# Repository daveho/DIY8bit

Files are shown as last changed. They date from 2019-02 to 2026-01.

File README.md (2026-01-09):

# DIY 8-bit computer video series

This repository has files and resources for the DIY 8-bit computer video series I am working on.

My youtube channel: <https://www.youtube.com/@davehohacks>

DIY 8-bit computer playlist: <https://www.youtube.com/playlist?list=PL9zJKV-F2eMyKY6qdesRQP_mAhBCMSw2T>

Some episodes have a specific subdirectory, e.g., `Episode02` for episode 2.

Feedback is welcome: <mailto:david.hovemeyer@gmail.com>.

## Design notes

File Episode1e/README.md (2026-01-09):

# Episode 1E

In this episode, I implement my
[FPGA VGA text display](https://github.com/daveho/FPGA_VGA)
design as a module for the 6809 system.

Link to video: <https://youtu.be/70fhRooNkK8>

The module (implemented using point to point wiring on
a protoboard):

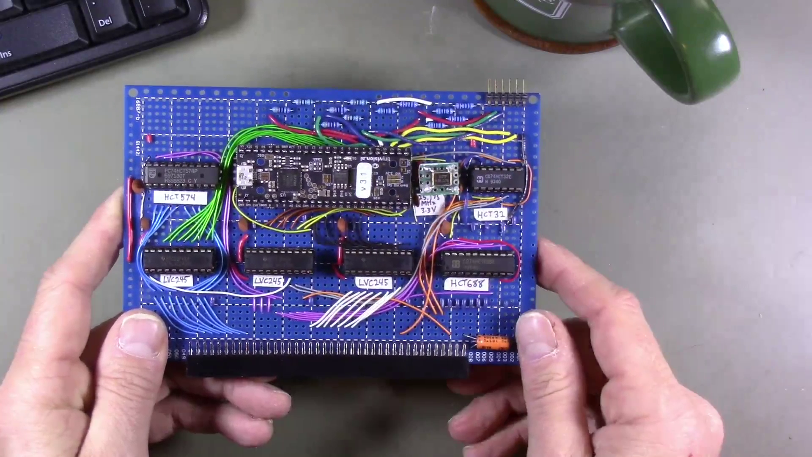
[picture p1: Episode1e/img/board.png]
picture of the VGA text display module


Picture of it working:

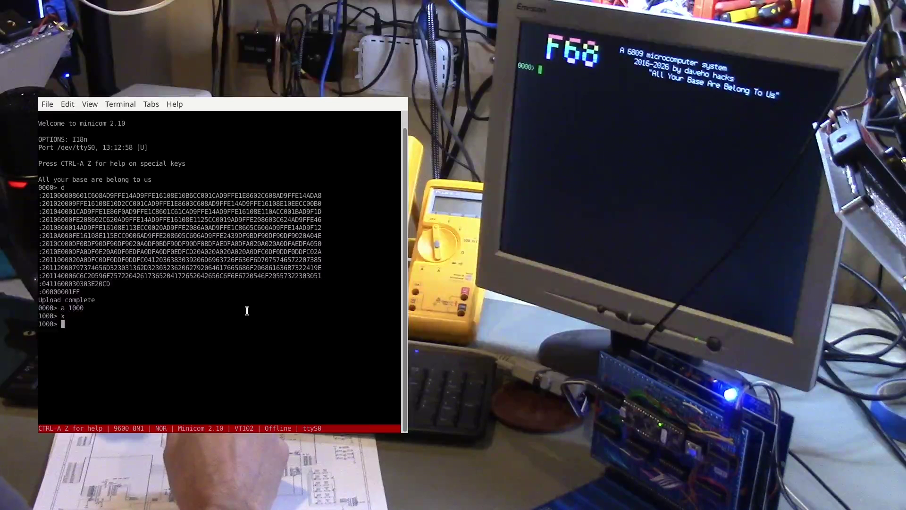
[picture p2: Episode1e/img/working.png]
picture of the text display working


The schematic is the "FPGADisplayController" sheet of
[the main schematic](../HardwareDesign).

The Verilog files are in the [FPGADisplayController](../FPGADisplayController)
directory.

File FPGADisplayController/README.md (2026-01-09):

# FPGA Display Controller

This directory contains the Verilog code for the 80x30 VGA
text display. (The schematic for the module is in the main
schematic, as the "FPGADisplayController" sheet.) It uses the
[Upduino 3](https://tinyvision.ai/products/fpga-development-board-upduino-v3-1)
development board.

To build and upload the design, run the commands

```text
apio verify
apio build
apio upload
```

I wrote a blog post about working with the Upduino 3 on Linux:

<https://daveho.github.io/2021/02/07/upduino3-getting-started-on-linux.html>

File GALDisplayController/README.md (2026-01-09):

# GAL-based VGA text display

This directory has a GAL-based VGA text display controller,
including a schematic and PCB. Although the design worked
as a hand-wired prototype consisting of six boards on a
backplane, I wasn't able to get the PCB version (which uses
mostly surface mount components) working.

The good news is that an FPGA-based version of the display
fully works. The schematic is in the "FPGADisplayController"
sheet of the main schematic in the [HardwareDesign](../HardwareDesign)
directory, and the Verilog code is in the
[FPGADisplayController](../FPGADisplayController) directory.

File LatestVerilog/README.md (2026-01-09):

# DIY 8-bit Computer, Episode 1D

**Update**: A working FPGA text display is now in the main
schematic as the "FPGADisplayController" sheet, and the
Verilog code is in the [FPGADisplayController](../FPGADisplayController)
directory. You can ignore everything in this directory.

The goal of this episode is to fully implement the display controller.
Desired features:

* 100 column by 37 row text mode
* 8x16 font (specifically, the [DOS ISO8 font](https://int10h.org/oldschool-pc-fonts/fontlist/font?ibm_dos_iso8))
* independent foreground and background colors for each displayed character,
  with a 256 color palette chosen from 4096 possible colors (RGB 444 truecolor)

## Status

In the [previous](../Episode1c) I was able to get character rendering to
work. However, it didn't support a full framebuffer, and there was
no support for character foreground and background colors, nor was there
a full framebuffer.

I'm just getting started on implementing the desired features
listed above.

## Experiments

* [Experiment 1](Experiment01): put the font data in SPRAM so that
  more block RAM is available for the framebuffer

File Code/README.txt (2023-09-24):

This directory has all of the code (firmware and programs)
for the F68 microcomputer.

The specific subdirectories are:

Include: assembly code used by both the ROM monitor and
programs is in this directory

Monitor: the ROM monitor, which is programmed to a 28C256
EEPROM and is what boots the microcomputer.

Keyboard: the firmware for the keyboard controller, which is
programmed to an 87C51 or 89C51 microcontroller.

Programs: various 6809 programs that can be assembled into
.hex files and loaded into RAM by the ROM monitor.

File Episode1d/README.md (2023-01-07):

# Episode 1D

Link to video: <https://youtu.be/MCGEp9laRh4>

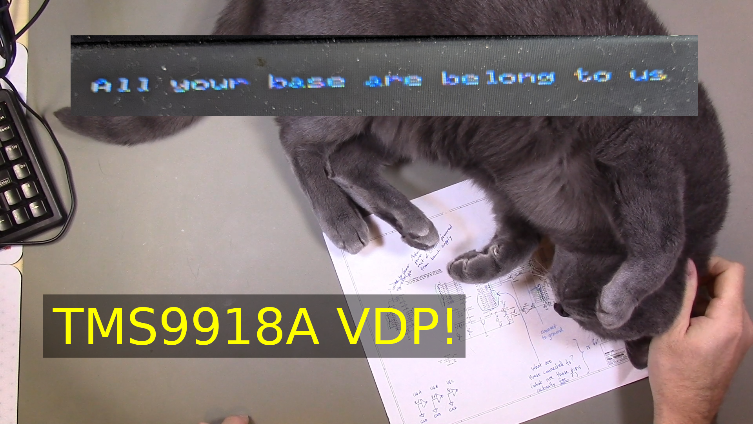
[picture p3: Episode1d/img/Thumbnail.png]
Cute cat picture


The goal of this episode is to experiment with a
[TMS9918A Video Display Processor](https://en.wikipedia.org/wiki/TMS9918)
and to attempt to use it as a display for the 6809 8-bit computer system.

With the TMS9918A providing a display, we're one step closer to the
6809 system being a fully independent computer.

An updated hardware design, including the schematic for the TMS9918A 
module, is in the [HardwareDesign](HardwareDesign) directory.

The updated monitor program, which initializes the TMS9918A and
displays a message, is in the [Code](Code) directory.

The demo circuit shown in the video, which I will be using as the
basis for the TMS9918A module, was created by Dr. Volt:

* Dr. Volt's TMS9918A project on Github: <https://github.com/michalin/TMS9918_Arduino>
* Dr. Volt's youtube channel: <https://www.youtube.com/@DoctorVolt>

I was inspired to try the TMS9918A based on a suggestion from
Troy Schrapel:

* Troy's 6502 system (which uses the TMS9918A): <https://visrealm.github.io/hbc-56/>
* Troy's youtube channel: <https://www.youtube.com/@TroySchrapel>

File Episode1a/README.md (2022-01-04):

# DIY 8-bit computer, Episode 1A

Link to video: <https://youtu.be/MTqwGI0u0LY>

In this video, I develop a host interface for the FPGA-based
display controller I started in [Episode 15](../Episode15).
You should probably watch that episode first!

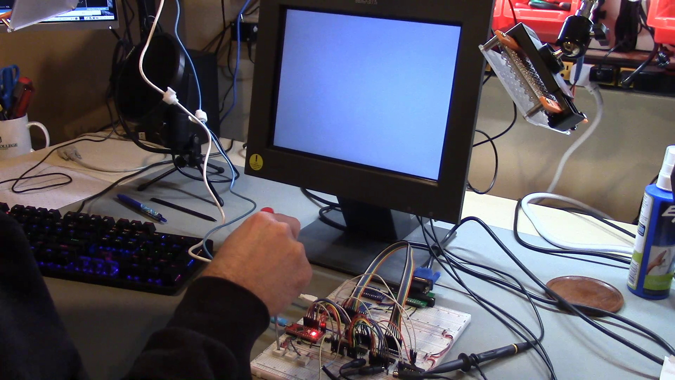
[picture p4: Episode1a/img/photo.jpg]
testing the display controller host interface


The [HardwareDesign](HardwareDesign) directory has the hardware
design (tested and verified working in this Episode.)
The schematics are (of course) developed using [KiCad](https://www.kicad.org/).

In the video, I mention creating a better resistor DAC.
The resistor DAC PCB you can see in the video can be found
here: <https://github.com/daveho/BreadboardDAC>.
I had the PCBs fabbed by [OSHPark](https://oshpark.com/),
and as usual they did an excellent job.  You should be
able to upload [BreadboardDAC.kicad\_pcb](https://github.com/daveho/BreadboardDAC/raw/master/BreadboardDAC.kicad_pcb) to OSHPark directly (no need to generate gerbers.)

The [Experiment01](Experiment01) through [Experiment05](Experiment05)
directories contain the FPGA designs for the various experiments
shown in the video. The FPGA board is an [Upduino 3.0](https://tinyvision.ai/products/upduino-v3-0),
based on the [Lattice ICE40 UP5k](https://www.latticesemi.com/Products/FPGAandCPLD/iCE40UltraPlus)
FPGA. It is programmed using the amazing [IceStorm](http://bygone.clairexen.net/icestorm/)
toolchain developed by [Claire Wolf](https://www.clairexen.net/).
I use [APIO](https://github.com/FPGAwars/apio) to orchestrate the
tools.  You can check out a
[blog post](http://daveho.github.io/2021/02/07/upduino3-getting-started-on-linux.html)
I wrote explaining how to get started programming the Upduino 3.0.
Some of the experiments include an Arduino Nano serving as a
proxy for the host system, in which case you will find an
`ArduinoSketch` directory with the firmware code.

The [Experiment01](Experiment01) directory adds a reset input to
the display controller. This will ensure that the display controller
starts in a known state when the system comes out of reset.

The [Experiment02](Experiment02) directory configures the FPGA with
the inputs and outputs needed to interface with the FIFO used for
communication with the host system, but doesn't actually do anything
with them.

The [Experiment02a](Experiment02a) and [Experiment02b](Experiment02b)
directories are based on Experiment02, but change the PLL configuration
so that different internal clock frequencies are used.

The [Experiment03](Experiment03) directory has the FPGA reading commands
from the host system via the FIFO.

The [Experiment04](Experiment04) directory has the FPGA using the low
4 bits of received commands to control the blue color component of
all generated pixels. The Arduino sents increasing count values,
so we get a nicely annoying flashing effect.

The [Experiment05](Experiment05) directory has the Arduino sending
commands to control the individual red, green, and blue color components
based on values read from three potentiometers connected to analog
inputs 0, 1, and 2.

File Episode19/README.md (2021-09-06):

# DIY 8-bit computer, Episode 19

Link to video: <https://youtu.be/RM4j6294dPY>

In this video, I assemble and test a PCB implementing the interrupt
and keyboard controllers.  I also fix minor issues with the handling
of end of line inputs and cursor movement in the ROM monitor program,
and assemble a new backplane.

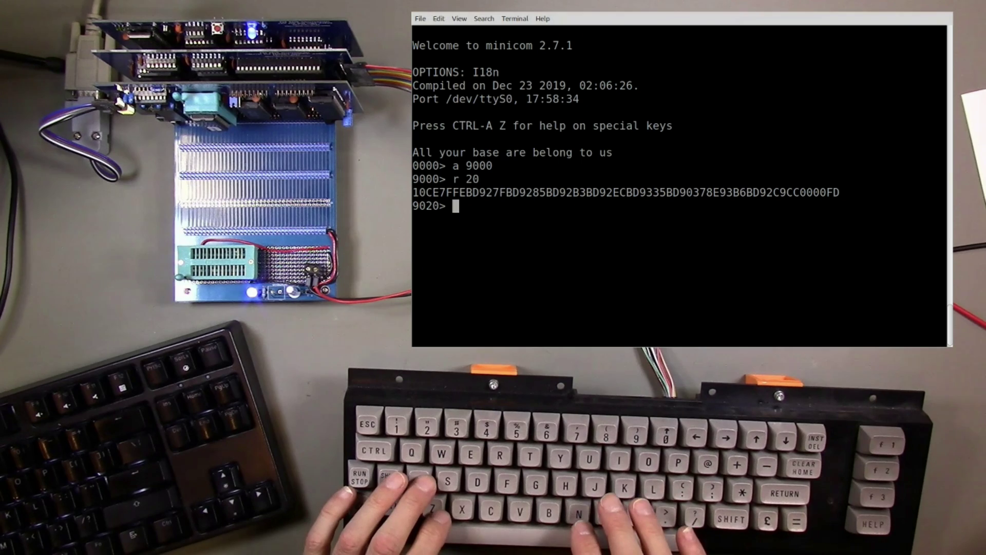
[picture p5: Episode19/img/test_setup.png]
testing the keyboard controller


The [Code](Code) directory has the updated ROM monitor code.

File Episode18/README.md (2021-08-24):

# DIY 8-bit computer, Episode 18

Link to video: <https://youtu.be/xi_Eh6LUsHY>

In this video, I assemble and test a PCB for the memory and peripherals module
for the F68 6809 computer system.  The PCB replaces the original hand-wired
prototype version of the module, and adds support for RS-232 serial
communication using a MAX232 transceiver chip.

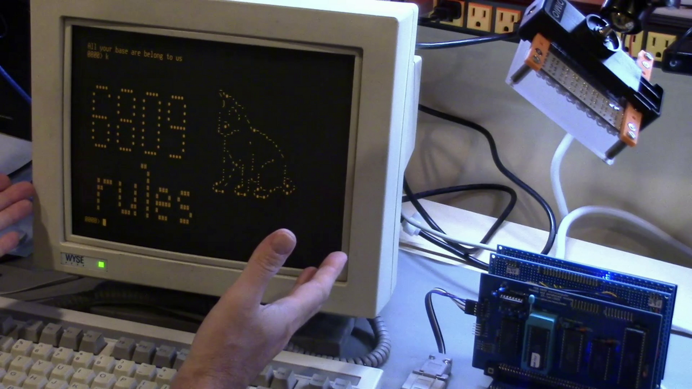
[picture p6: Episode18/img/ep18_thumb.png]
6809 system connected to a serial terminal


The [HardwareDesign](HardwareDesign) directory has the schematics and PCB
designs.  I updated the PCB design for the memory and peripherals module
to fix the minor issue I discovered in the video where one of the clock
inputs of the 82C54 timer/counter chip was not connected.

The [Code](Code) directory has the updated code for the monitor program,
which adds a `k` command to display some sweet ASCII art.

## Serial communication headers

The PCB has two 5-pin headers for serial communication.

The monitor program is hard-coded for 9600 bps, 8N1, so that's what the
remote (communicating) device should be configured for.

### Labeling of pins

Note that the silkscreen markings for the individual pins on the two
serial communications headers (TTL serial and RS-232) are
describing a signal of the *remote* device, i.e., the device that
the 6809 system will be communicating with.  For example, the pin labeled
`Rx` should be connected to the Rx (receive) input on the remote device, and
is driven by the Tx (transmit) pin on the 6809 system's 63B50 UART.

I hope this makes sense!

### TTL serial header

The header labeled "TTL serial" uses standard TTL-level signals.

The TTL serial header may be connected to a USB serial adapter as follows:

TTL serial header pin | USB serial adapter pin
--------------------- | ----------------------
GND                   | GND
RTS                   | RTS
CTS                   | CTS
Rx                    | Rx
Tx                    | Tx

### RS-232 header

The header labeled "RS-232" uses a MAX232 chip for serial communication using
RS-232 level signals.  As with the "TTL serial" header, the silkscreen labels
for the pins refer to the remote device, not the 6809 system.

How these header pins are connected will depend on two factors:

* whether the remote device is DTE (Data Terminal Equipment) or DCE (Data
  Communication Equipment)
* whether the RS-232 cable is straight through or null modem

PCs and serial terminals are both DTE devices.

The following tables show how to write the 5-pin RS-232 header on the PCB
to a 9-pin (D-sub) serial connector.

For connection to a DTE device using a straight-through cable, or a DCE device
using a null modem cable:

RS-232 header pin | Serial connector pin
----------------- | --------------------
GND               | 5
RTS               | 7
CTS               | 8
Rx                | 2
Tx                | 3

For connection to a DCE device using a straight-through cable, or a DTE
device using a null modem cable:

RS-232 header pin | Serial connector pin
----------------- | --------------------
GND               | 5
RTS               | 8
CTS               | 7
Rx                | 3
Tx                | 2

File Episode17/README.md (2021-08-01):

# DIY 8-bit computer, Episode 17

Link to video: <https://youtu.be/EEec0VQM-kc>

This is a quick video in which I test a revised version of the
CPU and glue logic module PCB for the F68 6809-based microcomputer system.
The revision fixes several problems I found with the original board
revision in the [previous episode](../Episode16).

The [HardwareDesign](HardwareDesign) directory has complete schematics and
PCB designs.

Note that the [Mechanical](../Episode16/Mechanical) directory from
the previous episode has the 3D designs for the mounting clips that secure the
backplane connector to the PCB.

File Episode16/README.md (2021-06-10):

# DIY 8-bit computer, Episode 16

Link to video: <https://youtu.be/gSi9ksZn5Jk>

In this video, I choose the name "F68" for the 6809 computer system,
and debug and test a new PCB for the CPU and glue logic module.
There are some mistakes in the PCB layout that cause some problems,
but eventually everything works.

The [HardwareDesign](HardwareDesign) directory has the updated
schematics and the PCB layout.  Note that the [CPUandGlueLogic.kicad\_pcb](CPUandGlueLogic.kicad_pcb)
file has fixes for the PCB layout issues discussed in the episode.
The [gerbers\_cpu](HardwareDesign/gerbers_cpu) subdirectory has the gerber
files for the updated (fixed) board layout. Note: do *not* populate resistor
network R101, it seems to cause problems (as noted towards the end of
the video.)

The [Mechanical](Mechanical) directory has the design for the 3D-printable clips
to more firmly attach the backplane connector (which is a 2x40 right angle female pin header)
to the PCB.

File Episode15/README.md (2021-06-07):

# DIY 8-bit computer, Episode 15

Link to video: <https://youtu.be/5xY3-Er72VU>

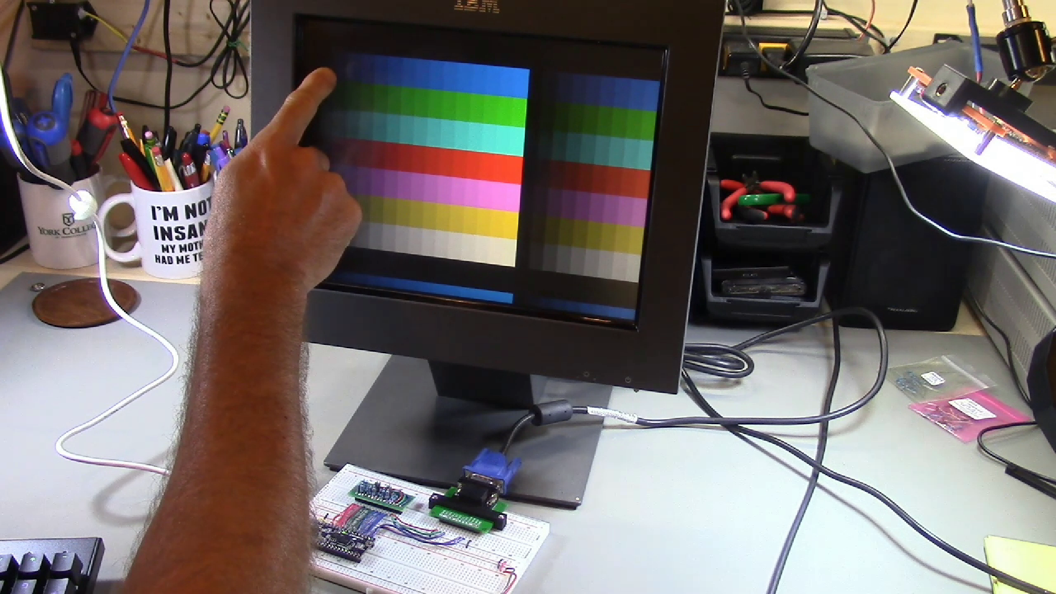
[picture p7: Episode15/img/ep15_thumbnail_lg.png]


In this video, I evaluate possibilities for adding a display to the 8-bit
computer, and perform some initial experiments to generate an 800x600 SVGA
signal using an FPGA.

The FPGA board I am using is the [Upduino 3.0](https://tinyvision.ai/products/upduino-v3-0),
which uses the [Lattice UltraPlus ICE40UP5K](https://www.latticesemi.com/en/Products/FPGAandCPLD/iCE40UltraPlus)
FPGA.  One great advantage of this FPGA family is that it can be programmed using
the Open Source [IceStorm](http://www.clifford.at/icestorm/) toolchain.
I am using [apio](https://github.com/FPGAwars/apio) as a front-end for the
FPGA tools.

I wrote a blog post describing how to set up a development environment for
the Upduino 3.0: <https://daveho.github.io/2021/02/07/upduino3-getting-started-on-linux.html>

The schematic for the test circuit is in the [HardwareDesign](HardwareDesign)
directory, in the sheet called `Display`.  There is a PDF of the schematic,
[F68.pdf](HardwareDesign/F68.pdf).  (The overall system is going to be called
"F68", I will talk about this in a future video.)

The following directories have code for the various FPGA experiments:

* [Experiment01](Experiment01): generate a 6 MHz square wave using the
  internal high-frequency oscillator
* [Experiment02](Experiment02): generate a 1.875 MHz square wave using
  the internal high-freqency oscillator and a PLL
* [Experiment03](Experiment03): generate a 6 MHz square wave using the
  on-board 12 MHz oscillator (the internal high-frequency oscillator is
  not very accurate)
* [Experiment04](Experiment04): generate a 1.875 MHz square wave using
  the 12 MHz oscillator and a global clock buffer
* [Experiment05](Experiment05): generate 800x600 60 video displaying
  a solid color
* [Experiment06](Experiment06): generate a 800x600 test pattern showing
  color gradients, in order to evaluate the 4 bit resistor DACs used for
  converting the digital outputs to analog color voltages
  (this is what you see in the photo above)

Other directories:

* [DAC](DAC): has a [Qucs](http://qucs.sourceforge.net/) simulation of the
  resistor DAC design, and a [Gnumeric](http://www.gnumeric.org/) spreadsheet
  showing the voltages generated by a test circuit for each digital input
  value
* [Mechanical](Mechanical): has a 3D-printable bracket that attaches to the
  VGA breakout board I'm using in order to give it some additional support
  on the breadboard (to avoid putting unnecessary stress on the header pins)

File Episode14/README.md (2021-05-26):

# DIY 8-bit computer, Episode 14

Link to video: <https://youtu.be/gVFuNtl8WqU>

In this video, I present plans for an enclosure for the 8 bit computer system,
and build a frame for the enclosure which includes a card cage to stabilze
the backplane cards.

The frame for the enclosure is built using 15x15mm aluminum extrusions, specifically
[MakerBeam XL](https://www.makerbeam.com/makerbeamxl/).  [OpenBeam](https://www.makerbeam.com/openbeam/)
is the same profile, but does not have threaded holes at the ends of the beam (which are needed
to use the corner connectors.)

Pictures of the frame:

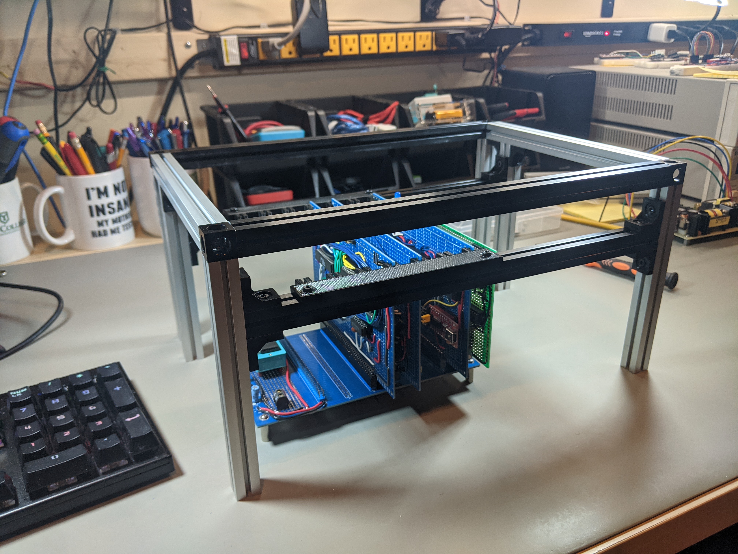
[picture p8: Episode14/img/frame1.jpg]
enclosure frame


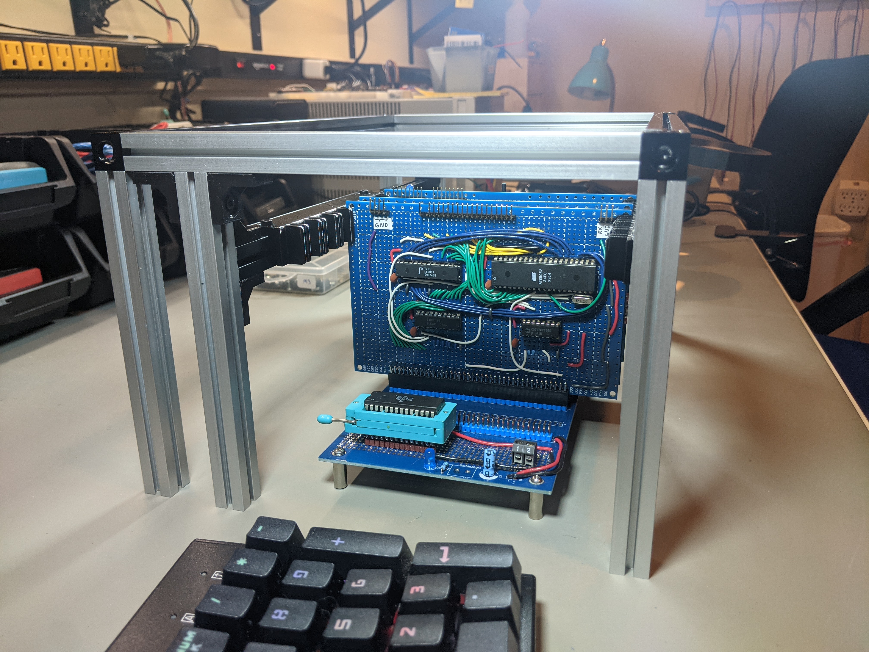
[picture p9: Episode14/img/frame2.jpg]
enclosure frame


Two 3D printed parts are used.

* [lbracket.stl](lbracket.stl): OpenBeam corner brace, from <https://www.thingiverse.com/thing:29794>, design by [brucethehoon](https://www.thingiverse.com/brucethehoon), [CC-BY-SA 3.0](https://creativecommons.org/licenses/by-sa/3.0/)
* [CardGuide.stl](CardGuide.stl)/[CardGuide.scad](CardGuide.scad): card guide, designed by [me](https://github.com/daveho), [CC-BY-SA 3.0](https://creativecommons.org/licenses/by-sa/3.0/)

Parts list for frame:

Quantity | Description/link
:------: | ----------------
6        | [150mm MakerBeam XL](https://www.amazon.com/MakerBeam-XL-anodized-150x15x15mm-103150/dp/B06XJ4FV75)
2        | [200mm MakerBeam XL](https://www.amazon.com/MakerBeam-XL-Anodized-200x15x15mm-Pieces/dp/B06XHQH9WH)
4        | [300mm MakerBeam XL](https://www.amazon.com/MakerBeam-300mm-beam-black-anodised/dp/B00G2DNU4M)
4        | [MakerBeam XL corner cube](https://www.amazon.com/Makerbeam-XL-Corner-Black-15x15x15mm/dp/B06XJ3RYZ4)
40       | [6mm M3 bolt](https://www.amazon.com/gp/product/B07CMRQ3TB)
40       | [Square 5x5x2 mm M3 nut](https://www.amazon.com/gp/product/B089Q6C4CM)
12       | [3D printed OpenBeam corner brace](lbracket.stl)
2        | [Card Guide](CardGuide.stl)

Note that you can use the [MakerBeam XL T-Slot nuts](https://www.amazon.com/gp/product/B06XHQHD4H)
rather than the square M3 nuts, but they are very expensive.

Here is a 3D-printable corner cube, which might be worth considering because the
MakerBeam XL metal ones are expensive: <https://www.thingiverse.com/thing:3189420>

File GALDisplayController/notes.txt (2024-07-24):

June 18, 2024

VCOUNT_INCR input of VCount module should be driven by HEndPulse signal
rather than HBeginPulse signal. This will allow once-per-line register
updates in the Readout module to happen before VCOUNT is incremented.
This will require a hardware mod!

June 19, 2024

Need to update VCntCtrl.pld to generate VEActive (VEndActive) signal
(pin 20.)

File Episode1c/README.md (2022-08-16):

# Episode 1C

Link to video: <https://youtu.be/Fw6ido_NeqQ>

The goal of this episode is to have the display controller display
characters as 800x600 SVGA video, with the Arduino (standing in for
the host system) uploading font and character data to the
display controller's block RAM.

Spoiler: it worked.

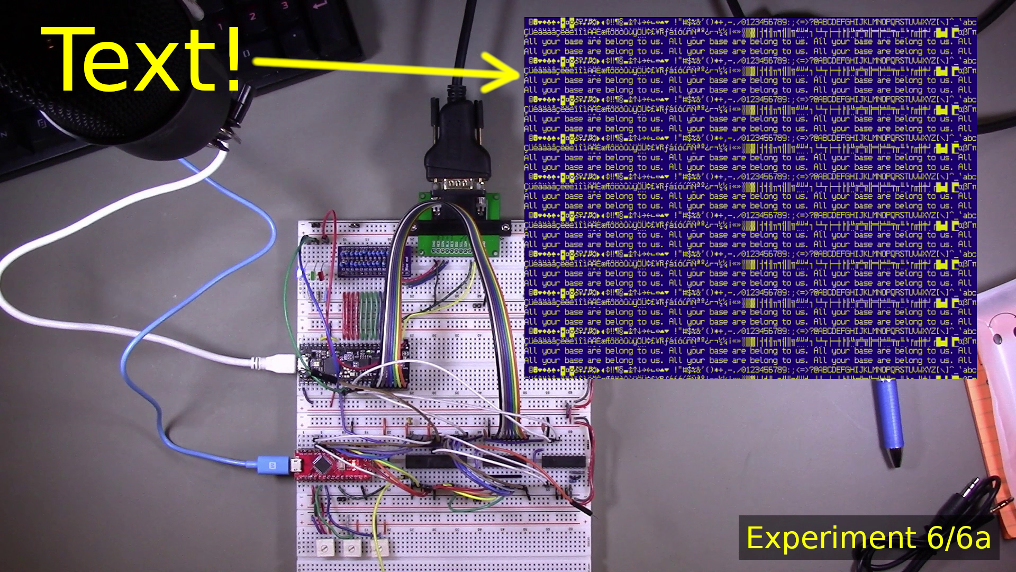
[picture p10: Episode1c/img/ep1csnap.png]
snapshot from the video


The experiment directories (linked below) have the Verilog and Arduino
code.  The hardware design the same as [Episode 1A](../Episode1a).

## Summary of experiments

[Experiment 1](Experiment01): Change core FPGA clock frequency to 39.75 MHz because
an update to the IceStorm tools caused the design to not synthesize
correctly at 80 MHz.  This is ok, since pipelining should completely
obviate the need for a fast clock.

[Experiment 2](Experiment02): Generate 8 pixels at a time from a single 8 bit register.
The idea is that this is the last stage in the video output.
(Eventually we'll need to add support for foreground/background
colors, but they can just be stored in a different register.)

[Experiment 3](Experiment03): Begin to implement a command protocol. The basic format
is a single command byte followed by 1 or more additional data bytes.
This required quite a bit of time to get working because the
`shared_reg` module had a bug where the consumer would see a data
byte twice due to the way the data available flag was updated.
Was able to figure this out using the oscilloscope: it was clear
that the same data byte was being consumed twice.

[Experiment 4](Experiment04): Have the host upload 8x16 VGA font data to block RAM.

[Experiment 5](Experiment05): Have the host upload character data to block RAM, and
attempt to render it as characters. This *sort of* works. Definitely
some recognizable characters are displayed, but they're not quite in
the expected places on the screen.

[Experiment 6](Experiment06): try to get all of the characters to display at precisely
the correct locations.

Experiment 6a: this was done to support Experiment 6. It became clear
that the hsync and vsync generation and hcount/vcount generation was
not placing pixels in the correct locations. In this experiment, the
output was a grid with horizontal and vertical lines every 16 pixels.
By adjusting hsync and vcount (as exposed to the main module), we were
able to make hcount==0 the exact left row, and vcount==0 the exact
top row. (I think! It still seems like only 799 columns are being
displayed.)

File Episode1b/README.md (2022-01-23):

# DIY 8-bit computer, Episode 1B

Link to video: <https://youtu.be/UeyVLJ2qZhI>

In this video, I discuss an approach for making the display controller
design work.  (We started the display controller in
[Epsiode15](../Episode15) and continued it in [Episode1A](../Episode1a).)
We also incorporate a block RAM into the design.

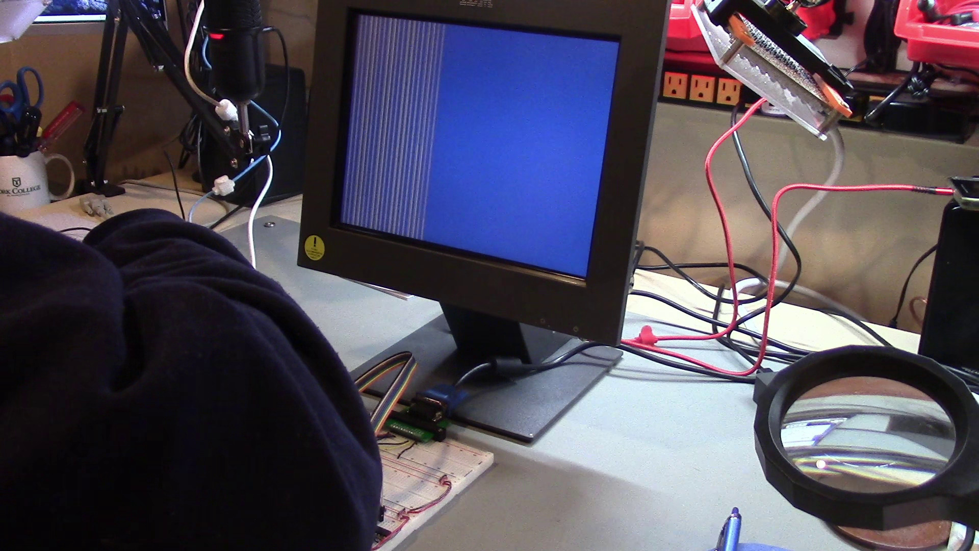
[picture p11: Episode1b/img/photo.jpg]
displaying ugly lines on a VGA monitor


The hardware design is the same as in the [previous episode](../Episode1a).

The [Experiment01](Experiment01) and [Experiment02](Experiment02) directories
were intermediate stages of a general cleanup and modularization of the
Verilog code for the display controller.

The [Experiment03](Experiment03) directory has the Verilog code which
places command bytes sent by the simulated host system into a block RAM,
which in turn is used to generate a pattern of foreground and background
pixels on each generated raster line.  Even though it's not too impressive
to look at, it proves that we can get data into the FPGA and use it to
render display output, which is a pretty significant step.

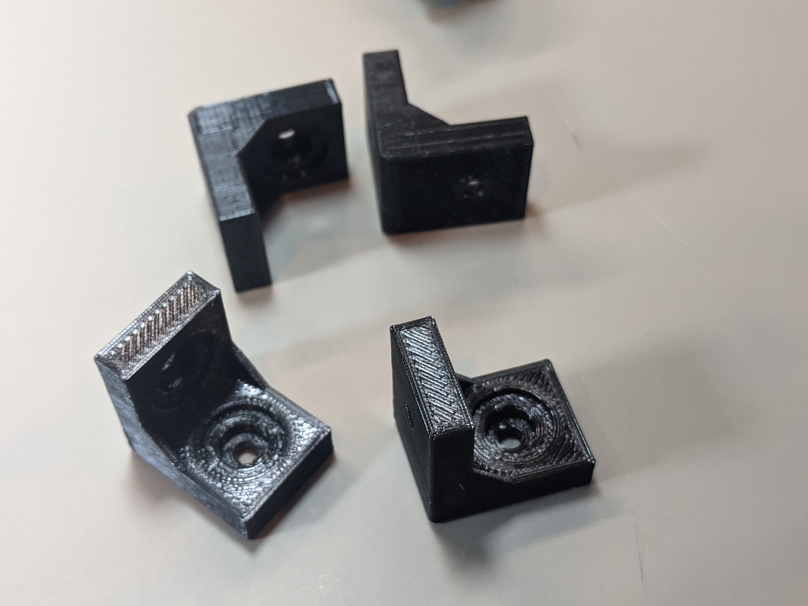
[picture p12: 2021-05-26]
Mechanical/img/right_angle.jpg

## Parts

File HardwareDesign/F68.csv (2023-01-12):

Source: | /home/daveho/git/DIY8bit/HardwareDesign/F68.kicad_sch
Date: | Thu 12 Jan 2023 06:23:54 PM EST
Tool: | Eeschema 6.0.10-86aedd382b~118~ubuntu20.04.1
Generator: | /usr/share/kicad/plugins/bom_csv_grouped_by_value.py
Component Count: | 175
Individual Components:
Item | Qty | Reference(s) | Value | LibPart | Footprint | Datasheet | Comment | Field4 | Field5 | Field6 | Field7 | Field8 | MANUFACTURER | MAXIMUM_PACKAGE_HEIGHT | PARTREV | STANDARD
 |  | C001 | 22μF | device:CP | Capacitor_THT:CP_Radial_D6.3mm_P2.50mm
 |  | C101 | 0.1 uF | device:C | Capacitor_THT:C_Disc_D5.0mm_W2.5mm_P2.50mm
 |  | C102 | 0.1 uF | device:C | Capacitor_THT:C_Disc_D5.0mm_W2.5mm_P2.50mm
 |  | C103 | 0.1 uF | device:C | Capacitor_THT:C_Disc_D5.0mm_W2.5mm_P2.50mm
 |  | C104 | 0.1 uF | device:C | Capacitor_THT:C_Disc_D5.0mm_W2.5mm_P2.50mm
 |  | C105 | 0.1 uF | device:C | Capacitor_THT:C_Disc_D5.0mm_W2.5mm_P2.50mm
 |  | C106 | 0.1 uF | device:C | Capacitor_THT:C_Disc_D5.0mm_W2.5mm_P2.50mm
 |  | C107 | 0.1 uF | device:C | Capacitor_THT:C_Disc_D5.0mm_W2.5mm_P2.50mm
 |  | C108 | 0.1 uF | device:C | Capacitor_THT:C_Disc_D5.0mm_W2.5mm_P2.50mm
 |  | C109 | 0.1 uF | device:C | Capacitor_THT:C_Disc_D5.0mm_W2.5mm_P2.50mm
 |  | C110 | 0.1 uF | device:C | Capacitor_THT:C_Disc_D5.0mm_W2.5mm_P2.50mm
 |  | C111 | 0.1 uF | device:C | Capacitor_THT:C_Disc_D5.0mm_W2.5mm_P2.50mm
 |  | C113 | 22 pF | device:C | Capacitor_THT:C_Disc_D3.8mm_W2.6mm_P2.50mm
 |  | C114 | 22 pF | device:C | Capacitor_THT:C_Disc_D3.8mm_W2.6mm_P2.50mm
 |  | C200 | 0.1 uF | device:C | Capacitor_THT:C_Disc_D5.0mm_W2.5mm_P2.50mm
 |  | C201 | 0.1 uF | device:C | Capacitor_THT:C_Disc_D5.0mm_W2.5mm_P2.50mm
 |  | C301 | 0.1 μF | device:C | Capacitor_THT:C_Disc_D5.0mm_W2.5mm_P2.50mm
 |  | C302 | 0.1 μF | device:C | Capacitor_THT:C_Disc_D5.0mm_W2.5mm_P2.50mm
 |  | C303 | 0.1 μF | device:C | Capacitor_THT:C_Disc_D5.0mm_W2.5mm_P2.50mm
 |  | C304 | 1μF | device:CP | Capacitor_THT:CP_Radial_Tantal_D5.0mm_P5.00mm
 |  | C305 | 1μF | device:CP | Capacitor_THT:CP_Radial_Tantal_D5.0mm_P5.00mm
 |  | C306 | 1μF | device:CP | Capacitor_THT:CP_Radial_Tantal_D5.0mm_P5.00mm
 |  | C307 | 1μF | device:CP | Capacitor_THT:CP_Radial_Tantal_D5.0mm_P5.00mm
 |  | C308 | 1μF | device:CP | Capacitor_THT:CP_Radial_Tantal_D5.0mm_P5.00mm
 |  | C401 | 0.1 μF | device:C | Capacitor_THT:C_Disc_D5.0mm_W2.5mm_P2.50mm
 |  | C402 | 0.1 μF | device:C | Capacitor_THT:C_Disc_D5.0mm_W2.5mm_P2.50mm
 |  | C403 | 0.1 μF | device:C | Capacitor_THT:C_Disc_D5.0mm_W2.5mm_P2.50mm
 |  | C404 | 0.1 μF | device:C | Capacitor_THT:C_Disc_D5.0mm_W2.5mm_P2.50mm
 |  | C405 | 0.1 μF | device:C | Capacitor_THT:C_Disc_D5.0mm_W2.5mm_P2.50mm
 |  | C406 | 0.1 μF | device:C | Capacitor_THT:C_Disc_D5.0mm_W2.5mm_P2.50mm
 |  | C407 | 0.1 μF | device:C | Capacitor_THT:C_Disc_D5.0mm_W2.5mm_P2.50mm
 |  | C501 | 0.1 μF | device:C | Capacitor_THT:C_Disc_D5.0mm_W2.5mm_P2.50mm
 |  | C502 | 0.1 μF | device:C | Capacitor_THT:C_Disc_D5.0mm_W2.5mm_P2.50mm
 |  | C503 | 0.1 μF | device:C | Capacitor_THT:C_Disc_D5.0mm_W2.5mm_P2.50mm
 |  | C504 | 0.1 μF | device:C | Capacitor_THT:C_Disc_D5.0mm_W2.5mm_P2.50mm
 |  | C505 | 30pF | device:C | Capacitor_THT:C_Disc_D3.8mm_W2.6mm_P2.50mm
 |  | C506 | 30pF | device:C | Capacitor_THT:C_Disc_D3.8mm_W2.6mm_P2.50mm
 |  | C701 | 100 nF | device:C | Capacitor_THT:C_Disc_D3.4mm_W2.1mm_P2.50mm
 |  | C702 | 100 nF | device:C | Capacitor_THT:C_Disc_D3.4mm_W2.1mm_P2.50mm
 |  | C703 | 100 nF | device:C | Capacitor_THT:C_Disc_D3.4mm_W2.1mm_P2.50mm
 |  | C704 | 100 nF | device:C | Capacitor_THT:C_Disc_D3.4mm_W2.1mm_P2.50mm
 |  | C705 | 100 nF | device:C | Capacitor_THT:C_Disc_D3.4mm_W2.1mm_P2.50mm
 |  | C706 | 100 nF | device:C | Capacitor_THT:C_Disc_D3.4mm_W2.1mm_P2.50mm
 |  | C707 | 100 nF | device:C | Capacitor_THT:C_Disc_D3.4mm_W2.1mm_P2.50mm
 |  | C710 | 22 pF | device:C | Capacitor_THT:C_Disc_D3.4mm_W2.1mm_P2.50mm
 |  | C711 | 22 pF | device:C | Capacitor_THT:C_Disc_D3.4mm_W2.1mm_P2.50mm
 |  | C801 | 100 nF | device:C | Capacitor_THT:C_Disc_D3.4mm_W2.1mm_P2.50mm
 |  | C802 | 100 nF | device:C | Capacitor_THT:C_Disc_D3.4mm_W2.1mm_P2.50mm
 |  | C803 | 100 nF | device:C | Capacitor_THT:C_Disc_D3.4mm_W2.1mm_P2.50mm
 |  | C804 | 100 nF | device:C | Capacitor_THT:C_Disc_D3.4mm_W2.1mm_P2.50mm
 |  | C805 | 2.2 uF | device:C | Capacitor_THT:C_Rect_L7.0mm_W4.5mm_P5.00mm
 |  | C806 | 2.2 uF | device:C | Capacitor_THT:C_Rect_L7.0mm_W4.5mm_P5.00mm
 |  | D100 | LED | device:LED | LED_THT:LED_D5.0mm
 |  | D601 | LED | device:LED | LED_THT:LED_D5.0mm
 |  | D602 | LED | device:LED | LED_THT:LED_D5.0mm
 |  | D603 | LED | device:LED | LED_THT:LED_D5.0mm
 |  | J001 | Conn_02x40_Odd_Even | Connector_Generic:Conn_02x40_Odd_Even | Connector_PinHeader_2.54mm:PinHeader_2x40_P2.54mm_Vertical | ~
 |  | J100 | Conn_01x02 | Connector_Generic:Conn_01x02 | Connector_PinHeader_2.54mm:PinHeader_1x02_P2.54mm_Vertical | ~
 |  | J201 | Conn_01x03 | Connector_Generic:Conn_01x03 | Connector_PinHeader_2.54mm:PinHeader_1x03_P2.54mm_Vertical | ~
 |  | J303 | Conn_01x05 | Connector_Generic:Conn_01x05 | Connector_PinHeader_2.54mm:PinHeader_1x05_P2.54mm_Vertical | ~
 |  | J304 | Conn_01x05 | Connector_Generic:Conn_01x05 | Connector_PinHeader_2.54mm:PinHeader_1x05_P2.54mm_Vertical | ~
 |  | J305 | Conn_01x09 | Connector_Generic:Conn_01x09 | Connector_PinHeader_2.54mm:PinHeader_1x09_P2.54mm_Vertical | ~
 |  | J306 | Conn_01x09 | Connector_Generic:Conn_01x09 | Connector_PinHeader_2.54mm:PinHeader_1x09_P2.54mm_Vertical | ~
 |  | J501 | Conn_01x20 | Connector_Generic:Conn_01x20 | Connector_PinHeader_2.54mm:PinHeader_1x20_P2.54mm_Vertical | ~
 |  | J503 | Conn_01x02 | Connector_Generic:Conn_01x02 | Connector_PinHeader_2.54mm:PinHeader_1x02_P2.54mm_Vertical | ~
 |  | J601 | Conn_01x12 | Connector_Generic:Conn_01x12 | Connector_PinHeader_2.54mm:PinHeader_1x12_P2.54mm_Vertical | ~
 |  | J701 | RCJ-044 | RCJ-044:RCJ-044 | CUI_RCJ-044:CUI_RCJ-044 |  |  |  |  |  |  |  | CUI Devices | 11.6 mm | 1.02 | Manufacturer Recommendations
 |  | J702 | Conn_01x02 | Connector_Generic:Conn_01x02 | Connector_PinHeader_2.54mm:PinHeader_1x02_P2.54mm_Vertical | ~
 |  | J801 | Conn_01x02 | Connector_Generic:Conn_01x02 | Connector_PinHeader_2.54mm:PinHeader_1x02_P2.54mm_Vertical | ~
 |  | J802 | Conn_02x09_Odd_Even | Connector_Generic:Conn_02x09_Odd_Even | Connector_PinHeader_2.54mm:PinHeader_2x09_P2.54mm_Vertical | ~
 |  | J803 | SJ1-3525N | SJ1-3525N:SJ1-3525N | CUI_SJ1-3525N |  |  |  |  |  |  |  | CUI |  | 1.02 | Manufacturer recommendation
 |  | Q701 | 2N4401 | device:Q_NPN_EBC | Package_TO_SOT_THT:TO-92_HandSolder
 |  | R100 | R | device:R | Resistor_THT:R_Axial_DIN0204_L3.6mm_D1.6mm_P7.62mm_Horizontal
 |  | R101 | 4k7 | device:R | Resistor_THT:R_Axial_DIN0204_L3.6mm_D1.6mm_P7.62mm_Horizontal
 |  | R102 | 4k7 | device:R | Resistor_THT:R_Axial_DIN0204_L3.6mm_D1.6mm_P7.62mm_Horizontal
 |  | R103 | 4k7 | device:R | Resistor_THT:R_Axial_DIN0204_L3.6mm_D1.6mm_P7.62mm_Horizontal
 |  | R301 | 2k7 | device:R | Resistor_THT:R_Axial_DIN0204_L3.6mm_D1.6mm_P7.62mm_Horizontal
 |  | R302 | 2k7 | device:R | Resistor_THT:R_Axial_DIN0204_L3.6mm_D1.6mm_P7.62mm_Horizontal
 |  | R303 | 2k7 | device:R | Resistor_THT:R_Axial_DIN0204_L3.6mm_D1.6mm_P7.62mm_Horizontal
 |  | R304 | 2k7 | device:R | Resistor_THT:R_Axial_DIN0204_L3.6mm_D1.6mm_P7.62mm_Horizontal
 |  | R305 | 10k | device:R | Resistor_THT:R_Axial_DIN0204_L3.6mm_D1.6mm_P7.62mm_Horizontal
 |  | R401 | 4k7 | device:R | Resistor_THT:R_Axial_DIN0204_L3.6mm_D1.6mm_P7.62mm_Horizontal
 |  | R402 | 4k7 | device:R | Resistor_THT:R_Axial_DIN0204_L3.6mm_D1.6mm_P7.62mm_Horizontal
 |  | R403 | 4k7 | device:R | Resistor_THT:R_Axial_DIN0204_L3.6mm_D1.6mm_P7.62mm_Horizontal
 |  | R404 | 4k7 | device:R | Resistor_THT:R_Axial_DIN0204_L3.6mm_D1.6mm_P7.62mm_Horizontal
 |  | R405 | 4k7 | device:R | Resistor_THT:R_Axial_DIN0204_L3.6mm_D1.6mm_P7.62mm_Horizontal
 |  | R406 | 4k7 | device:R | Resistor_THT:R_Axial_DIN0204_L3.6mm_D1.6mm_P7.62mm_Horizontal
 |  | R407 | 4k7 | device:R | Resistor_THT:R_Axial_DIN0204_L3.6mm_D1.6mm_P7.62mm_Horizontal
 |  | R601 | 430 | device:R | Resistor_THT:R_Axial_DIN0204_L3.6mm_D1.6mm_P7.62mm_Horizontal
 |  | R602 | 82 | device:R | Resistor_THT:R_Axial_DIN0204_L3.6mm_D1.6mm_P7.62mm_Horizontal
 |  | R603 | 1k | device:R | Resistor_THT:R_Axial_DIN0204_L3.6mm_D1.6mm_P7.62mm_Horizontal
 |  | R604 | 24 | device:R | Resistor_THT:R_Axial_DIN0204_L3.6mm_D1.6mm_P7.62mm_Horizontal
 |  | R605 | 2k | device:R | Resistor_THT:R_Axial_DIN0204_L3.6mm_D1.6mm_P7.62mm_Horizontal
 |  | R606 | 50 | device:R | Resistor_THT:R_Axial_DIN0204_L3.6mm_D1.6mm_P7.62mm_Horizontal
 |  | R607 | 3k9 | device:R | Resistor_THT:R_Axial_DIN0204_L3.6mm_D1.6mm_P7.62mm_Horizontal
 |  | R608 | 200 | device:R | Resistor_THT:R_Axial_DIN0204_L3.6mm_D1.6mm_P7.62mm_Horizontal
 |  | R609 | 430 | device:R | Resistor_THT:R_Axial_DIN0204_L3.6mm_D1.6mm_P7.62mm_Horizontal
 |  | R610 | 82 | device:R | Resistor_THT:R_Axial_DIN0204_L3.6mm_D1.6mm_P7.62mm_Horizontal
 |  | R611 | 1k | device:R | Resistor_THT:R_Axial_DIN0204_L3.6mm_D1.6mm_P7.62mm_Horizontal
 |  | R612 | 24 | device:R | Resistor_THT:R_Axial_DIN0204_L3.6mm_D1.6mm_P7.62mm_Horizontal
 |  | R613 | 2k | device:R | Resistor_THT:R_Axial_DIN0204_L3.6mm_D1.6mm_P7.62mm_Horizontal
 |  | R614 | 50 | device:R | Resistor_THT:R_Axial_DIN0204_L3.6mm_D1.6mm_P7.62mm_Horizontal
 |  | R615 | 3k9 | device:R | Resistor_THT:R_Axial_DIN0204_L3.6mm_D1.6mm_P7.62mm_Horizontal
 |  | R616 | 200 | device:R | Resistor_THT:R_Axial_DIN0204_L3.6mm_D1.6mm_P7.62mm_Horizontal
 |  | R617 | 430 | device:R | Resistor_THT:R_Axial_DIN0204_L3.6mm_D1.6mm_P7.62mm_Horizontal
 |  | R618 | 82 | device:R | Resistor_THT:R_Axial_DIN0204_L3.6mm_D1.6mm_P7.62mm_Horizontal
 |  | R619 | 1k | device:R | Resistor_THT:R_Axial_DIN0204_L3.6mm_D1.6mm_P7.62mm_Horizontal
 |  | R620 | 24 | device:R | Resistor_THT:R_Axial_DIN0204_L3.6mm_D1.6mm_P7.62mm_Horizontal
 |  | R621 | 2k | device:R | Resistor_THT:R_Axial_DIN0204_L3.6mm_D1.6mm_P7.62mm_Horizontal
 |  | R622 | 50 | device:R | Resistor_THT:R_Axial_DIN0204_L3.6mm_D1.6mm_P7.62mm_Horizontal
 |  | R623 | 3k9 | device:R | Resistor_THT:R_Axial_DIN0204_L3.6mm_D1.6mm_P7.62mm_Horizontal
 |  | R624 | 200 | device:R | Resistor_THT:R_Axial_DIN0204_L3.6mm_D1.6mm_P7.62mm_Horizontal
 |  | R625 | R | device:R | Resistor_THT:R_Axial_DIN0207_L6.3mm_D2.5mm_P7.62mm_Horizontal
 |  | R626 | R | device:R | Resistor_THT:R_Axial_DIN0207_L6.3mm_D2.5mm_P7.62mm_Horizontal
 |  | R627 | R | device:R | Resistor_THT:R_Axial_DIN0207_L6.3mm_D2.5mm_P7.62mm_Horizontal
 |  | R701 | 470 | device:R | Resistor_THT:R_Axial_DIN0207_L6.3mm_D2.5mm_P7.62mm_Horizontal
 |  | R702 | 1k | device:R | Resistor_THT:R_Axial_DIN0207_L6.3mm_D2.5mm_P7.62mm_Horizontal
 |  | R801 | 3k | Device:R | Resistor_THT:R_Axial_DIN0207_L6.3mm_D2.5mm_P7.62mm_Horizontal | ~
 |  | R802 | 3k | Device:R | Resistor_THT:R_Axial_DIN0207_L6.3mm_D2.5mm_P7.62mm_Horizontal | ~
 |  | R803 | 3k | Device:R | Resistor_THT:R_Axial_DIN0207_L6.3mm_D2.5mm_P7.62mm_Horizontal | ~
 |  | R804 | 1k | device:R | Resistor_THT:R_Axial_DIN0207_L6.3mm_D2.5mm_P7.62mm_Horizontal
 |  | R805 | 1k | device:R | Resistor_THT:R_Axial_DIN0207_L6.3mm_D2.5mm_P7.62mm_Horizontal
 |  | R806 | 1k | device:R | Resistor_THT:R_Axial_DIN0207_L6.3mm_D2.5mm_P7.62mm_Horizontal
 |  | R807 | 1k | device:R | Resistor_THT:R_Axial_DIN0207_L6.3mm_D2.5mm_P7.62mm_Horizontal
 |  | RN101 | 4k7 | device:R_Network08 | Resistor_THT:R_Array_SIP9
 |  | RN501 | R_Network08 | device:R_Network08 | Resistor_THT:R_Array_SIP9
 |  | RN601 | 10k | device:R_Network08 | Resistors_THT:R_Array_SIP9
 |  | S100 | 1-1825027-2 | 1-1825027-2:1-1825027-2 | SW_1-1825027-2:SW_1-1825027-2 |  | 1-1825027-2
 |  | TB605 | ARDUINO_NANO | ARDUINO_NANO:ARDUINO_NANO | SHIELD_ARDUINO_NANO | DFRobot |  | Dev.kit: Arduino; UART; ICSP, USB B mini, pin strips | None | None | ARDUINO NANO | Unavailable
 |  | U101 | 74HCT245 | 74xx:74HC245 | Package_DIP:DIP-20_W7.62mm_Socket
 |  | U102 | 74HCT245 | 74xx:74HC245 | Package_DIP:DIP-20_W7.62mm_Socket
 |  | U103 | 74HCT245 | 74xx:74HC245 | Package_DIP:DIP-20_W7.62mm_Socket
 |  | U104 | 74HCT365 | 74xx:74LS365 | Package_DIP:DIP-16_W7.62mm_Socket
 |  | U105 | MAX708 | ya68k:MAX708 | Package_DIP:DIP-8_W7.62mm_Socket
 |  | U106 | HD6809 | HD6809:HD6809 | Package_DIP:DIP-40_W15.24mm_Socket | DOCUMENTATION
 |  | U107 | 74HCT00 | 74xx:74HC00 | Package_DIP:DIP-14_W7.62mm_Socket
 |  | U108 | 74HCT27 | 74xx:74LS27 | Package_DIP:DIP-14_W7.62mm_Socket
 |  | U109 | 74HCT138 | 74xx:74LS138 | Package_DIP:DIP-16_W7.62mm_Socket
 |  | U110 | 74HCT138 | 74xx:74LS138 | Package_DIP:DIP-16_W7.62mm_Socket
 |  | U111 | 74HCT138 | 74xx:74LS138 | Package_DIP:DIP-16_W7.62mm_Socket
 |  | U200 | 28C256 | memory:28C256 | Socket:DIP_Socket-28_W11.9_W12.7_W15.24_W17.78_W18.5_3M_228-1277-00-0602J
 |  | U201 | HM62256BLP-7SL | memory:HM62256BLP-7SL | Package_DIP:DIP-28_W15.24mm_Socket
 |  | U301 | 82C55A | Interface:82C55A | Package_DIP:DIP-40_W15.24mm_Socket | http://jap.hu/electronic/8255.pdf
 |  | U302 | 82C54 | intel:82C54 | Package_DIP:DIP-24_W15.24mm_Socket | http://download.intel.com/design/archives/periphrl/docs/23124406.pdf
 |  | U303 | MC6850 | MC6850:MC6850 | Package_DIP:DIP-24_W15.24mm_Socket | DOCUMENTATION
 |  | U304 | MAX232CPE | MAX232CPE:MAX232CPE | Package_DIP:DIP-16_W7.62mm_Socket
 |  | U401 | 74HCT74 | 74xx:74LS74 | Package_DIP:DIP-14_W7.62mm_Socket
 |  | U402 | 74HCT11 | 74xx:74LS11 | Package_DIP:DIP-14_W7.62mm_Socket
 |  | U403 | 74HCT147 | 74xx:74LS147 | Package_DIP:DIP-16_W7.62mm_Socket
 |  | U404 | 74HCT540 | 74xx:74LS540 | Package_DIP:DIP-20_W7.62mm_Socket
 |  | U405 | 74HCT574 | 74xx:74LS574 | Package_DIP:DIP-20_W7.62mm_Socket
 |  | U406 | 74HCT32 | 74xx:74LS32 | Package_DIP:DIP-14_W7.62mm_Socket
 |  | U407 | 74HCT32 | 74xx:74LS32 | Package_DIP:DIP-14_W7.62mm_Socket
 |  | U501 | 87C51/89C51 | P80C32SBPN:P80C32SBPN | Package_DIP:DIP-40_W15.24mm_Socket | None |  | NXP Semiconductors | DIP-40 NXP Semiconductors | Microcontroller 8-Bit | P80C32SBPN | Unavailable
 |  | U502 | IDT7201 | memory:IDT7201 | Package_DIP:DIP-28_W7.62mm_Socket
 |  | U503 | 74HCT138 | 74xx:74LS138 | Package_DIP:DIP-16_W7.62mm_Socket
 |  | U504 | 74HCT541 | 74xx:74LS541 | Package_DIP:DIP-20_W7.62mm_Socket
 |  | U601 | Upduino_3.0 | Upduino_3.0:Upduino_3.0 | HardwareDesign:DIP-48_W17.78mm
 |  | U602 | IDT7201 | memory:IDT7201 | Package_DIP:DIP-28_W7.62mm_Socket
 |  | U603 | 74LVC245 | 74LVC245:74LVC245 | Package_DIP:DIP-20_W7.62mm_Socket
 |  | U604 | 74LVC245 | 74LVC245:74LVC245 | Package_DIP:DIP-20_W7.62mm_Socket
 |  | U701 | TMS9918A | TMS9918:TMS9918A | Package_DIP:DIP-40_W25.4mm_Socket
 |  | U702 | 74HCT04 | 74xx:74HCT04 | Package_DIP:DIP-14_W7.62mm_Socket
 |  | U703 | 74HCT32 | 74xx:74LS32 | Package_DIP:DIP-14_W7.62mm_Socket
 |  | U704 | 74HCT574 | 74xx:74HCT574 | Package_DIP:DIP-20_W7.62mm_Socket
 |  | U705 | 74HCT574 | 74xx:74HCT574 | Package_DIP:DIP-20_W7.62mm_Socket
 |  | U706 | 74HCT574 | 74xx:74HCT574 | Package_DIP:DIP-20_W7.62mm_Socket
 |  | U707 | HM62256BLP-7 | memory:HM62256BLP-7 | Package_DIP:DIP-28_W7.62mm_Socket
 |  | U801 | YM2149 | YM2149:YM2149 | Package_DIP:DIP-40_W15.24mm_Socket | DOCUMENTATION
 |  | U802 | 74HCT11 | 74xx:74LS11 | Package_DIP:DIP-14_W7.62mm_Socket
 |  | U803 | 4 MHz Osc (half can) | ya68k:XTAL_OSC_HALF_CAN | Package_DIP:DIP-8_W7.62mm_Socket
 |  | U804 | 74HCT00 | 74xx:74HCT00 | Package_DIP:DIP-14_W7.62mm_Socket
 |  | Y100 | Crystal | device:Crystal | Crystal:Crystal_HC18-U_Vertical
 |  | Y501 | 11.0592 MHz | device:Crystal | Crystal:Crystal_HC18-U_Vertical
 |  | Y701 | 10.738635 MHz | device:Crystal | Crystal:Crystal_HC18-U_Vertical
Collated Components:
Item | Qty | Reference(s) | Value | LibPart | Footprint | Datasheet | Comment | Field4 | Field5 | Field6 | Field7 | Field8 | MANUFACTURER | MAXIMUM_PACKAGE_HEIGHT | PARTREV | STANDARD
1 | 1 | C001 | 22μF | device:CP | Capacitor_THT:CP_Radial_D6.3mm_P2.50mm
2 | 13 | C101, C102, C103, C104, C105, C106, C107, C108, C109, C110, C111, C200, C201 | 0.1 uF | device:C | Capacitor_THT:C_Disc_D5.0mm_W2.5mm_P2.50mm
3 | 2 | C113, C114 | 22 pF | device:C | Capacitor_THT:C_Disc_D3.8mm_W2.6mm_P2.50mm
4 | 14 | C301, C302, C303, C401, C402, C403, C404, C405, C406, C407, C501, C502, C503, C504 | 0.1 μF | device:C | Capacitor_THT:C_Disc_D5.0mm_W2.5mm_P2.50mm
5 | 5 | C304, C305, C306, C307, C308 | 1μF | device:CP | Capacitor_THT:CP_Radial_Tantal_D5.0mm_P5.00mm
6 | 2 | C505, C506 | 30pF | device:C | Capacitor_THT:C_Disc_D3.8mm_W2.6mm_P2.50mm
7 | 11 | C701, C702, C703, C704, C705, C706, C707, C801, C802, C803, C804 | 100 nF | device:C | Capacitor_THT:C_Disc_D3.4mm_W2.1mm_P2.50mm
8 | 2 | C710, C711 | 22 pF | device:C | Capacitor_THT:C_Disc_D3.4mm_W2.1mm_P2.50mm
9 | 2 | C805, C806 | 2.2 uF | device:C | Capacitor_THT:C_Rect_L7.0mm_W4.5mm_P5.00mm
10 | 4 | D100, D601, D602, D603 | LED | device:LED | LED_THT:LED_D5.0mm
11 | 1 | J001 | Conn_02x40_Odd_Even | Connector_Generic:Conn_02x40_Odd_Even | Connector_PinHeader_2.54mm:PinHeader_2x40_P2.54mm_Vertical | ~
12 | 4 | J100, J503, J702, J801 | Conn_01x02 | Connector_Generic:Conn_01x02 | Connector_PinHeader_2.54mm:PinHeader_1x02_P2.54mm_Vertical | ~
13 | 1 | J201 | Conn_01x03 | Connector_Generic:Conn_01x03 | Connector_PinHeader_2.54mm:PinHeader_1x03_P2.54mm_Vertical | ~
14 | 2 | J303, J304 | Conn_01x05 | Connector_Generic:Conn_01x05 | Connector_PinHeader_2.54mm:PinHeader_1x05_P2.54mm_Vertical | ~
15 | 2 | J305, J306 | Conn_01x09 | Connector_Generic:Conn_01x09 | Connector_PinHeader_2.54mm:PinHeader_1x09_P2.54mm_Vertical | ~
16 | 1 | J501 | Conn_01x20 | Connector_Generic:Conn_01x20 | Connector_PinHeader_2.54mm:PinHeader_1x20_P2.54mm_Vertical | ~
17 | 1 | J601 | Conn_01x12 | Connector_Generic:Conn_01x12 | Connector_PinHeader_2.54mm:PinHeader_1x12_P2.54mm_Vertical | ~
18 | 1 | J701 | RCJ-044 | RCJ-044:RCJ-044 | CUI_RCJ-044:CUI_RCJ-044 |  |  |  |  |  |  |  | CUI Devices | 11.6 mm | 1.02 | Manufacturer Recommendations
19 | 1 | J802 | Conn_02x09_Odd_Even | Connector_Generic:Conn_02x09_Odd_Even | Connector_PinHeader_2.54mm:PinHeader_2x09_P2.54mm_Vertical | ~
20 | 1 | J803 | SJ1-3525N | SJ1-3525N:SJ1-3525N | CUI_SJ1-3525N |  |  |  |  |  |  |  | CUI |  | 1.02 | Manufacturer recommendation
21 | 1 | Q701 | 2N4401 | device:Q_NPN_EBC | Package_TO_SOT_THT:TO-92_HandSolder
22 | 1 | R100 | R | device:R | Resistor_THT:R_Axial_DIN0204_L3.6mm_D1.6mm_P7.62mm_Horizontal
23 | 10 | R101, R102, R103, R401, R402, R403, R404, R405, R406, R407 | 4k7 | device:R | Resistor_THT:R_Axial_DIN0204_L3.6mm_D1.6mm_P7.62mm_Horizontal
24 | 4 | R301, R302, R303, R304 | 2k7 | device:R | Resistor_THT:R_Axial_DIN0204_L3.6mm_D1.6mm_P7.62mm_Horizontal
25 | 1 | R305 | 10k | device:R | Resistor_THT:R_Axial_DIN0204_L3.6mm_D1.6mm_P7.62mm_Horizontal
26 | 3 | R601, R609, R617 | 430 | device:R | Resistor_THT:R_Axial_DIN0204_L3.6mm_D1.6mm_P7.62mm_Horizontal
27 | 3 | R602, R610, R618 | 82 | device:R | Resistor_THT:R_Axial_DIN0204_L3.6mm_D1.6mm_P7.62mm_Horizontal
28 | 3 | R603, R611, R619 | 1k | device:R | Resistor_THT:R_Axial_DIN0204_L3.6mm_D1.6mm_P7.62mm_Horizontal
29 | 3 | R604, R612, R620 | 24 | device:R | Resistor_THT:R_Axial_DIN0204_L3.6mm_D1.6mm_P7.62mm_Horizontal
30 | 3 | R605, R613, R621 | 2k | device:R | Resistor_THT:R_Axial_DIN0204_L3.6mm_D1.6mm_P7.62mm_Horizontal
31 | 3 | R606, R614, R622 | 50 | device:R | Resistor_THT:R_Axial_DIN0204_L3.6mm_D1.6mm_P7.62mm_Horizontal
32 | 3 | R607, R615, R623 | 3k9 | device:R | Resistor_THT:R_Axial_DIN0204_L3.6mm_D1.6mm_P7.62mm_Horizontal
33 | 3 | R608, R616, R624 | 200 | device:R | Resistor_THT:R_Axial_DIN0204_L3.6mm_D1.6mm_P7.62mm_Horizontal
34 | 3 | R625, R626, R627 | R | device:R | Resistor_THT:R_Axial_DIN0207_L6.3mm_D2.5mm_P7.62mm_Horizontal
35 | 1 | R701 | 470 | device:R | Resistor_THT:R_Axial_DIN0207_L6.3mm_D2.5mm_P7.62mm_Horizontal
36 | 5 | R702, R804, R805, R806, R807 | 1k | device:R | Resistor_THT:R_Axial_DIN0207_L6.3mm_D2.5mm_P7.62mm_Horizontal
37 | 3 | R801, R802, R803 | 3k | Device:R | Resistor_THT:R_Axial_DIN0207_L6.3mm_D2.5mm_P7.62mm_Horizontal | ~
38 | 1 | RN101 | 4k7 | device:R_Network08 | Resistor_THT:R_Array_SIP9
39 | 1 | RN501 | R_Network08 | device:R_Network08 | Resistor_THT:R_Array_SIP9
40 | 1 | RN601 | 10k | device:R_Network08 | Resistors_THT:R_Array_SIP9
41 | 1 | S100 | 1-1825027-2 | 1-1825027-2:1-1825027-2 | SW_1-1825027-2:SW_1-1825027-2 |  | 1-1825027-2
42 | 1 | TB605 | ARDUINO_NANO | ARDUINO_NANO:ARDUINO_NANO | SHIELD_ARDUINO_NANO | DFRobot |  | Dev.kit: Arduino; UART; ICSP, USB B mini, pin strips | None | None | ARDUINO NANO | Unavailable
43 | 3 | U101, U102, U103 | 74HCT245 | 74xx:74HC245 | Package_DIP:DIP-20_W7.62mm_Socket
44 | 1 | U104 | 74HCT365 | 74xx:74LS365 | Package_DIP:DIP-16_W7.62mm_Socket
45 | 1 | U105 | MAX708 | ya68k:MAX708 | Package_DIP:DIP-8_W7.62mm_Socket
46 | 1 | U106 | HD6809 | HD6809:HD6809 | Package_DIP:DIP-40_W15.24mm_Socket | DOCUMENTATION
47 | 1 | U107 | 74HCT00 | 74xx:74HC00 | Package_DIP:DIP-14_W7.62mm_Socket
48 | 1 | U108 | 74HCT27 | 74xx:74LS27 | Package_DIP:DIP-14_W7.62mm_Socket
49 | 4 | U109, U110, U111, U503 | 74HCT138 | 74xx:74LS138 | Package_DIP:DIP-16_W7.62mm_Socket
50 | 1 | U200 | 28C256 | memory:28C256 | Socket:DIP_Socket-28_W11.9_W12.7_W15.24_W17.78_W18.5_3M_228-1277-00-0602J
51 | 1 | U201 | HM62256BLP-7SL | memory:HM62256BLP-7SL | Package_DIP:DIP-28_W15.24mm_Socket
52 | 1 | U301 | 82C55A | Interface:82C55A | Package_DIP:DIP-40_W15.24mm_Socket | http://jap.hu/electronic/8255.pdf
53 | 1 | U302 | 82C54 | intel:82C54 | Package_DIP:DIP-24_W15.24mm_Socket | http://download.intel.com/design/archives/periphrl/docs/23124406.pdf
54 | 1 | U303 | MC6850 | MC6850:MC6850 | Package_DIP:DIP-24_W15.24mm_Socket | DOCUMENTATION
55 | 1 | U304 | MAX232CPE | MAX232CPE:MAX232CPE | Package_DIP:DIP-16_W7.62mm_Socket
56 | 1 | U401 | 74HCT74 | 74xx:74LS74 | Package_DIP:DIP-14_W7.62mm_Socket
57 | 2 | U402, U802 | 74HCT11 | 74xx:74LS11 | Package_DIP:DIP-14_W7.62mm_Socket
58 | 1 | U403 | 74HCT147 | 74xx:74LS147 | Package_DIP:DIP-16_W7.62mm_Socket
59 | 1 | U404 | 74HCT540 | 74xx:74LS540 | Package_DIP:DIP-20_W7.62mm_Socket
60 | 1 | U405 | 74HCT574 | 74xx:74LS574 | Package_DIP:DIP-20_W7.62mm_Socket
61 | 3 | U406, U407, U703 | 74HCT32 | 74xx:74LS32 | Package_DIP:DIP-14_W7.62mm_Socket
62 | 1 | U501 | 87C51/89C51 | P80C32SBPN:P80C32SBPN | Package_DIP:DIP-40_W15.24mm_Socket | None |  | NXP Semiconductors | DIP-40 NXP Semiconductors | Microcontroller 8-Bit | P80C32SBPN | Unavailable
63 | 2 | U502, U602 | IDT7201 | memory:IDT7201 | Package_DIP:DIP-28_W7.62mm_Socket
64 | 1 | U504 | 74HCT541 | 74xx:74LS541 | Package_DIP:DIP-20_W7.62mm_Socket
65 | 1 | U601 | Upduino_3.0 | Upduino_3.0:Upduino_3.0 | HardwareDesign:DIP-48_W17.78mm
66 | 2 | U603, U604 | 74LVC245 | 74LVC245:74LVC245 | Package_DIP:DIP-20_W7.62mm_Socket
67 | 1 | U701 | TMS9918A | TMS9918:TMS9918A | Package_DIP:DIP-40_W25.4mm_Socket
68 | 1 | U702 | 74HCT04 | 74xx:74HCT04 | Package_DIP:DIP-14_W7.62mm_Socket
69 | 3 | U704, U705, U706 | 74HCT574 | 74xx:74HCT574 | Package_DIP:DIP-20_W7.62mm_Socket
70 | 1 | U707 | HM62256BLP-7 | memory:HM62256BLP-7 | Package_DIP:DIP-28_W7.62mm_Socket
71 | 1 | U801 | YM2149 | YM2149:YM2149 | Package_DIP:DIP-40_W15.24mm_Socket | DOCUMENTATION
72 | 1 | U803 | 4 MHz Osc (half can) | ya68k:XTAL_OSC_HALF_CAN | Package_DIP:DIP-8_W7.62mm_Socket
73 | 1 | U804 | 74HCT00 | 74xx:74HCT00 | Package_DIP:DIP-14_W7.62mm_Socket
74 | 1 | Y100 | Crystal | device:Crystal | Crystal:Crystal_HC18-U_Vertical
75 | 1 | Y501 | 11.0592 MHz | device:Crystal | Crystal:Crystal_HC18-U_Vertical
76 | 1 | Y701 | 10.738635 MHz | device:Crystal | Crystal:Crystal_HC18-U_Vertical

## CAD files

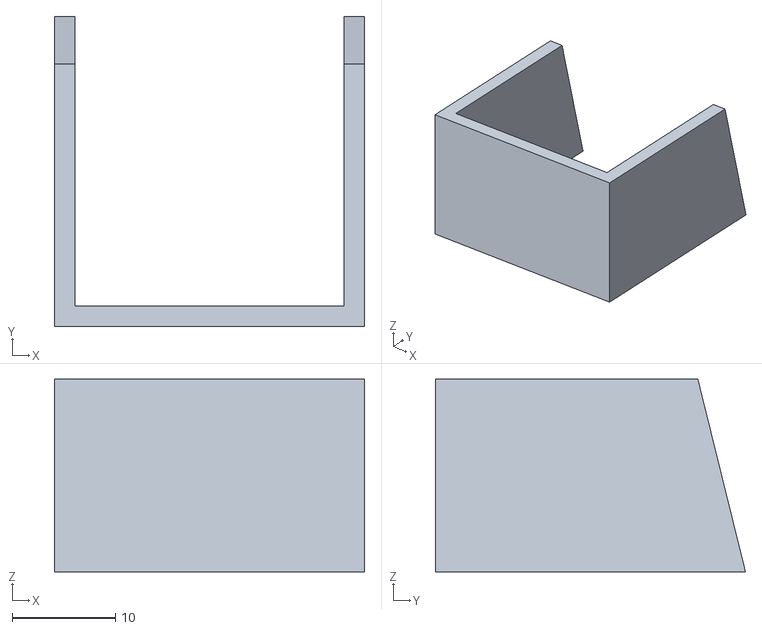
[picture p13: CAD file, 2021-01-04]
Episode13/leg_assembly.stl
30.0 x 30.0 x 18.6

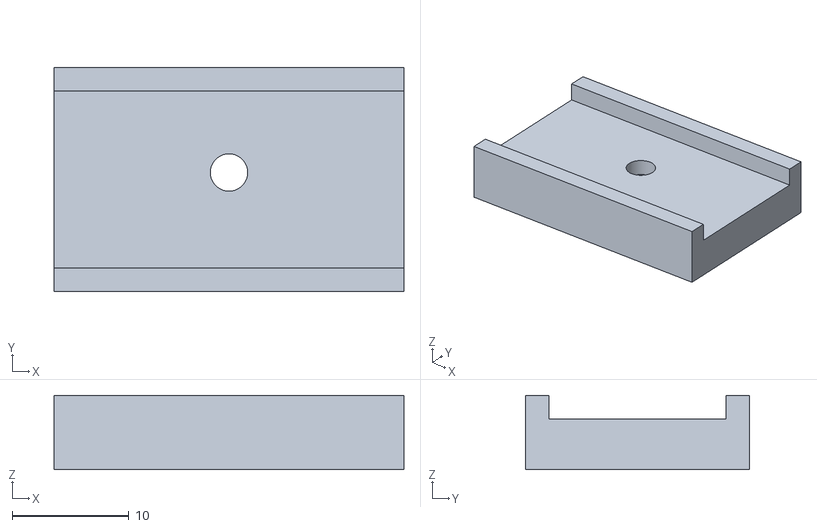
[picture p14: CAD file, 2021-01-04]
Episode13/bracket.stl
30.0 x 19.2 x 6.35

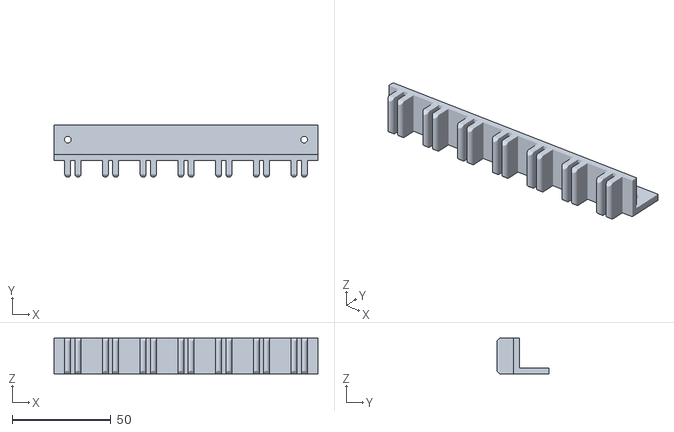
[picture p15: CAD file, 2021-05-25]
Episode14/CardGuide.stl
133.3 x 26.5 x 18.0

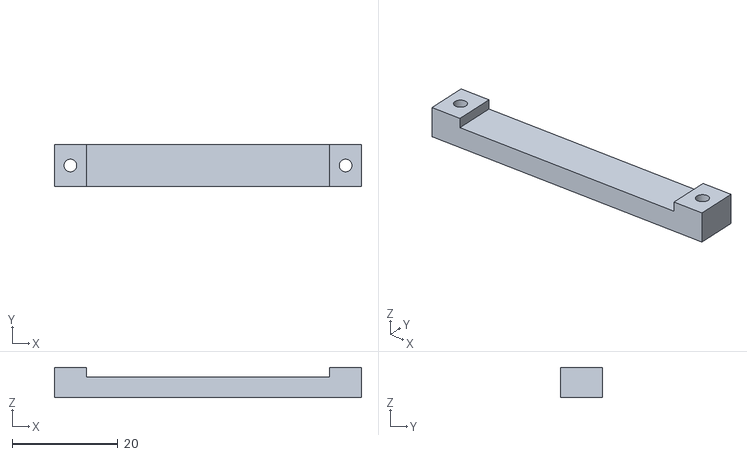
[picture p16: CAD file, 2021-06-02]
Episode15/Mechanical/VGABracket.stl
58.0 x 8.00 x 5.70

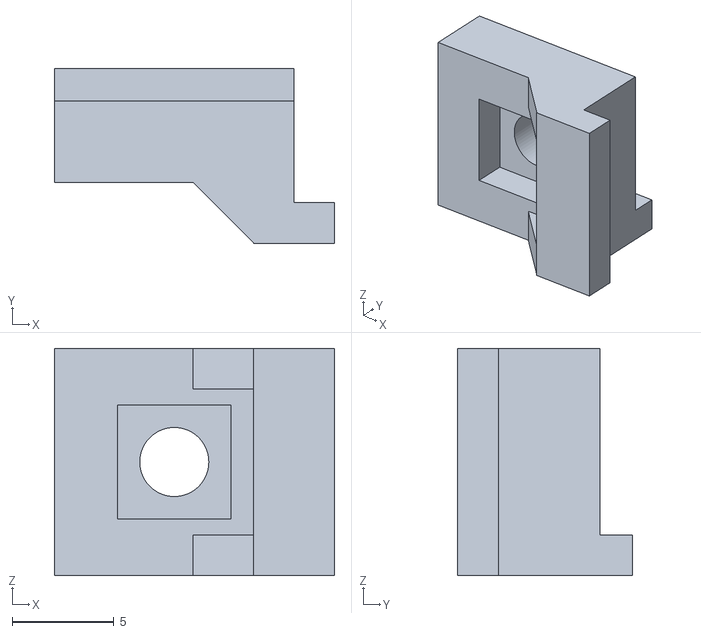
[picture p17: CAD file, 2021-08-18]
Episode16/Mechanical/bracket.stl
13.8 x 8.60 x 11.2

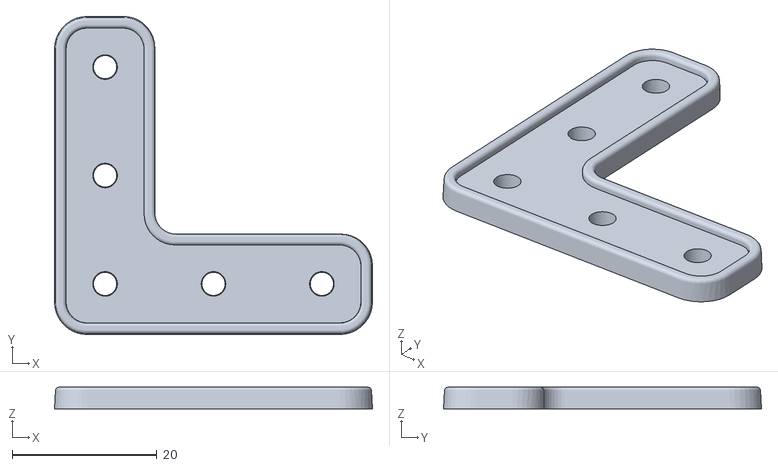
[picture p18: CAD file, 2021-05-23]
Mechanical/L_Plate_WO_Gusset_OpenBeam_1515.STL
44.0 x 44.0 x 3.00

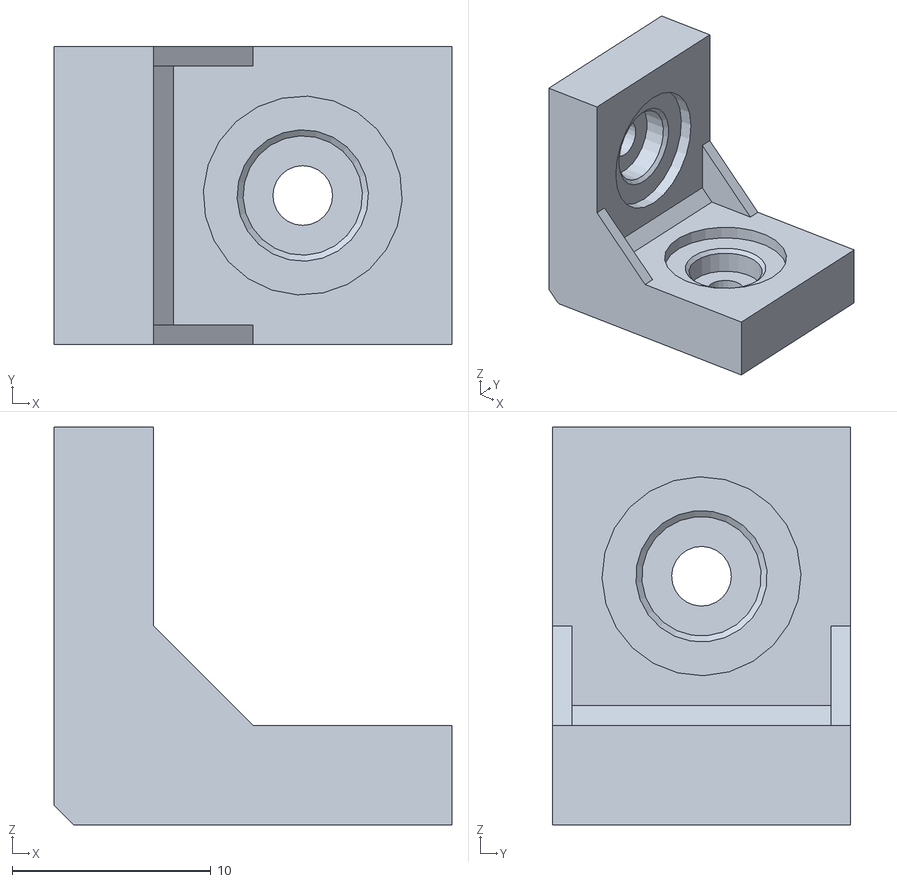
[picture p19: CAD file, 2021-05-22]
Episode14/lbracket.stl
20.0 x 15.0 x 20.0

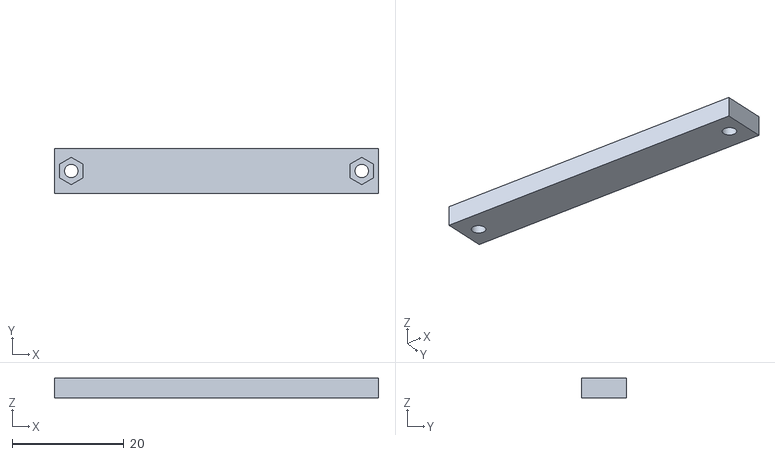
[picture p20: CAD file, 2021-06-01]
Episode15/Mechanical/VGABracket_top.stl
58.0 x 8.00 x 3.50

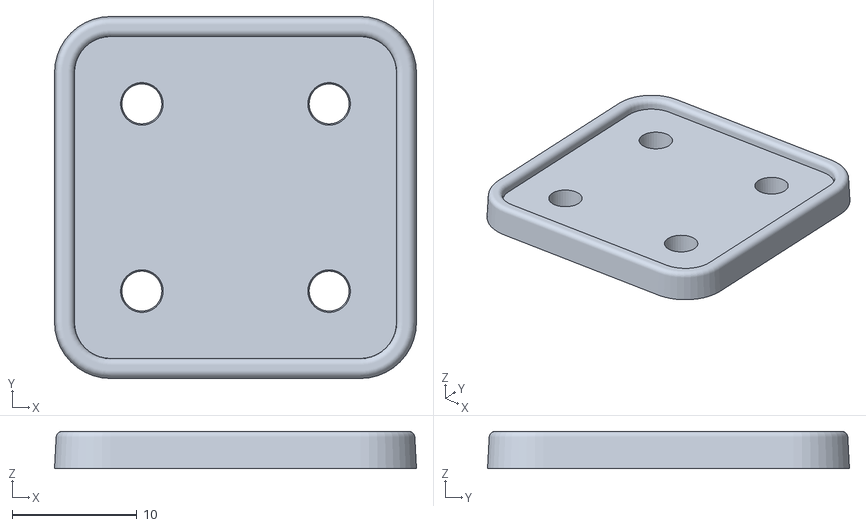
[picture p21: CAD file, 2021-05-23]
Mechanical/Square_Plate_OpenBeam_1515.STL
29.0 x 29.0 x 3.00

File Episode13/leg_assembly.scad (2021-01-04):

// Leg assembly model for C16 keyboard support

include <common.scad>;

module wedge() {
    translate([bracket_wall_thickness, 0, 0]) {
        rotate([0, -90, 0]) {
            linear_extrude(bracket_wall_thickness) {
                polygon(points=[[0,0], [0, leg_d], [leg_back_extra_h, leg_d]]);
            }
        }
    }
}

module leg() {
    cube([bracket_wall_thickness, leg_d, leg_front_height]);
    translate([0, 0, leg_front_height]) {
        wedge();
    }
}

// printing the entire assembly at once doesn't work, so print
// the bracket and leg assembly separately
/*
module assembly() {
    translate([0, 0, leg_front_height]) {
        rotate([kb_incline_angle, 0, 0]) {
            bracket();
        }
    }

    leg();
    
    translate([bracket_w-bracket_wall_thickness, 0, 0]) {
        leg();
    }
    
    cube([bracket_w, leg_d, bracket_wall_thickness]);
}
*/

module leg_assembly() {
    leg();
    
    translate([bracket_w-bracket_wall_thickness, 0, 0]) {
        leg();
    }
    
    cube([bracket_w, leg_d, bracket_wall_thickness]);
}


// uncomment this to print a leg assembly
translate([0, 0, leg_d]) {
    rotate([-90, 0, 0]) {
        leg_assembly();
    }
}

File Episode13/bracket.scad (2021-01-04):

// Bracket model for C16 keyboard support

include <common.scad>;

module bracket_solid() {
    cube([bracket_w, bracket_d, bracket_base_thickness]);
    
    translate([0, 0, bracket_base_thickness]) {
        cube([bracket_w, bracket_wall_thickness, bracket_wall_thickness]);
    }
    
    translate([0, flange_d+bracket_wall_thickness, bracket_base_thickness]) {
        cube([bracket_w, bracket_wall_thickness, bracket_wall_thickness]);
    }
}

module bracket() {
    difference() {
        bracket_solid();
        
        translate([bracket_w/2, flange_d+bracket_wall_thickness-screw_hole_offset, -0.05]) {
            cylinder(r=m3_hex_nut_d/2+m3_hex_nut_hole_tolerance, h=m3_hex_nut_h+0.4+0.1, $fn=6);
            cylinder(r=m3_screw_hole_d/2, h=bracket_base_thickness+0.1, $fn=60);
        }
    }
}

bracket();

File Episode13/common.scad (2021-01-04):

// all measurements are mm

// measured from front flange to rear flange
kb_d = 125;

// desired height of the back flange
back_h = 30;

flange_d = 15.2; // really 15, but leave some clearance

// hole center is about 6mm  offset from outer edge of flange
screw_hole_offset = 7;

// dimensions for m3 nut pocket
m3_hex_nut_d = 6.15; // measured the long way
m3_hex_nut_h = 2.15;
m3_hex_nut_hole_tolerance = 0.4;

// m3 screw hole diameter
m3_screw_hole_d = 3.2;

// bracket dimensions
bracket_w = 30;
bracket_base_thickness = m3_hex_nut_h + 0.2 + 2;
bracket_wall_thickness = 2;
bracket_d = flange_d + 2*bracket_wall_thickness; // depth of bracket base

// angle by which keyboard is inclined
kb_incline_angle = 13.8865;

leg_back_extra_h = ((3*bracket_d) / 12.5);
leg_front_height = 30 - leg_back_extra_h;
leg_d = sqrt(bracket_d*bracket_d - leg_back_extra_h*leg_back_extra_h);

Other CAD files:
Episode16/Mechanical/right_bracket.stl
Episode14/CardGuide.scad
Episode15/Mechanical/VGABracket.scad
Episode16/Mechanical/bracket.scad

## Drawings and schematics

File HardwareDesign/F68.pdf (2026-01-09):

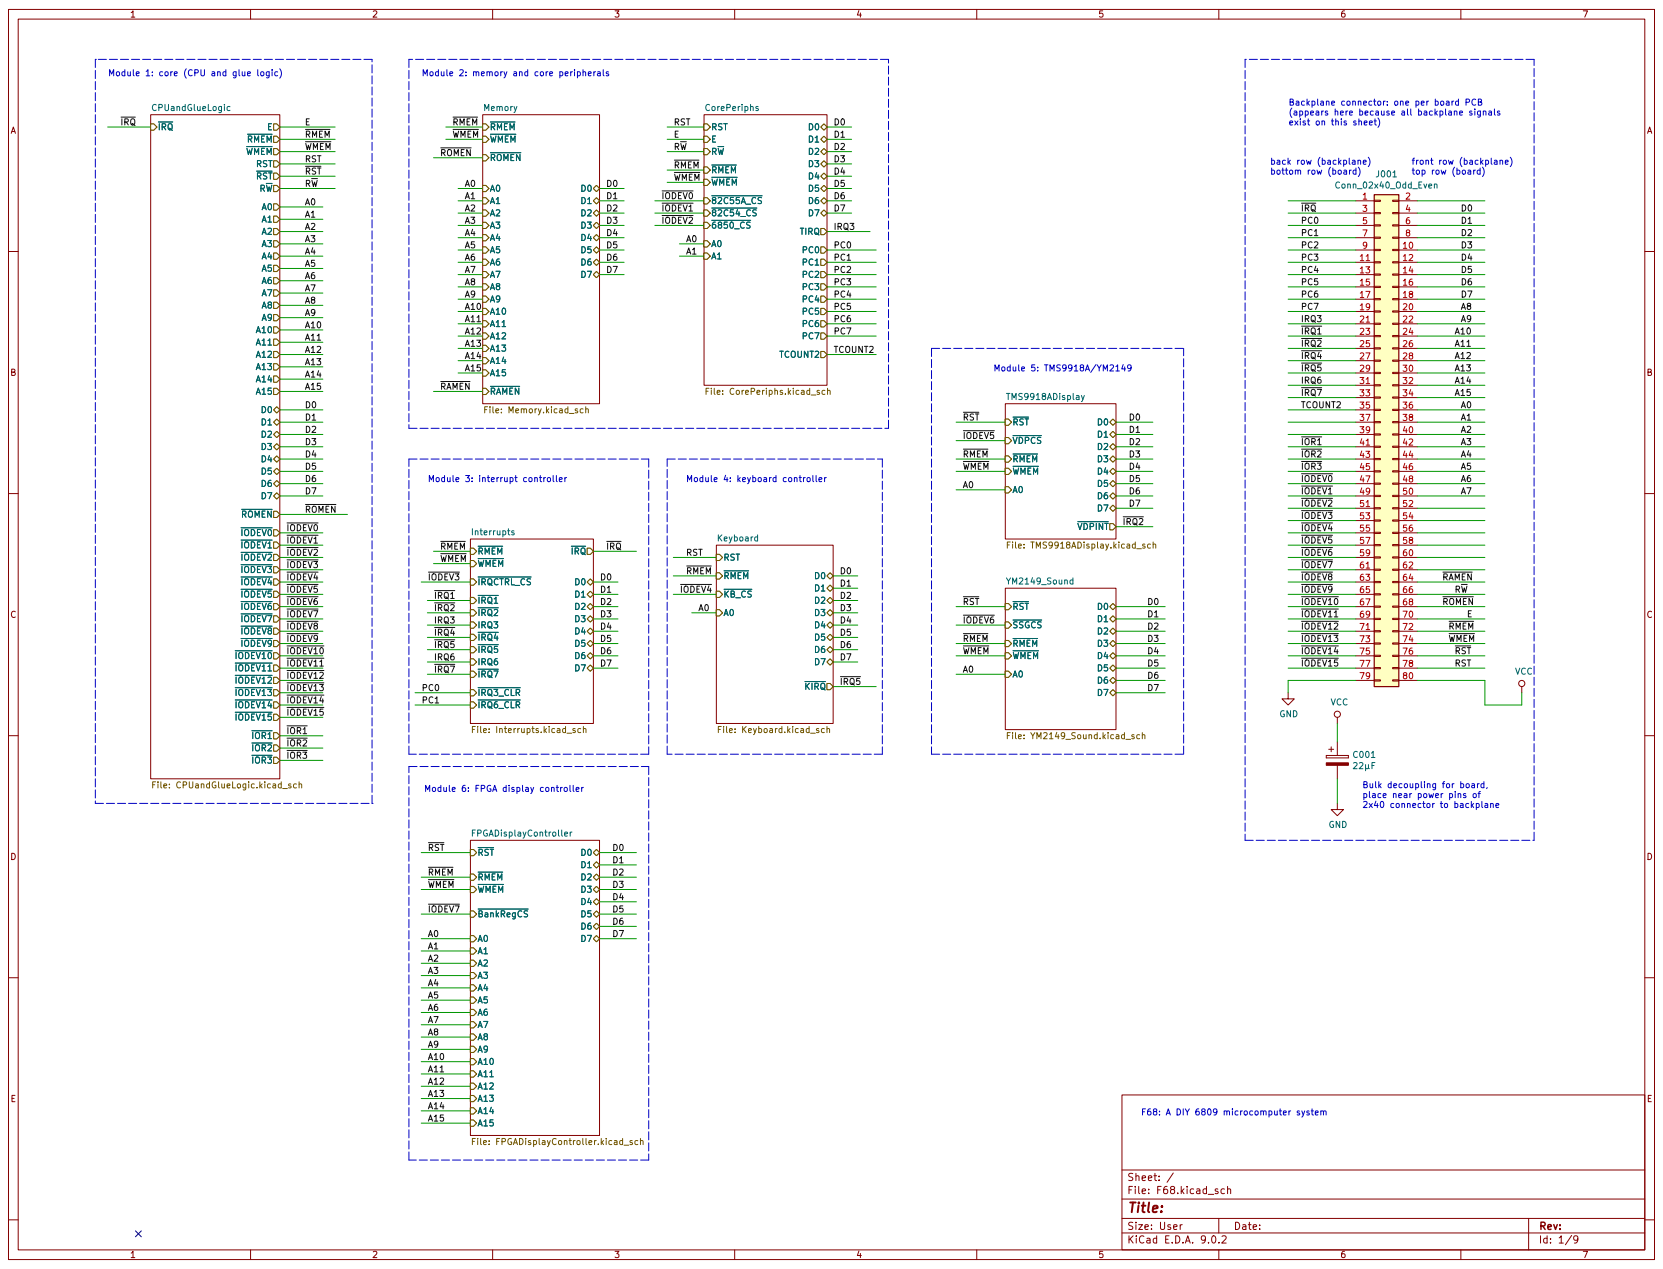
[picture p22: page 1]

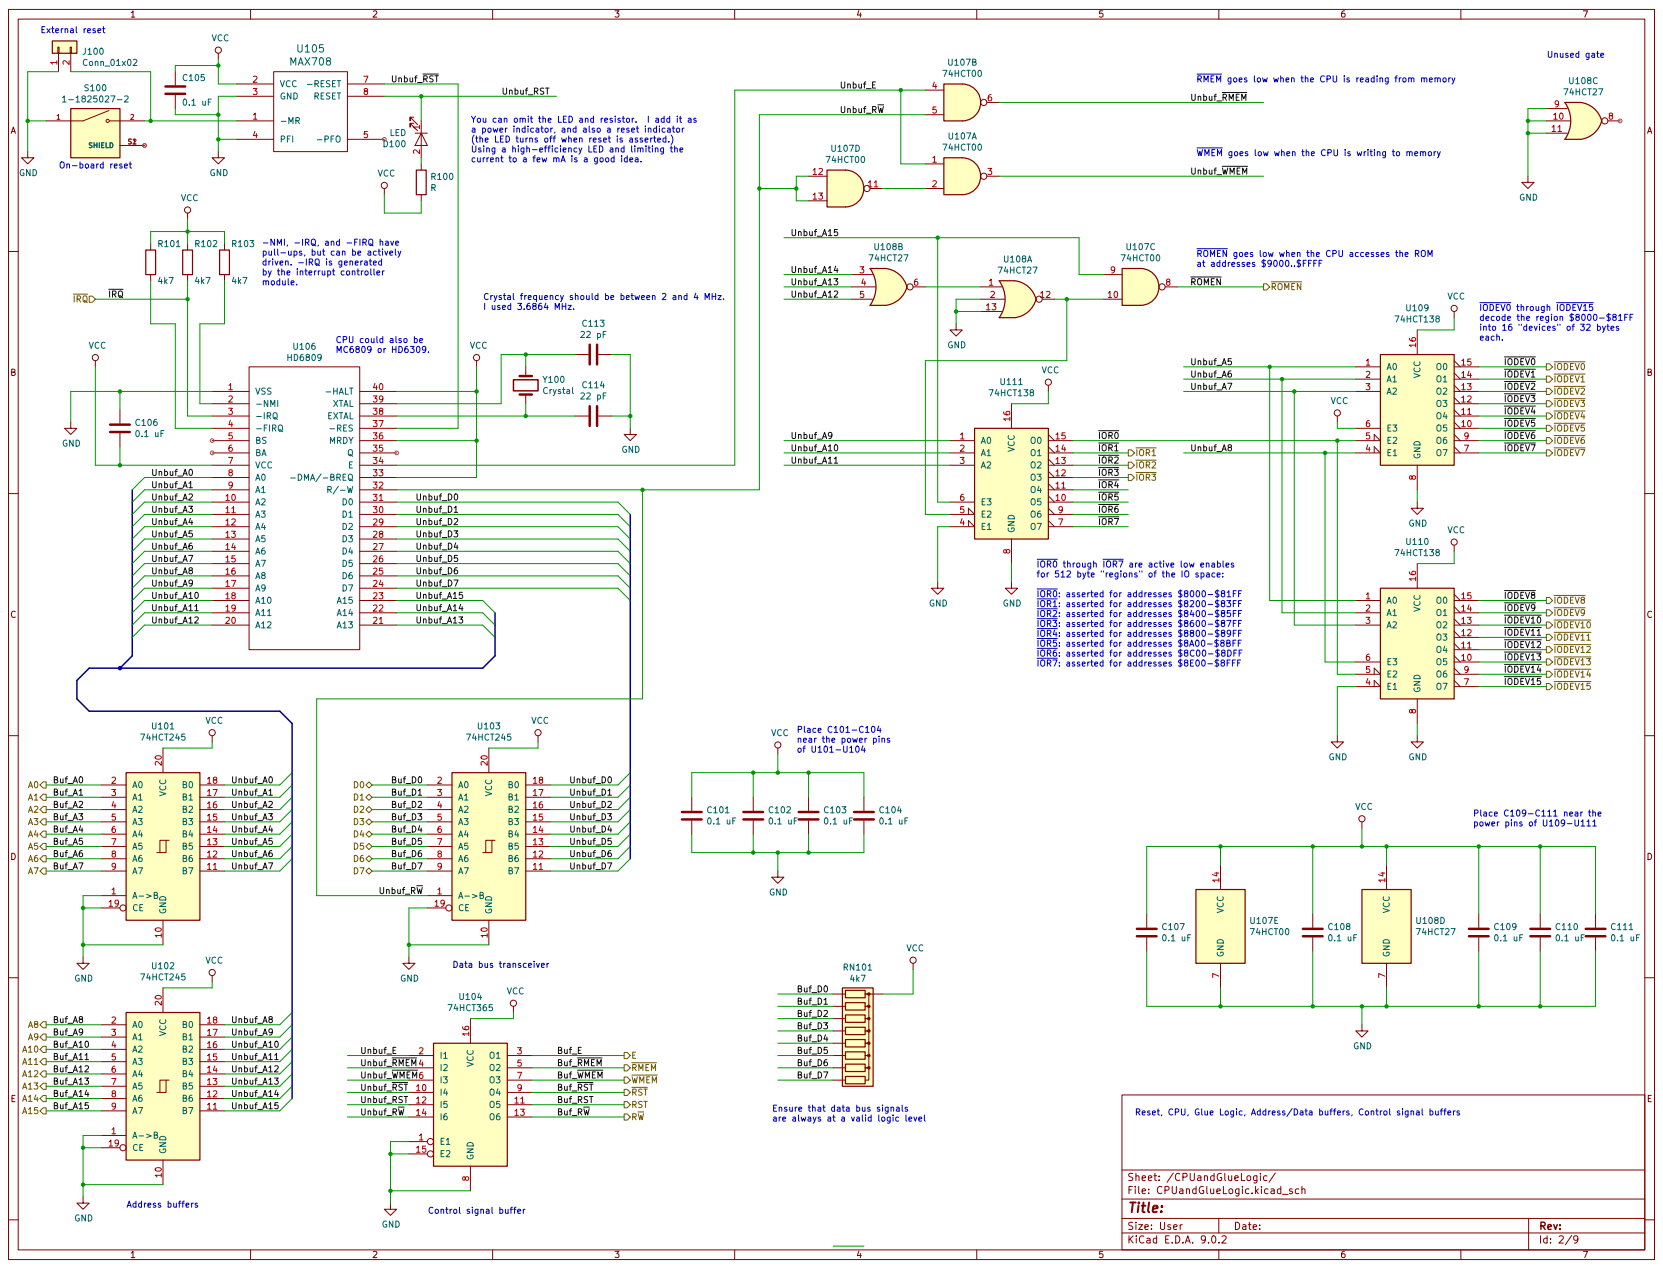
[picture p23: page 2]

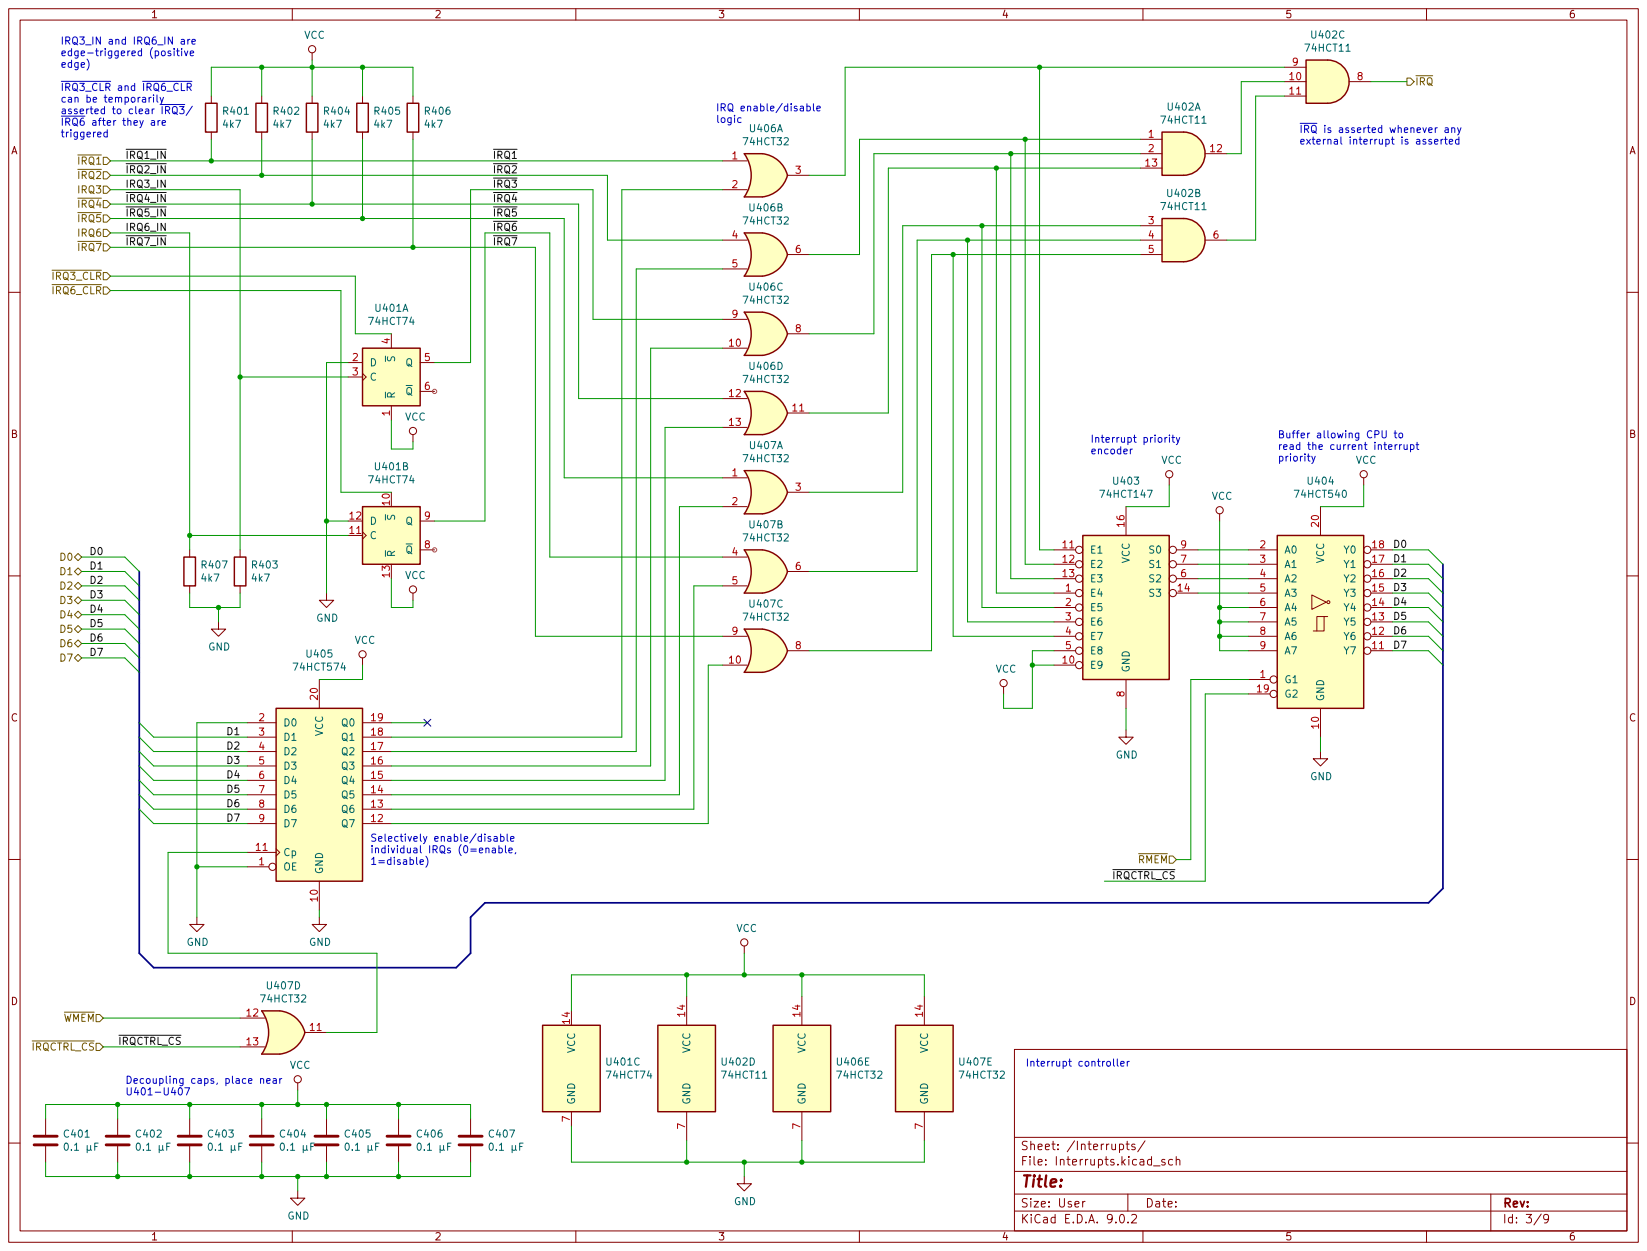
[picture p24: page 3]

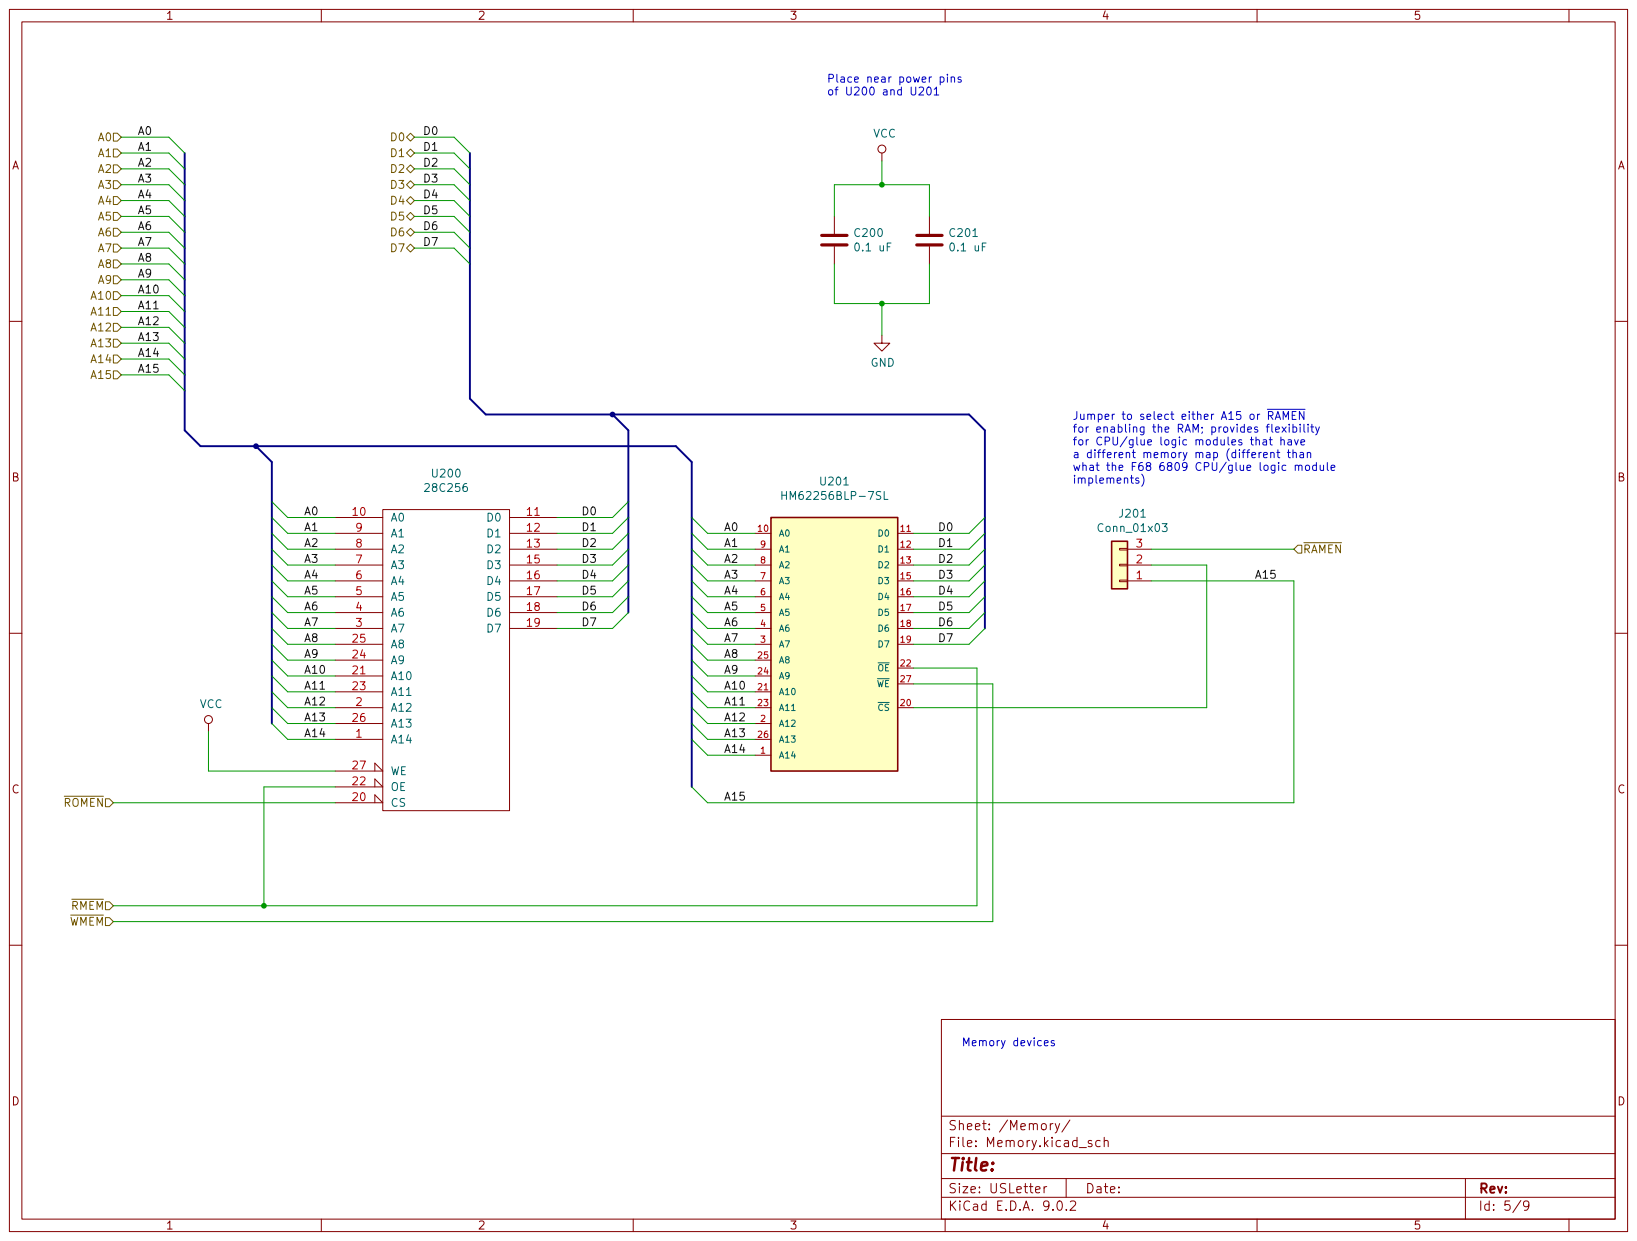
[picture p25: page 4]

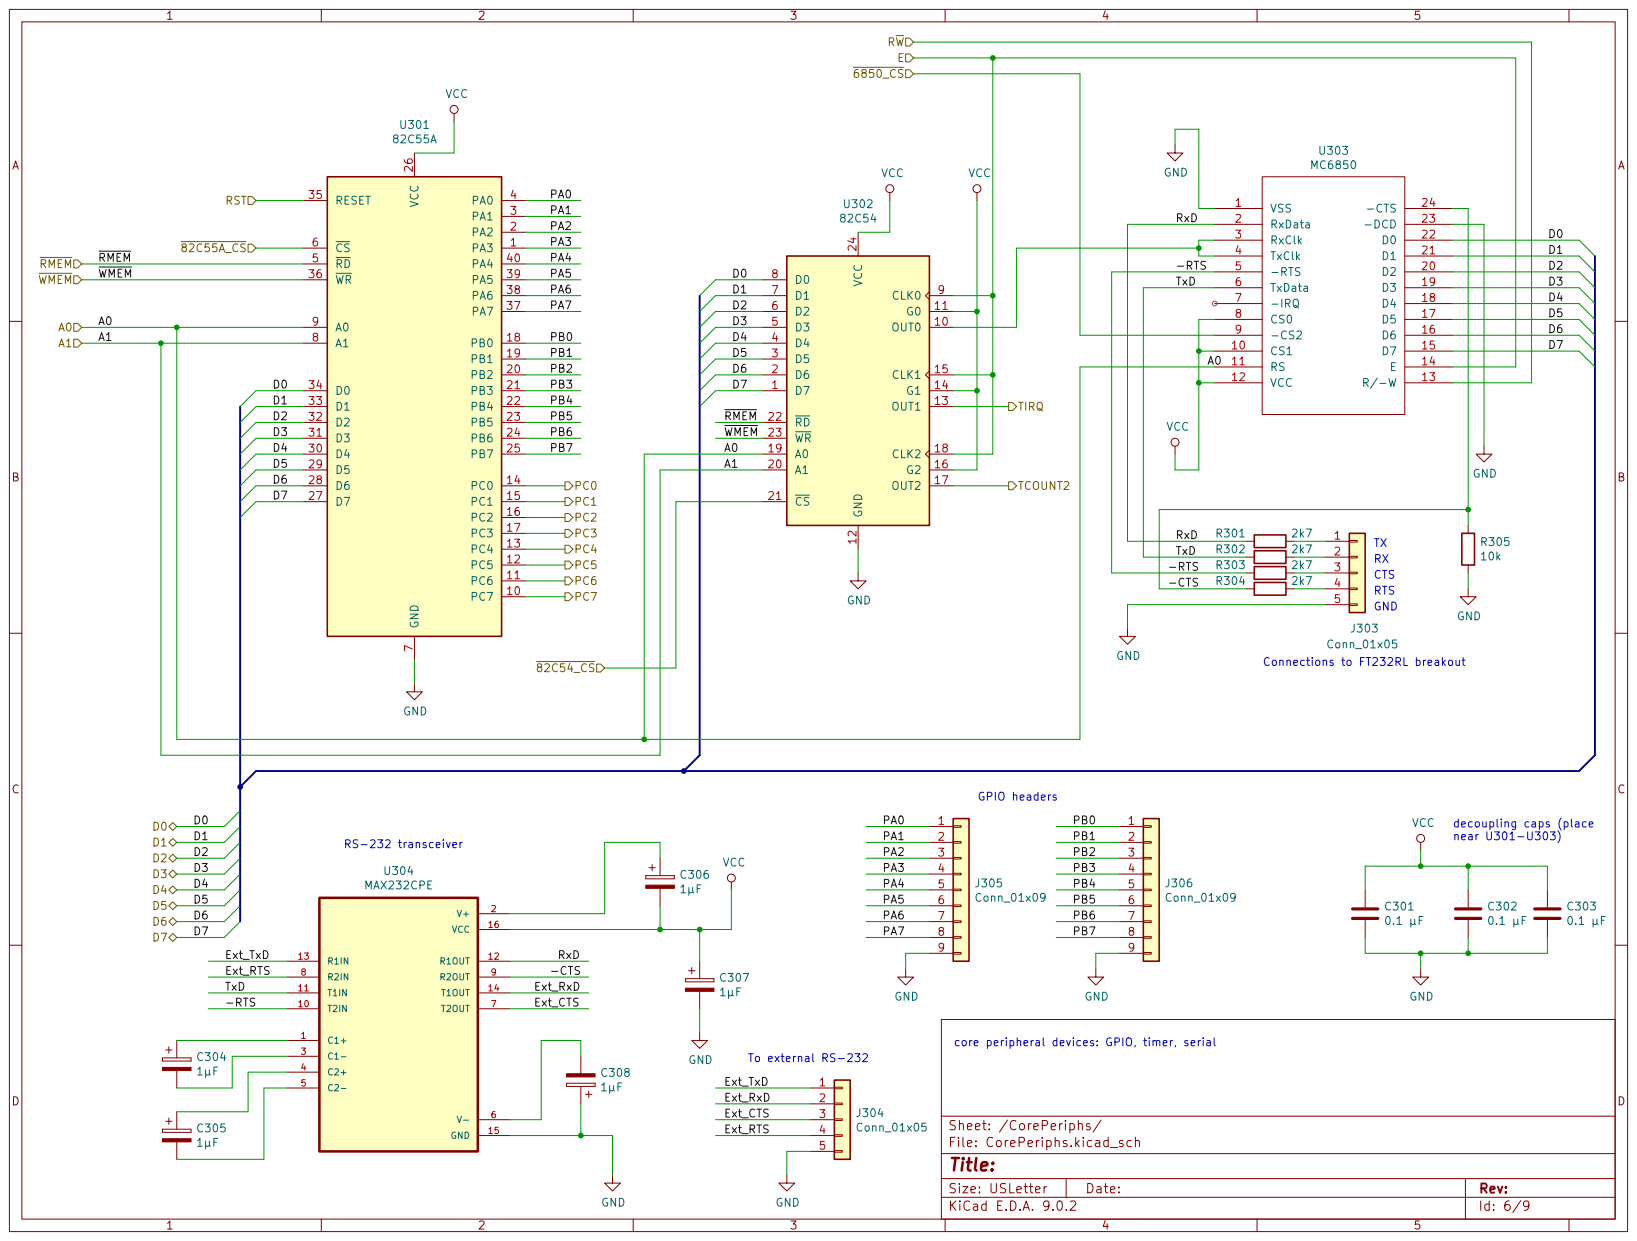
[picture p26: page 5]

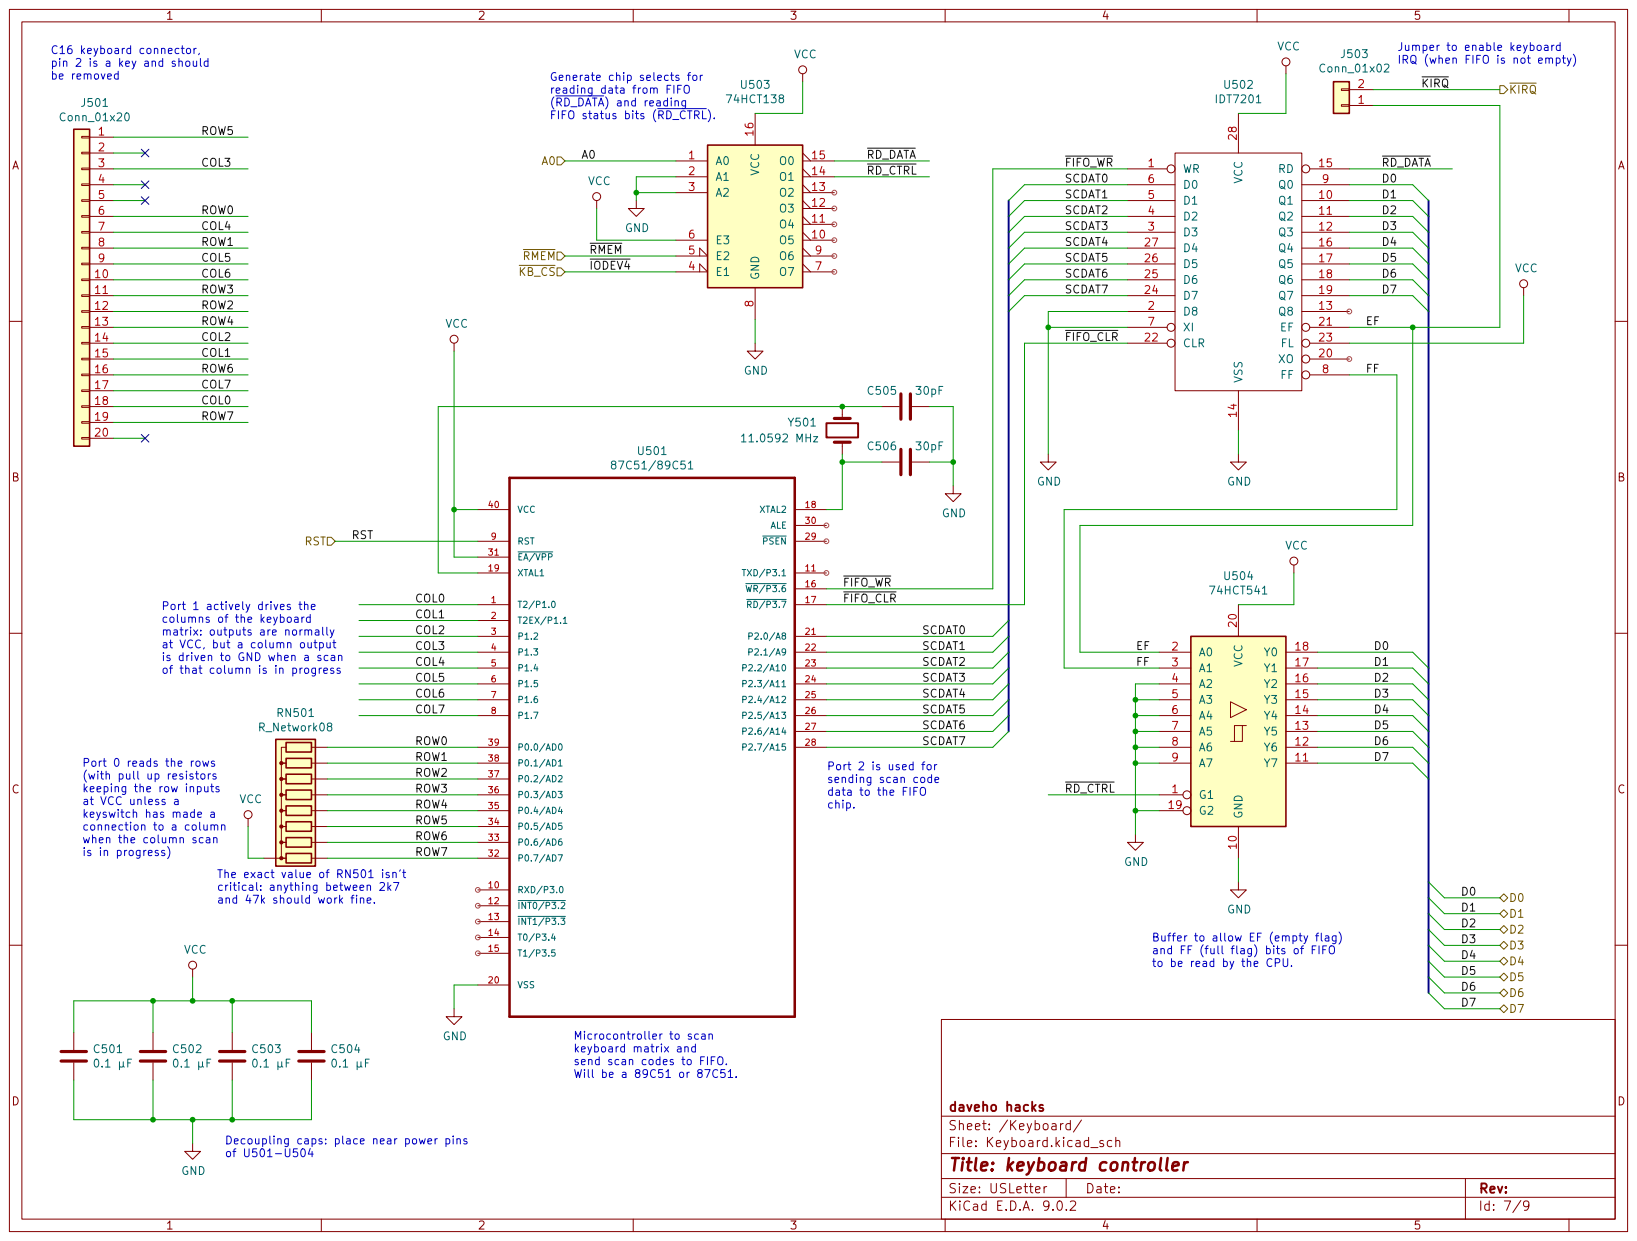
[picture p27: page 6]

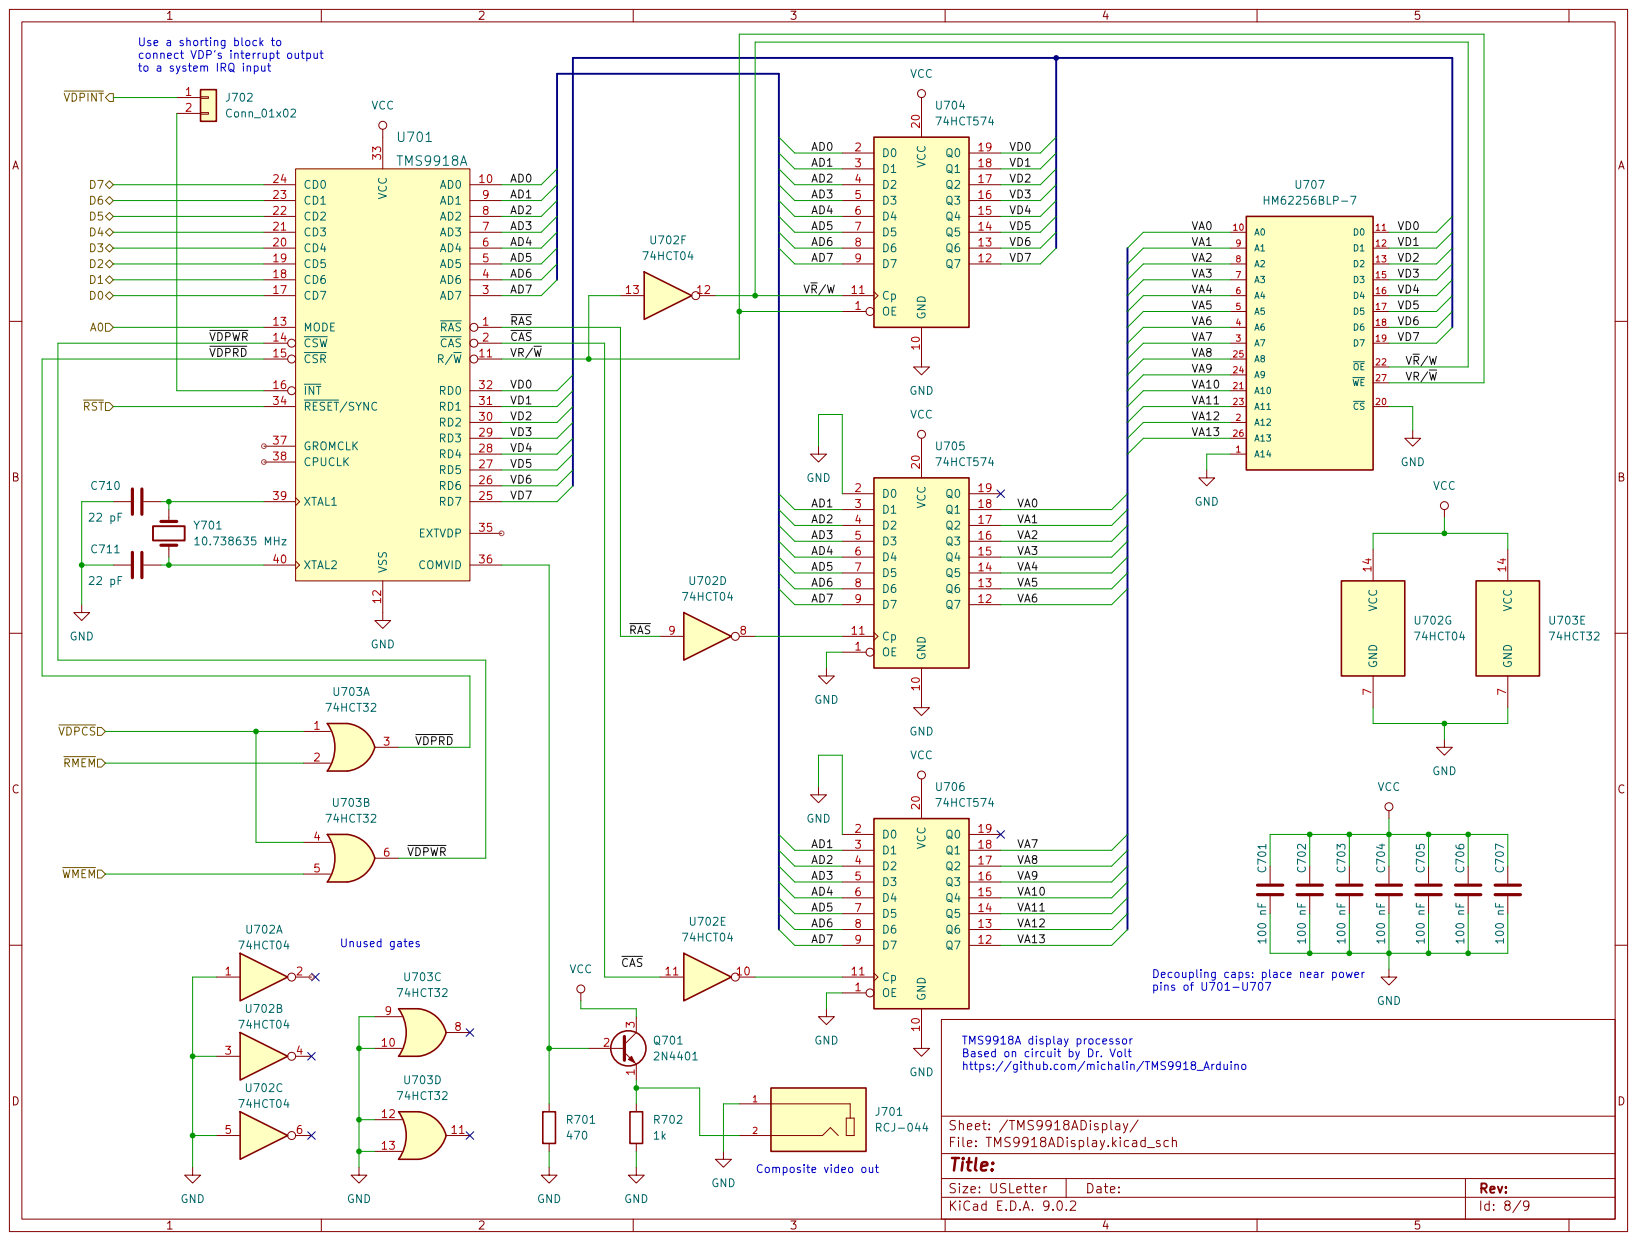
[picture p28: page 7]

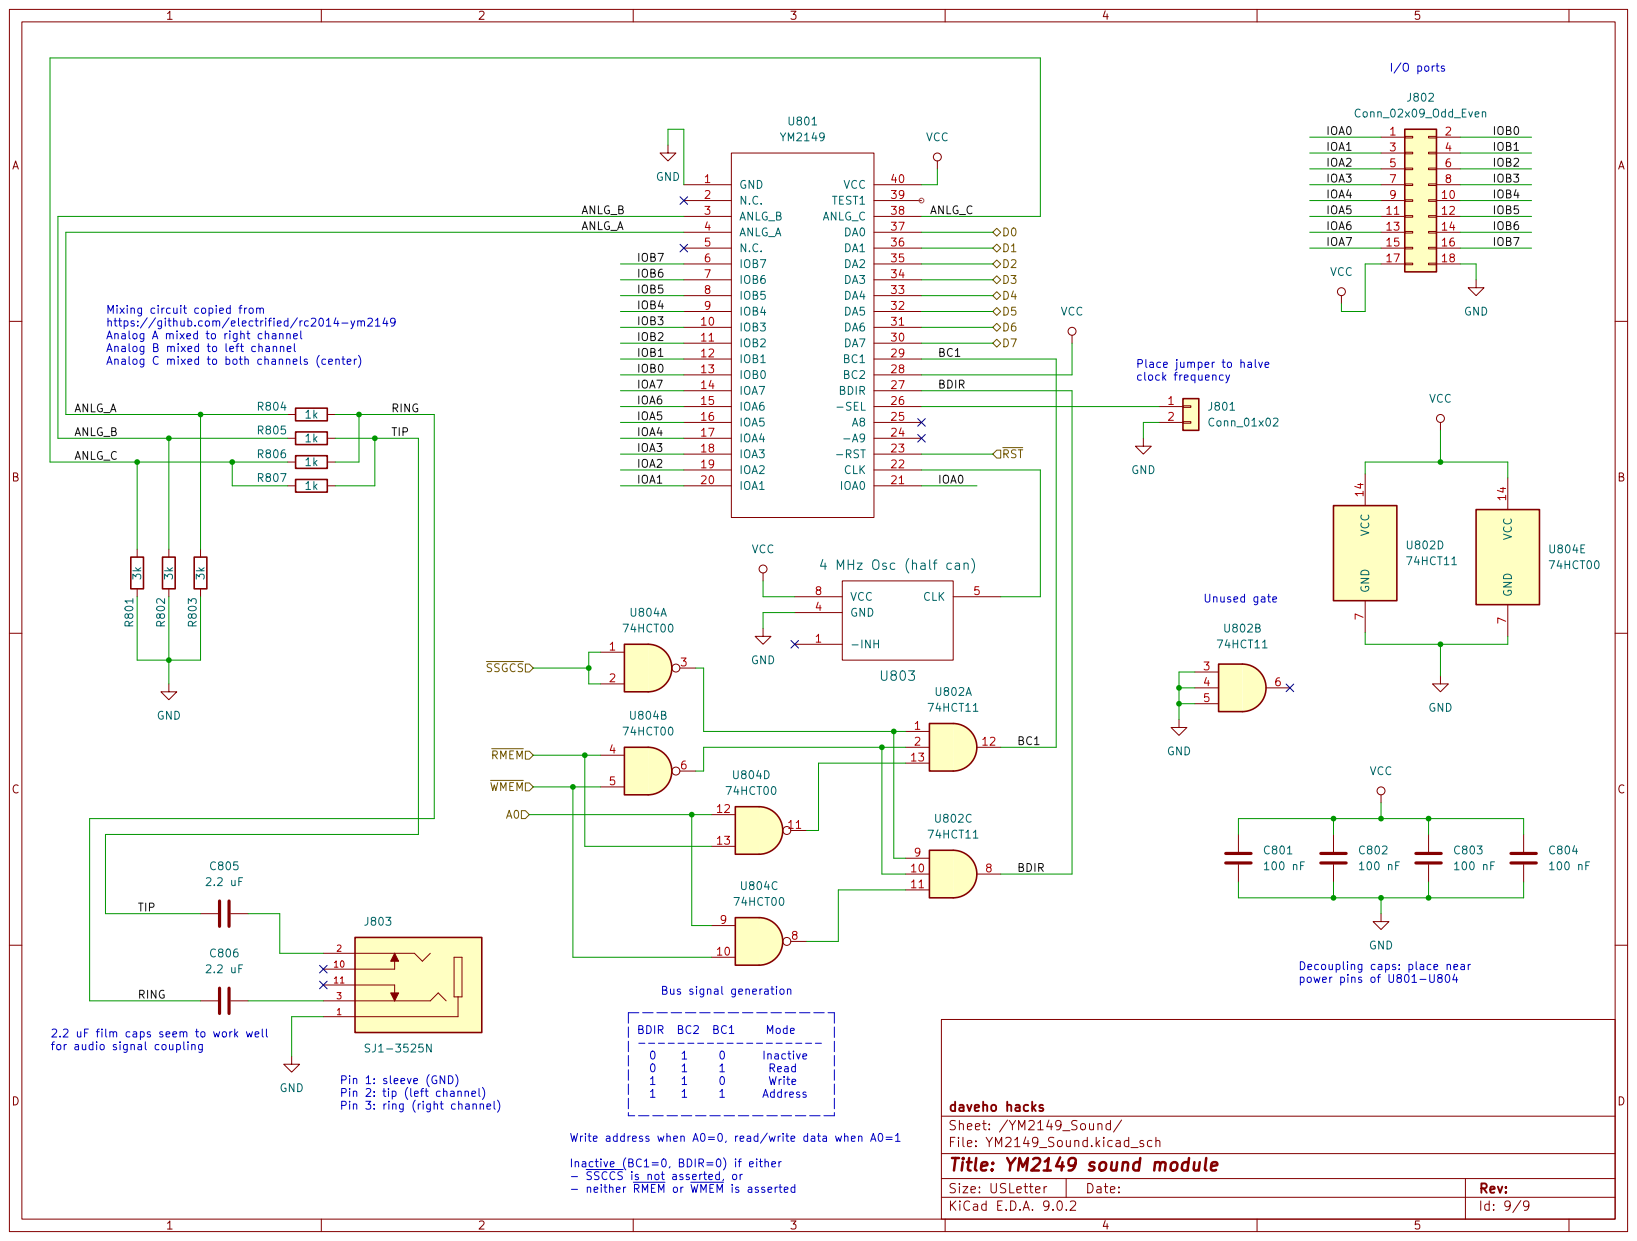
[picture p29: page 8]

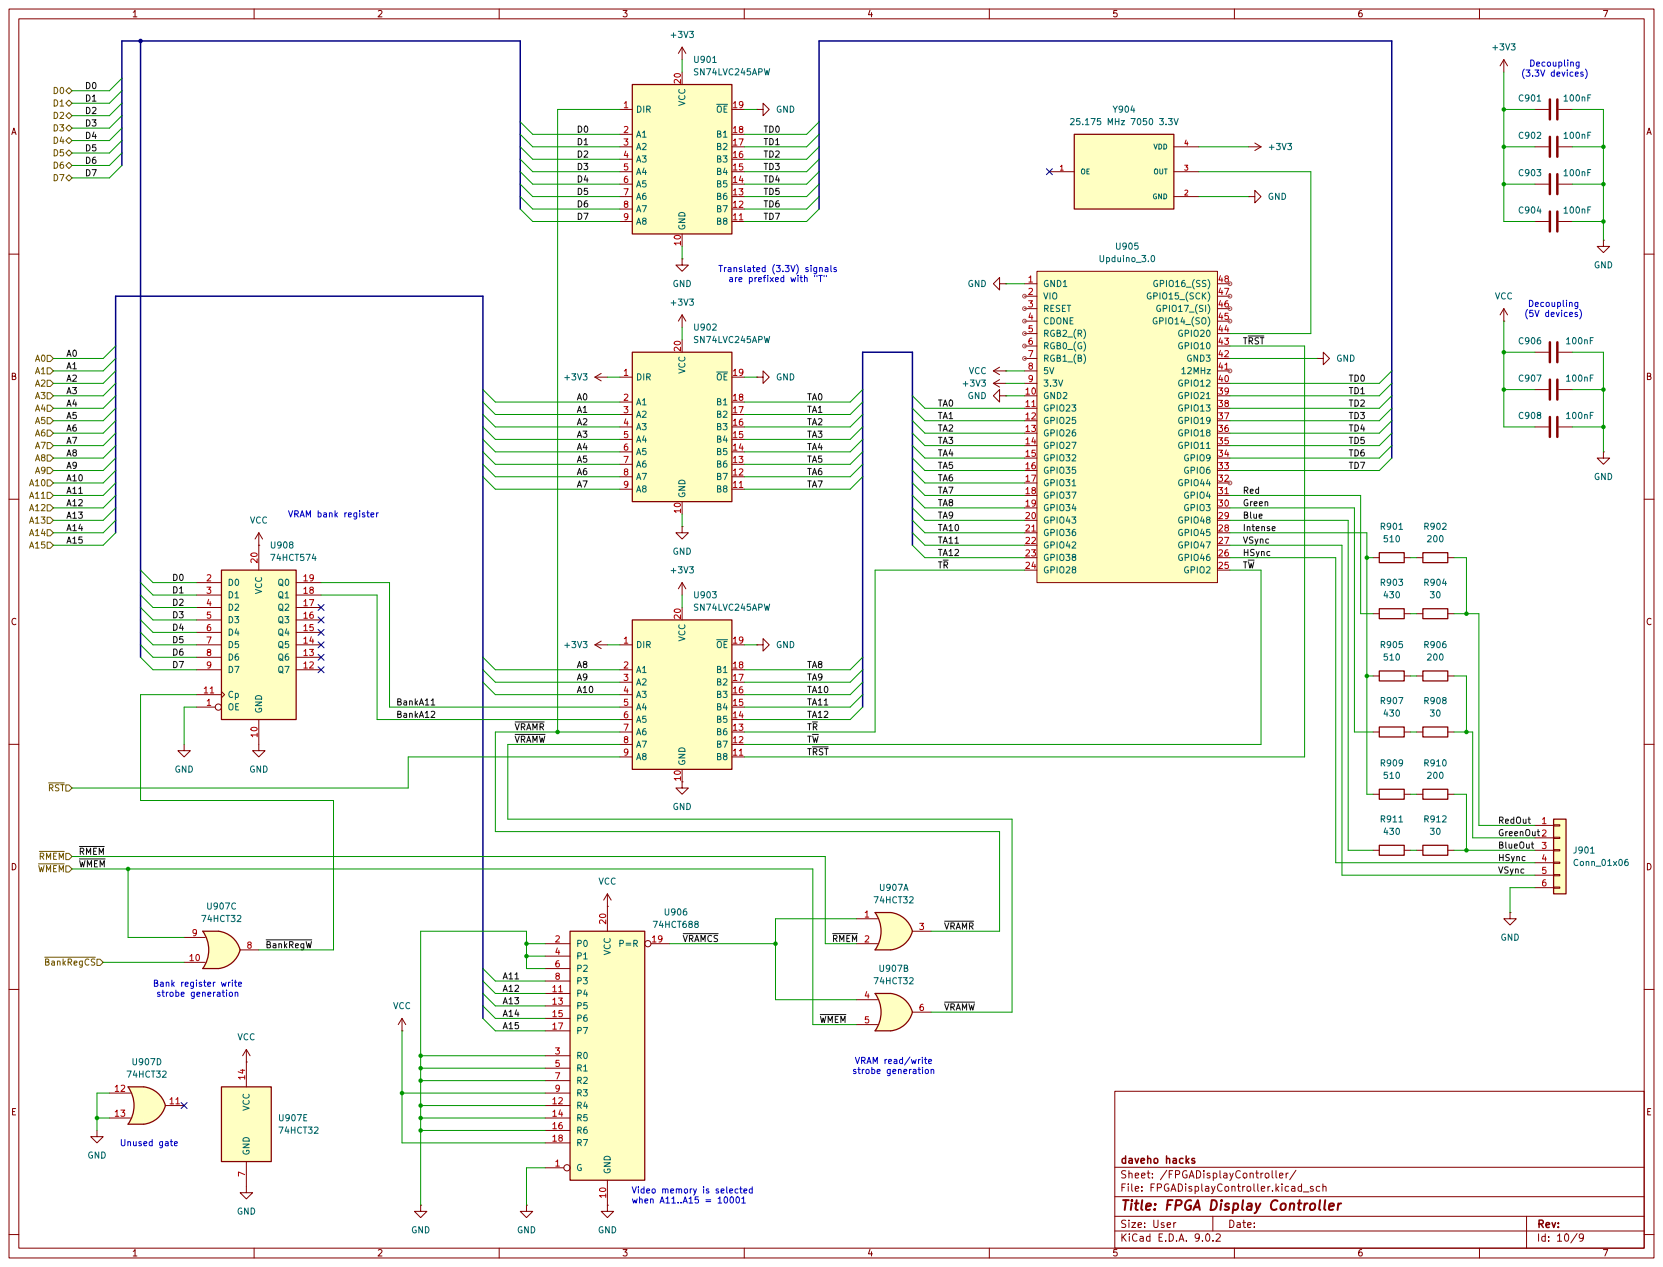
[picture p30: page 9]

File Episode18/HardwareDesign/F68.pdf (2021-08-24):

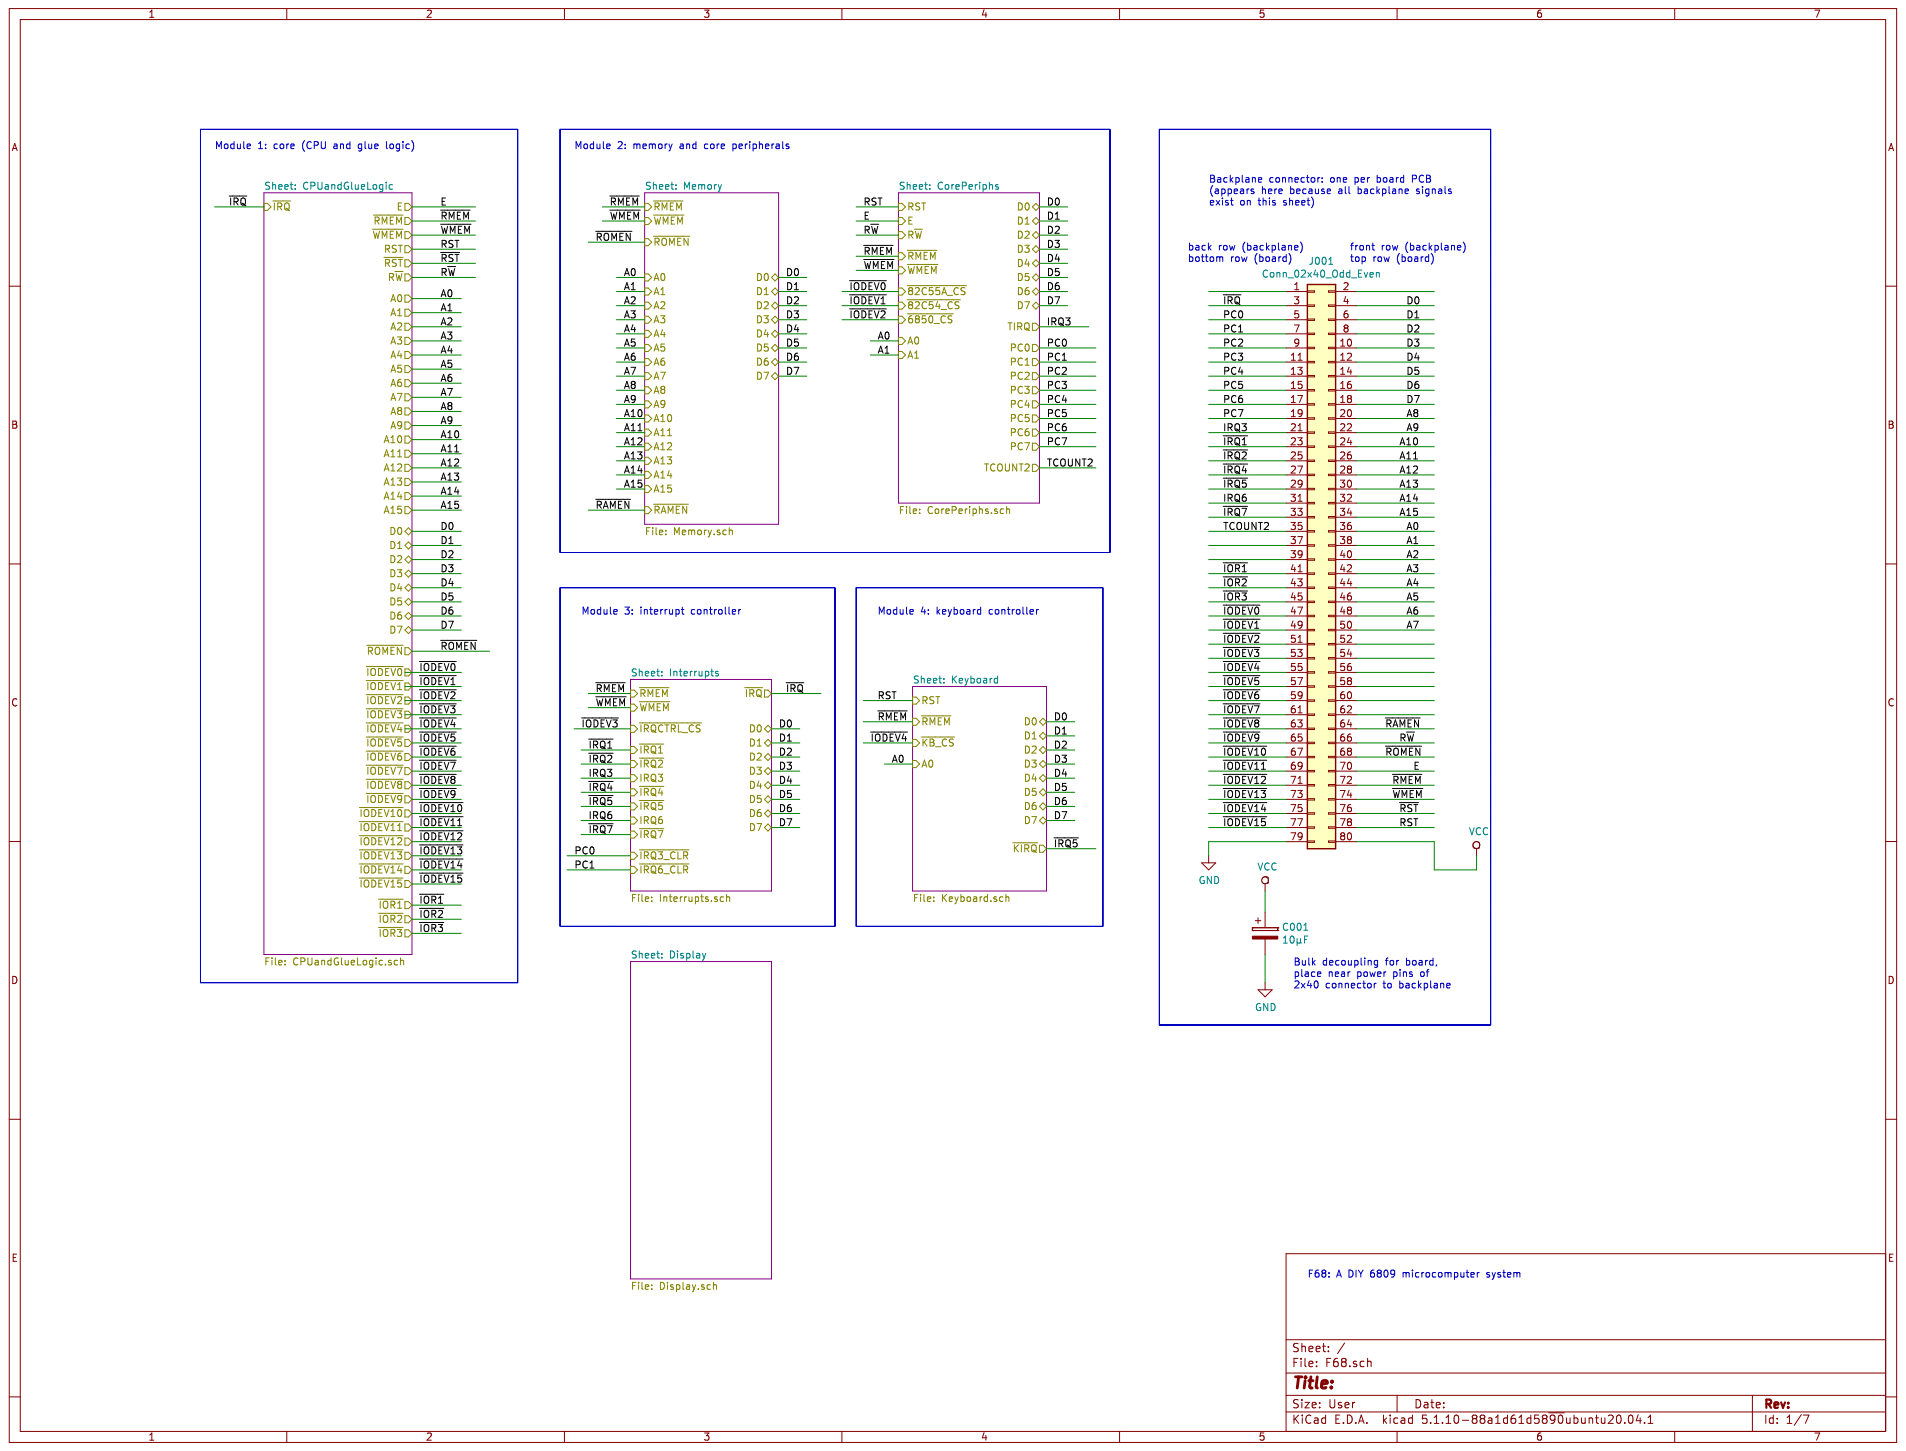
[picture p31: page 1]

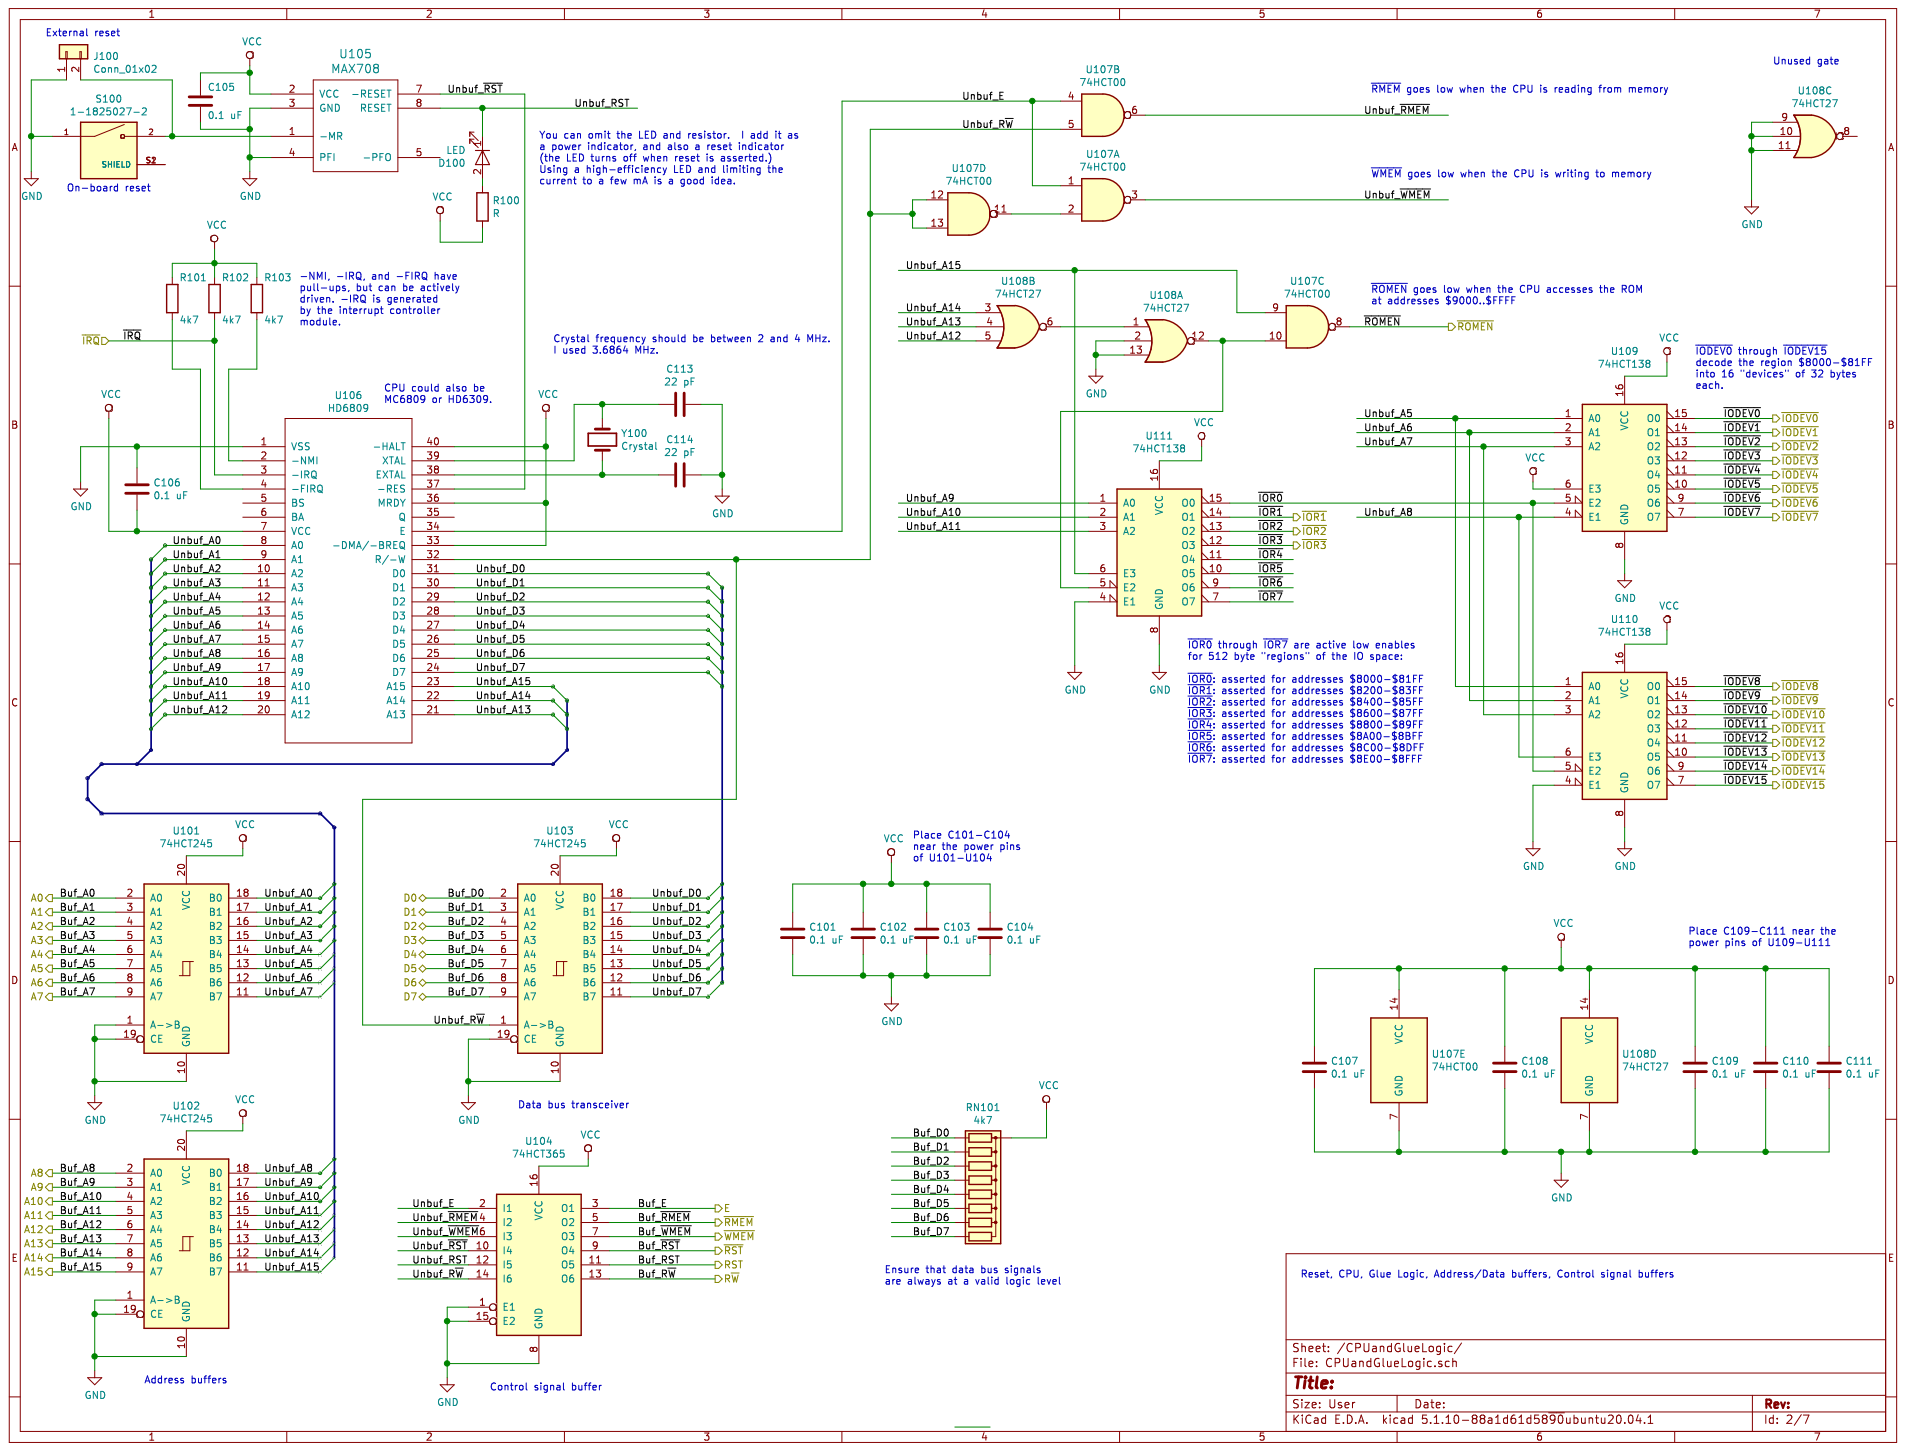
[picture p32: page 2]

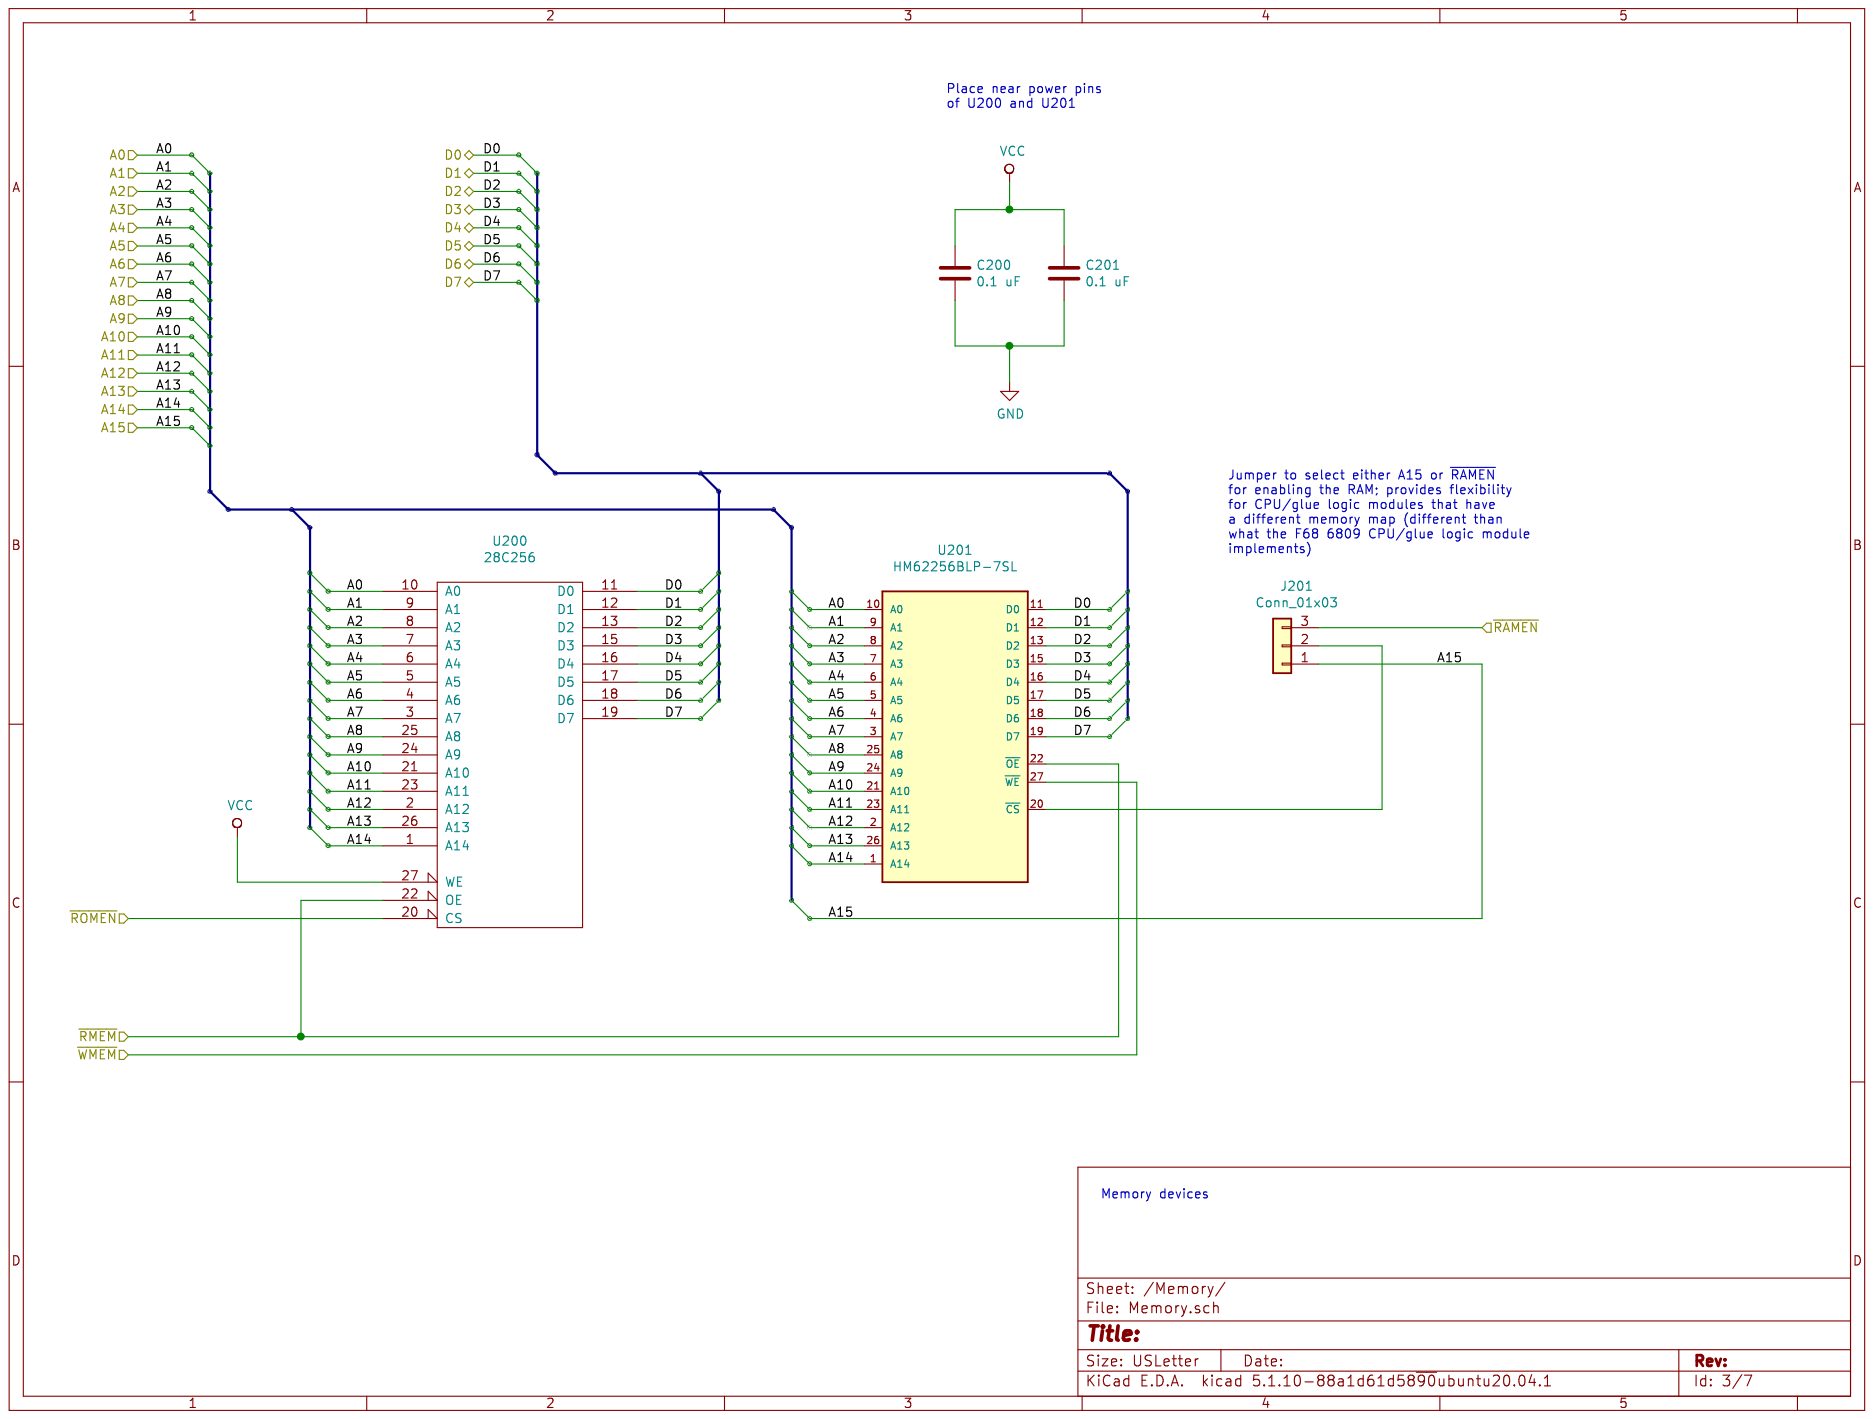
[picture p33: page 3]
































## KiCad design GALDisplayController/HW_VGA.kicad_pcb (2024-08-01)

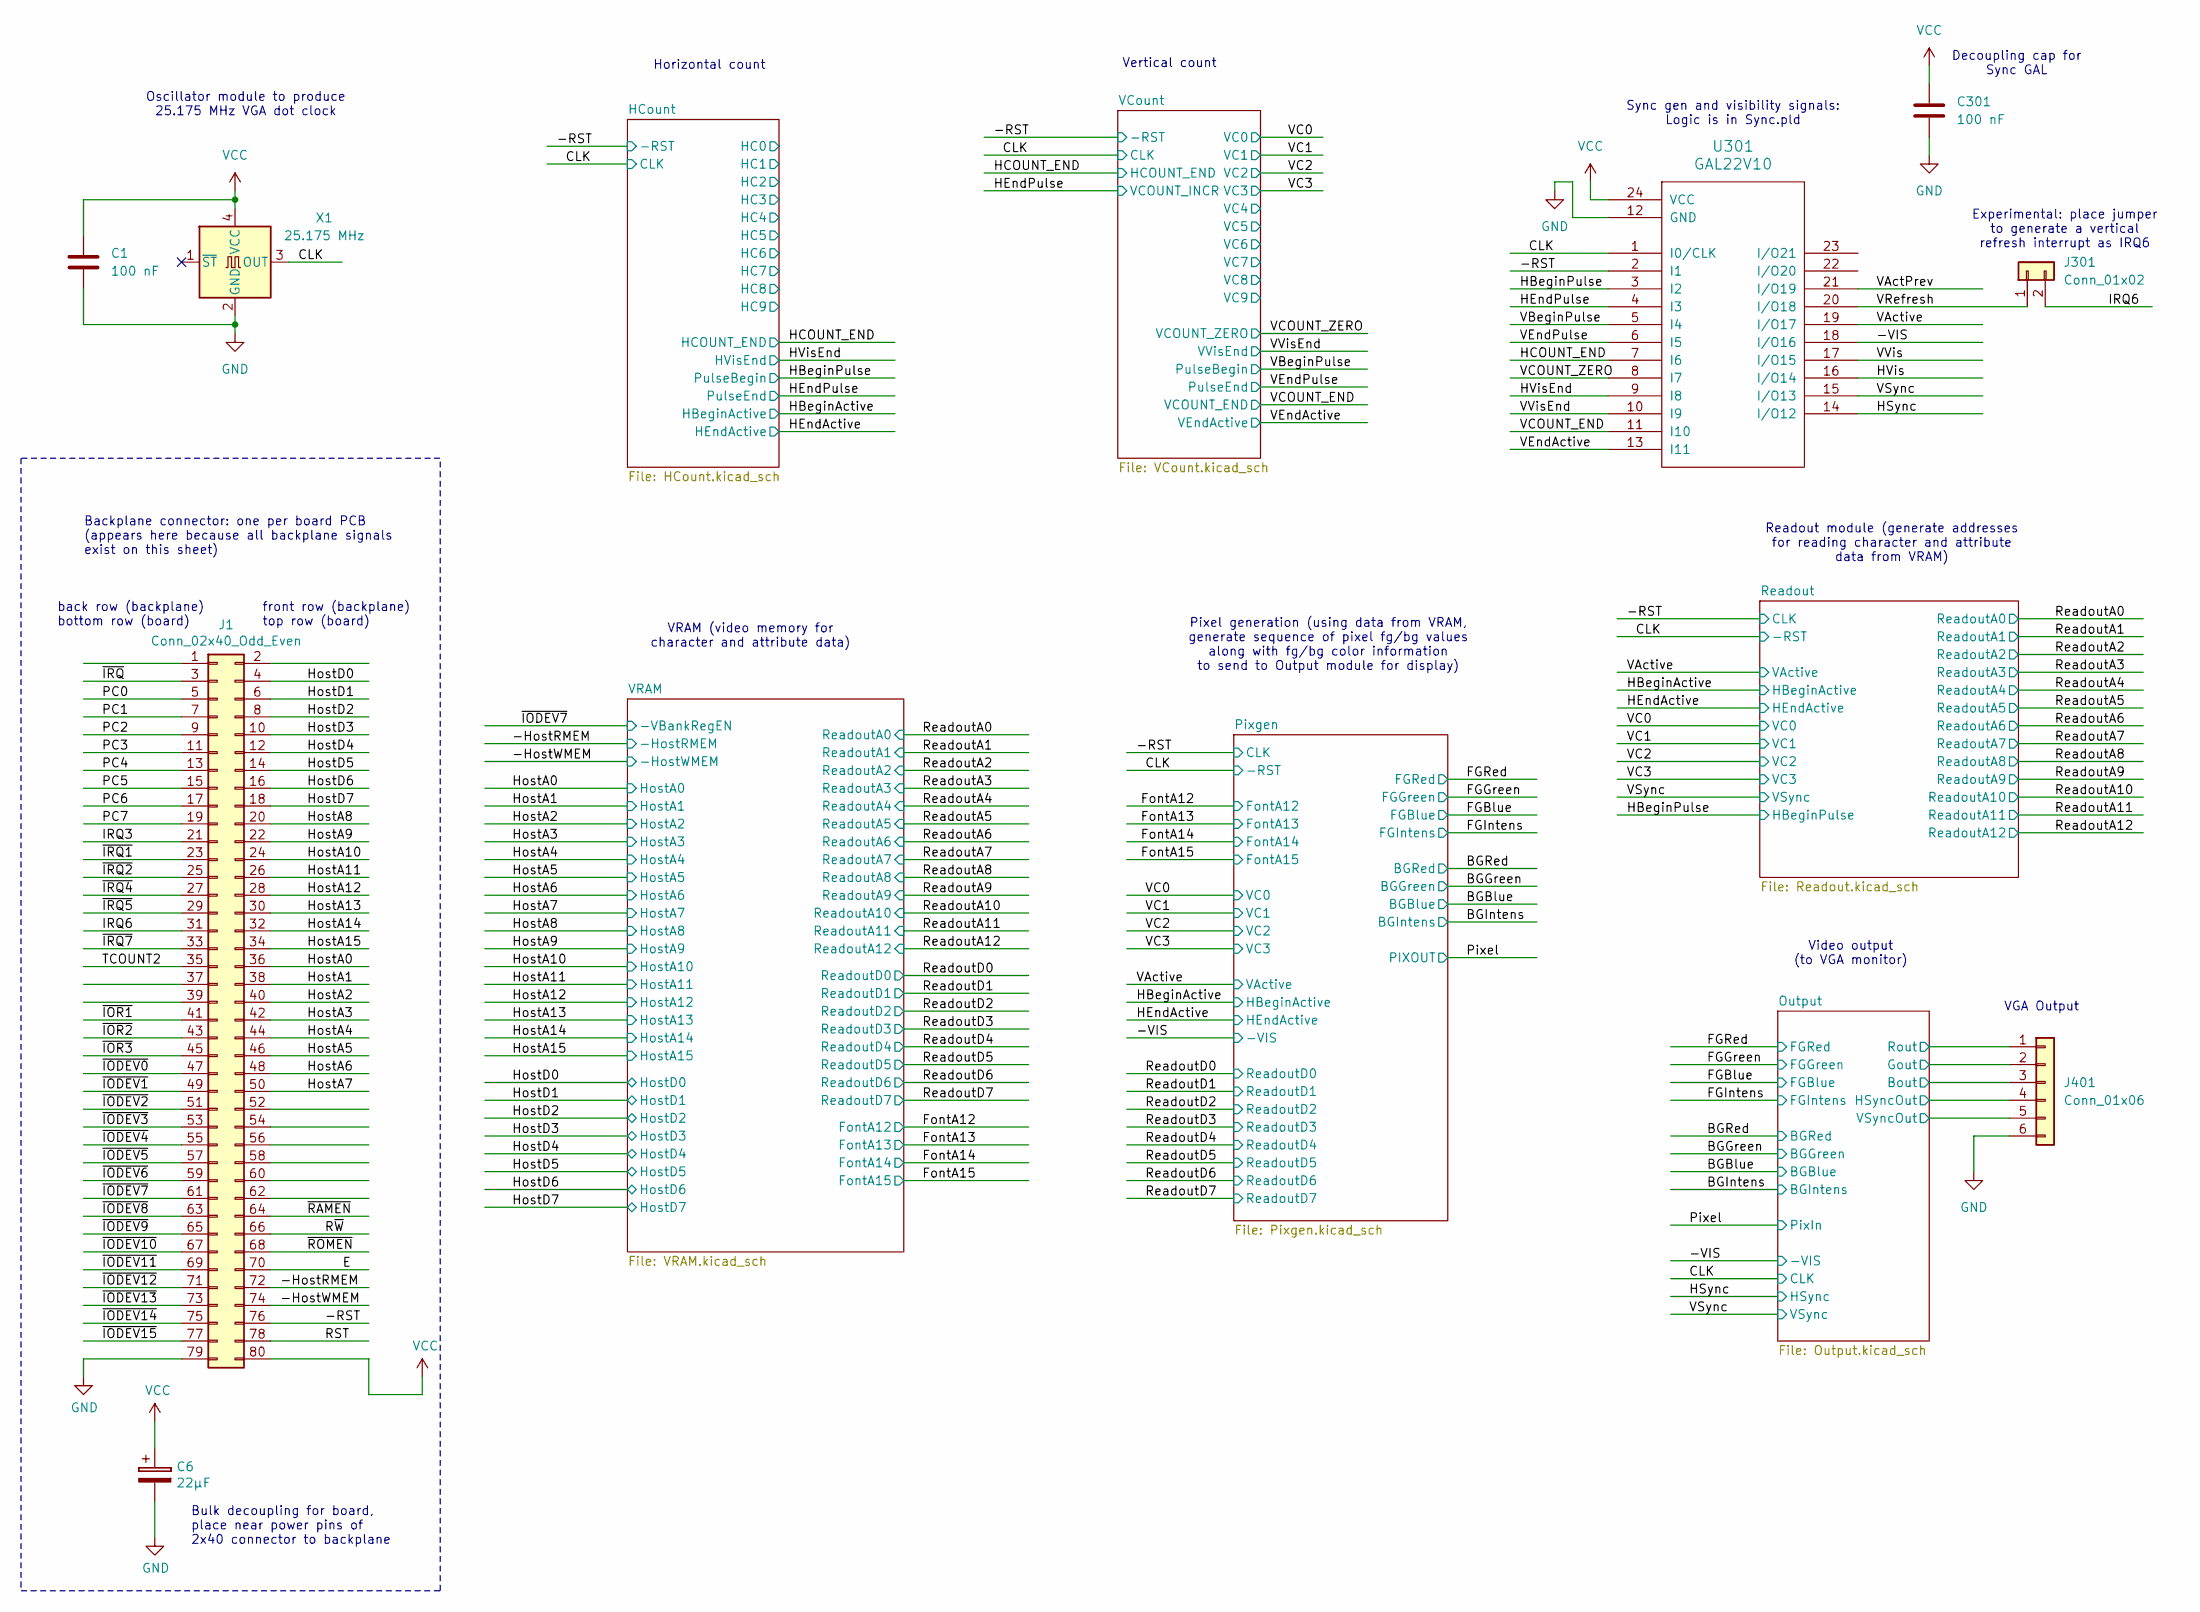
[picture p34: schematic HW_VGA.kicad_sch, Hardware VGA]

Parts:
C1, C301: 100 nF; C_0805_2012Metric_Pad1.18x1.45mm_HandSolder
C6: 22μF; CP_Radial_D6.3mm_P2.50mm
J1: Conn_02x40_Odd_Even; PinHeader_2x40_P2.54mm_Vertical
J301: Conn_01x02; PinHeader_1x02_P2.54mm_Vertical
J401: Conn_01x06; PinHeader_1x06_P2.54mm_Vertical
U301: GAL22V10; SOIC-24W_7.5x15.4mm_P1.27mm
X1: 25.175 MHz; SG-636P

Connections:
/-HostRMEM: J1.72; also elsewhere on the board
/-HostWMEM: J1.74; also elsewhere on the board
/-RST: J1.76, U301.2 (I1); also elsewhere on the board
/-VIS: U301.18 (I/O16); also elsewhere on the board
/CLK: U301.1 (I0/CLK), X1.3 (OUT); also elsewhere on the board
/E: J1.70
/HBeginPulse: U301.3 (I2); also elsewhere on the board
/HCOUNT_END: U301.7 (I6); also elsewhere on the board
/HEndPulse: U301.4 (I3); also elsewhere on the board
/HSync: U301.14 (I/O12); also elsewhere on the board
/HVis: U301.16 (I/O14)
/HVisEnd: U301.9 (I8); also elsewhere on the board
/HostA0: J1.36; also elsewhere on the board
/HostA1: J1.38; also elsewhere on the board
/HostA2: J1.40; also elsewhere on the board
/HostA3: J1.42; also elsewhere on the board
/HostA4: J1.44; also elsewhere on the board
/HostA5: J1.46; also elsewhere on the board
/HostA6: J1.48; also elsewhere on the board
/HostA7: J1.50; also elsewhere on the board
/HostA8: J1.20; also elsewhere on the board
/HostA9: J1.22; also elsewhere on the board
/HostA10: J1.24; also elsewhere on the board
/HostA11: J1.26; also elsewhere on the board
/HostA12: J1.28; also elsewhere on the board
/HostA13: J1.30; also elsewhere on the board
/HostA14: J1.32; also elsewhere on the board
/HostA15: J1.34; also elsewhere on the board
/HostD0: J1.4; also elsewhere on the board
/HostD1: J1.6; also elsewhere on the board
/HostD2: J1.8; also elsewhere on the board
/HostD3: J1.10; also elsewhere on the board
/HostD4: J1.12; also elsewhere on the board
/HostD5: J1.14; also elsewhere on the board
/HostD6: J1.16; also elsewhere on the board
/HostD7: J1.18; also elsewhere on the board
/IRQ3: J1.21
/IRQ6: J1.31, J301.2
/Output/Bout: J401.3; also elsewhere on the board
/Output/Gout: J401.2; also elsewhere on the board
/Output/HSyncOut: J401.4; also elsewhere on the board
/Output/Rout: J401.1; also elsewhere on the board
/Output/VSyncOut: J401.5; also elsewhere on the board
/PC0: J1.5
/PC1: J1.7
/PC2: J1.9
/PC3: J1.11
/PC4: J1.13
/PC5: J1.15
/PC6: J1.17
/PC7: J1.19
/RST: J1.78
/R~W: J1.66
/TCOUNT2: J1.35
/VActPrev: U301.21 (I/O19)
/VActive: U301.19 (I/O17); also elsewhere on the board
/VBeginPulse: U301.5 (I4); also elsewhere on the board
/VCOUNT_END: U301.11 (I10); also elsewhere on the board
/VCOUNT_ZERO: U301.8 (I7); also elsewhere on the board
/VEndActive: U301.13 (I11); also elsewhere on the board
/VEndPulse: U301.6 (I5); also elsewhere on the board
/VRefresh: J301.1, U301.20 (I/O18)
/VSync: U301.15 (I/O13); also elsewhere on the board
/VVis: U301.17 (I/O15)
/VVisEnd: U301.10 (I9); also elsewhere on the board
/~IODEV0: J1.47
/~IODEV1: J1.49
/~IODEV2: J1.51
/~IODEV3: J1.53
/~IODEV4: J1.55
/~IODEV5: J1.57
/~IODEV6: J1.59
/~IODEV7: J1.61; also elsewhere on the board
/~IODEV8: J1.63
/~IODEV9: J1.65
/~IODEV10: J1.67
/~IODEV11: J1.69
/~IODEV12: J1.71
/~IODEV13: J1.73
/~IODEV14: J1.75
/~IODEV15: J1.77
/~IOR1: J1.41
/~IOR2: J1.43
/~IOR3: J1.45
/~IRQ1: J1.23
/~IRQ2: J1.25
/~IRQ4: J1.27
/~IRQ5: J1.29
/~IRQ7: J1.33
/~IRQ: J1.3
/~RAMEN: J1.64
/~ROMEN: J1.68
GND: C1.2, C6.2, C301.2, J1.79, J401.6, U301.12 (GND), X1.2 (GND); also elsewhere on the board
VCC: C1.1, C6.1, C301.1, J1.80, U301.24 (VCC), X1.4 (VCC); also elsewhere on the board

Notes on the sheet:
Backplane connector: one per board PCB (appears here because all backplane signals exist on this sheet)
Decoupling cap for Sync GAL
Sync gen and visibility signals: Logic is in Sync.pld
VRAM (video memory for character and attribute data)
VGA Output
Oscillator module to produce 25.175 MHz VGA dot clock
back row (backplane) bottom row (board)
Bulk decoupling for board, place near power pins of 2x40 connector to backplane
Pixel generation (using data from VRAM, generate sequence of pixel fg/bg values along with fg/bg color information to send to Output module for display)
front row (backplane) top row (board)
Experimental: place jumper to generate a vertical refresh interrupt as IRQ6
Horizontal count
Vertical count
Video output (to VGA monitor)
Readout module (generate addresses for reading character and attribute data from VRAM)

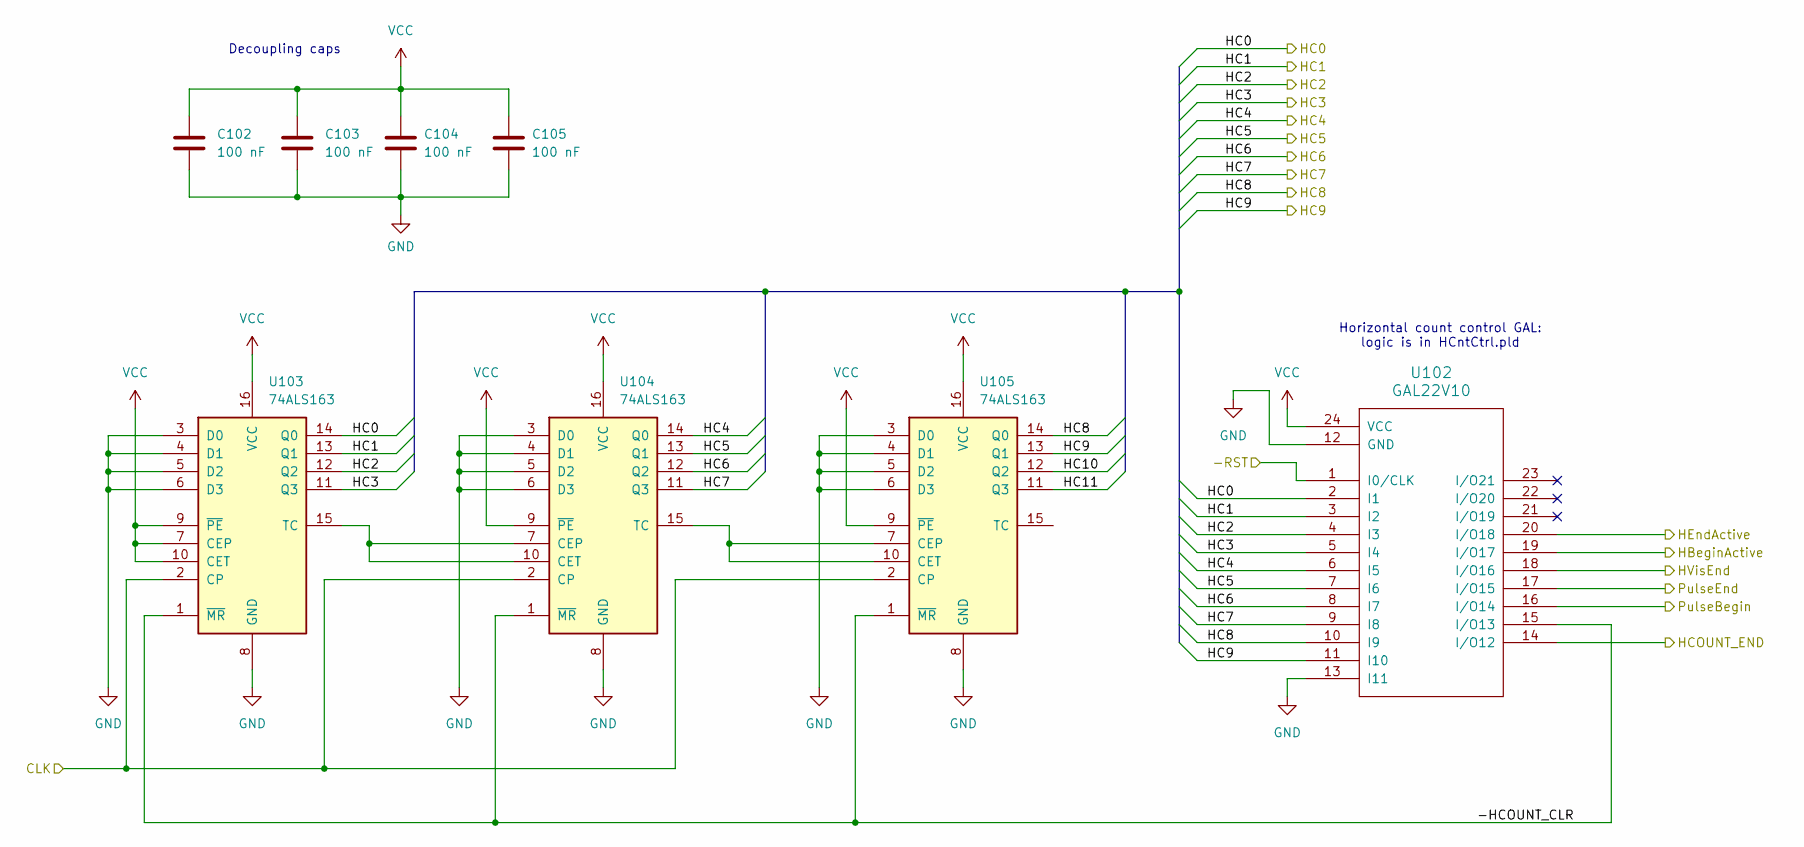
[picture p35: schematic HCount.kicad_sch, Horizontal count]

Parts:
C102, C103, C104, C105: 100 nF; C_0805_2012Metric_Pad1.18x1.45mm_HandSolder
U102: GAL22V10; SOIC-24W_7.5x15.4mm_P1.27mm
U103, U104, U105: 74ALS163; SOIC-16W_5.3x10.2mm_P1.27mm

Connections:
/-RST: U102.1 (I0/CLK); also elsewhere on the board
/CLK: U103.2 (CP), U104.2 (CP), U105.2 (CP); also elsewhere on the board
/HBeginActive: U102.19 (I/O17); also elsewhere on the board
/HBeginPulse: U102.16 (I/O14); also elsewhere on the board
/HCOUNT_END: U102.14 (I/O12); also elsewhere on the board
/HCount/-HCOUNT_CLR: U102.15 (I/O13), U103.1 (~MR), U104.1 (~MR), U105.1 (~MR)
/HCount/HC0: U102.2 (I1), U103.14 (Q0)
/HCount/HC1: U102.3 (I2), U103.13 (Q1)
/HCount/HC2: U102.4 (I3), U103.12 (Q2)
/HCount/HC3: U102.5 (I4), U103.11 (Q3)
/HCount/HC4: U102.6 (I5), U104.14 (Q0)
/HCount/HC5: U102.7 (I6), U104.13 (Q1)
/HCount/HC6: U102.8 (I7), U104.12 (Q2)
/HCount/HC7: U102.9 (I8), U104.11 (Q3)
/HCount/HC8: U102.10 (I9), U105.14 (Q0)
/HCount/HC9: U102.11 (I10), U105.13 (Q1)
/HCount/HC10: U105.12 (Q2)
/HCount/HC11: U105.11 (Q3)
/HEndActive: U102.20 (I/O18); also elsewhere on the board
/HEndPulse: U102.17 (I/O15); also elsewhere on the board
/HVisEnd: U102.18 (I/O16); also elsewhere on the board
GND: C102.2, C103.2, C104.2, C105.2, U102.12 (GND), U102.13 (I11), U103.3 (D0), U103.4 (D1), U103.5 (D2), U103.6 (D3), U103.8 (GND), U104.3 (D0), U104.4 (D1), U104.5 (D2), U104.6 (D3), U104.8 (GND), U105.3 (D0), U105.4 (D1), U105.5 (D2), U105.6 (D3), U105.8 (GND); also elsewhere on the board
unnamed: U103.15 (TC), U104.7 (CEP), U104.10 (CET)
unnamed: U104.15 (TC), U105.7 (CEP), U105.10 (CET)
VCC: C102.1, C103.1, C104.1, C105.1, U102.24 (VCC), U103.7 (CEP), U103.9 (~PE), U103.10 (CET), U103.16 (VCC), U104.9 (~PE), U104.16 (VCC), U105.9 (~PE), U105.16 (VCC); also elsewhere on the board

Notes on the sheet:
Horizontal count control GAL: logic is in HCntCtrl.pld
Decoupling caps

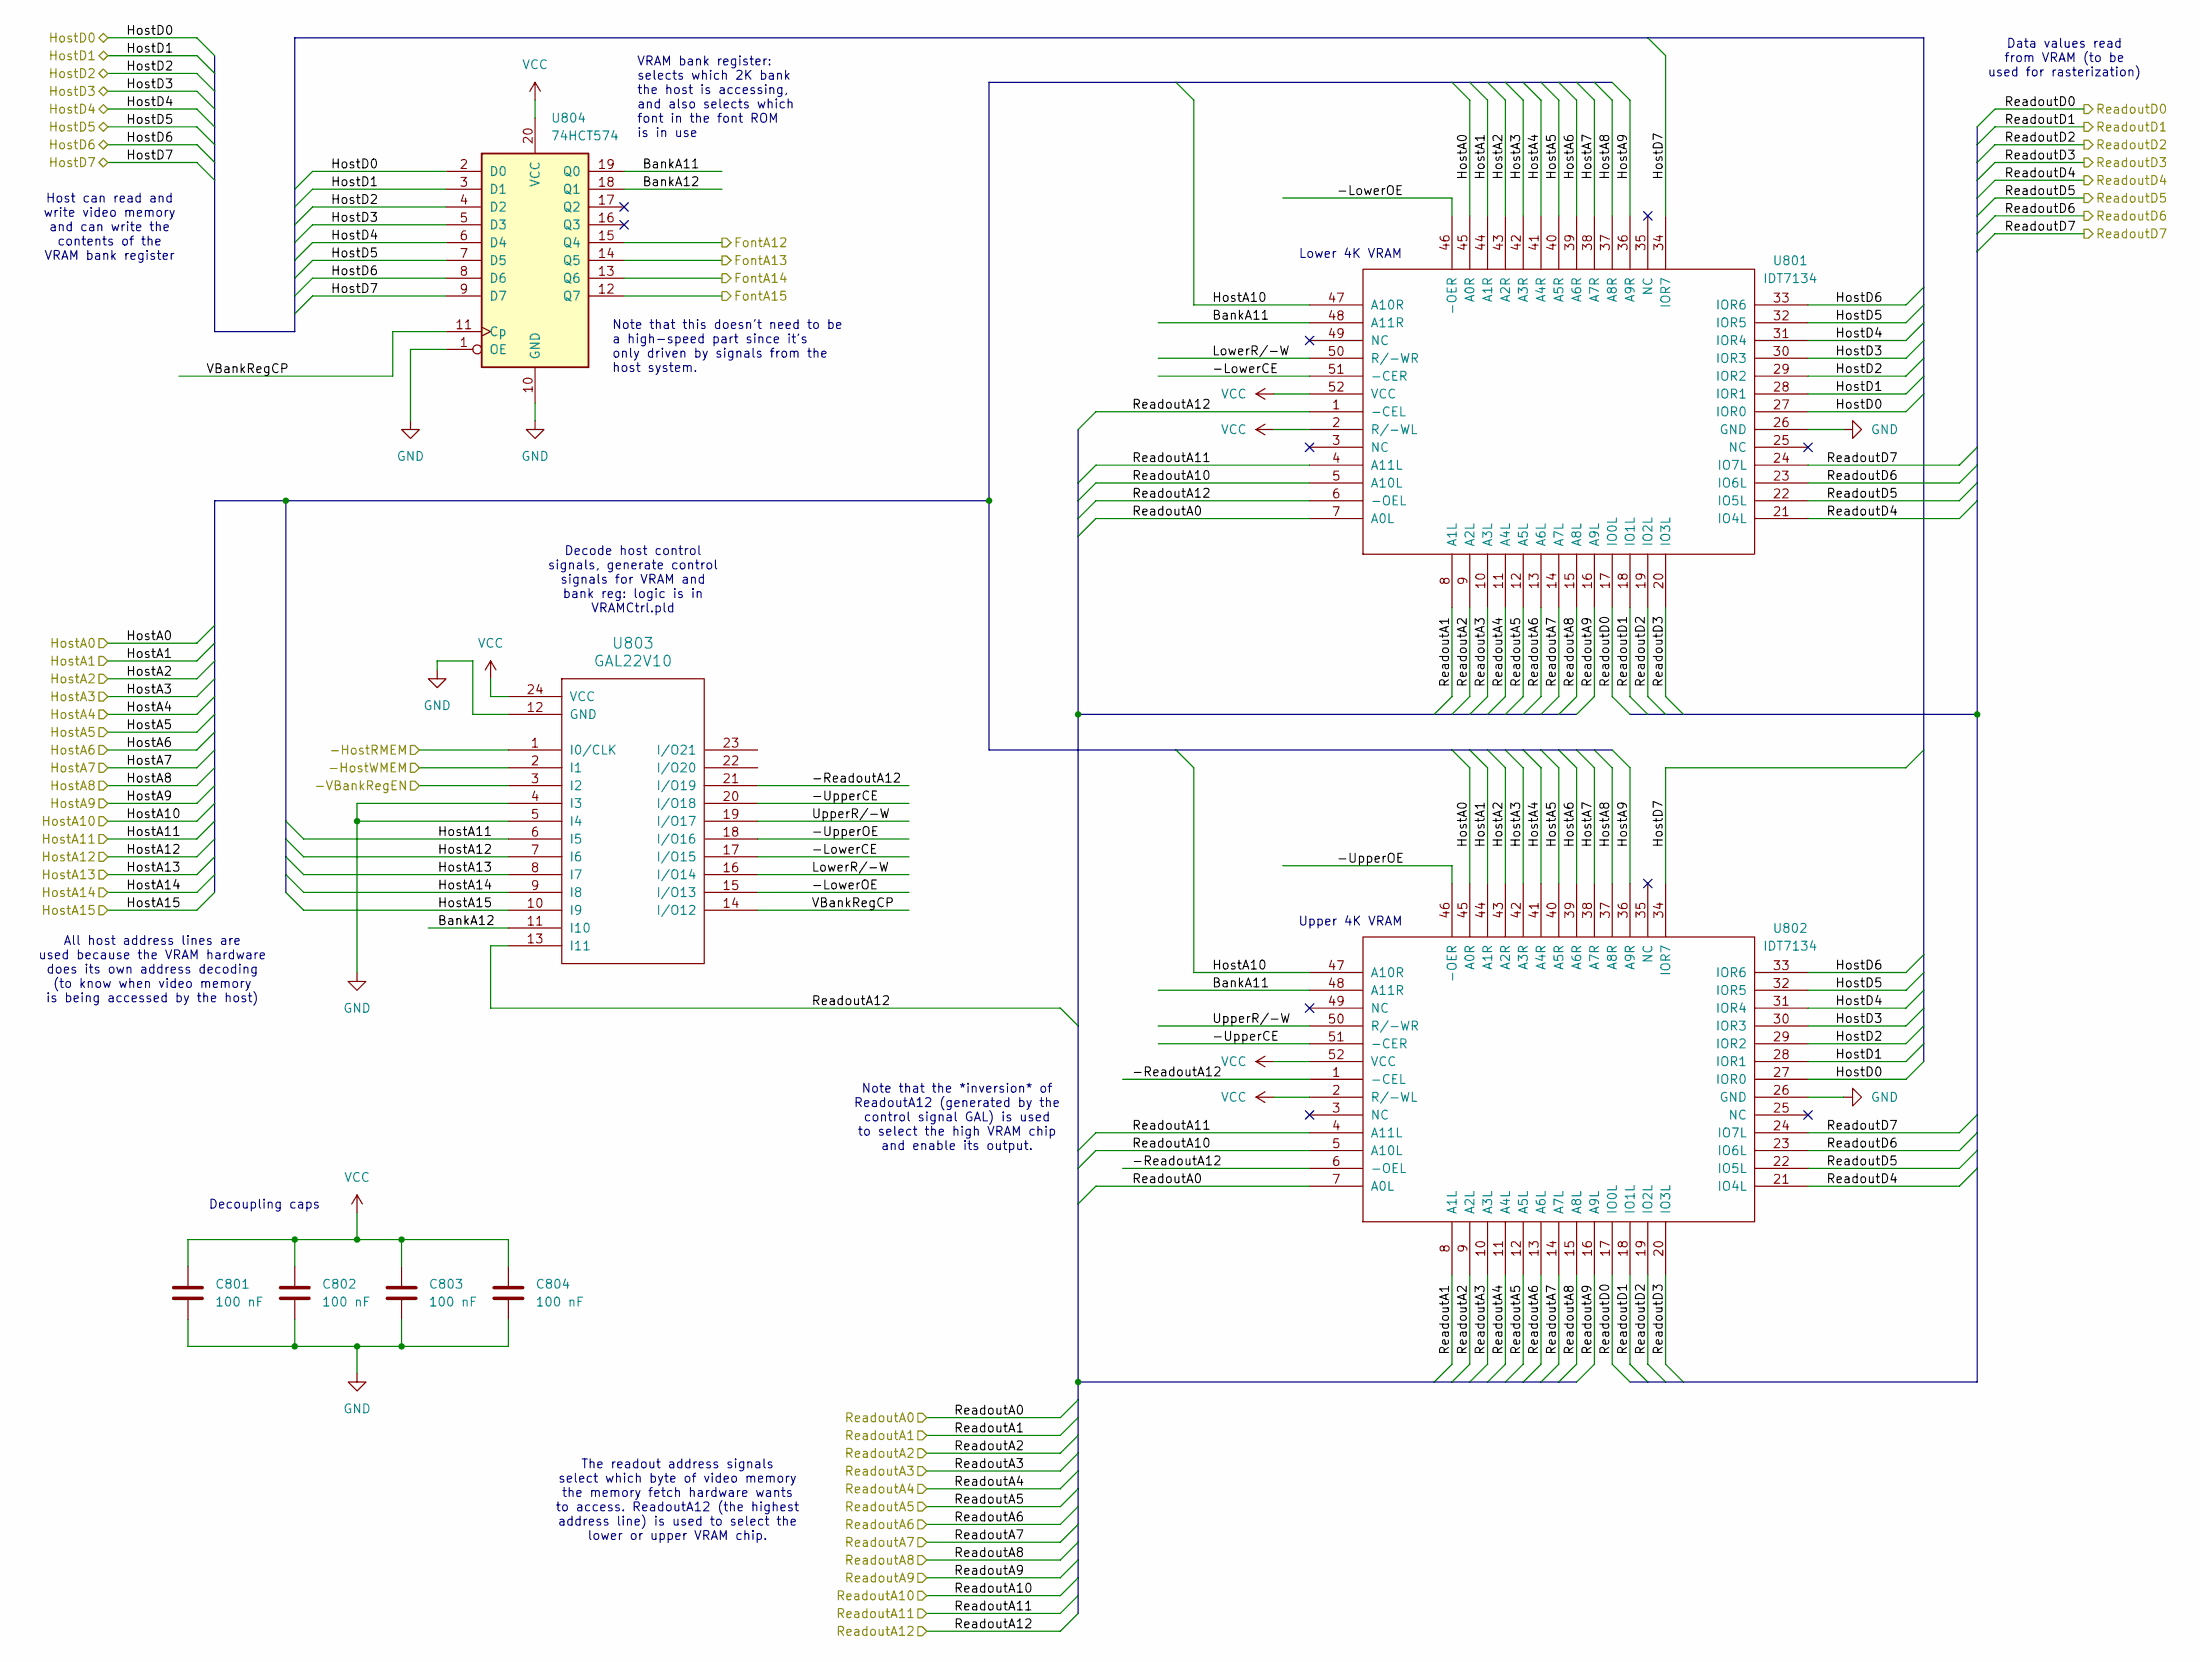
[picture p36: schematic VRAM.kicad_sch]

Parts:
C801, C802, C803, C804: 100 nF; C_0805_2012Metric_Pad1.18x1.45mm_HandSolder
U801, U802: IDT7134; PLCC-52_THT-Socket
U803: GAL22V10; SOIC-24W_7.5x15.4mm_P1.27mm
U804: 74HCT574; SOIC-20W_7.5x12.8mm_P1.27mm

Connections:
/-HostRMEM: U803.1 (I0/CLK); also elsewhere on the board
/-HostWMEM: U803.2 (I1); also elsewhere on the board
/FontA12: U804.15 (Q4); also elsewhere on the board
/FontA13: U804.14 (Q5); also elsewhere on the board
/FontA14: U804.13 (Q6); also elsewhere on the board
/FontA15: U804.12 (Q7); also elsewhere on the board
/HostA0: U801.45 (A0R), U802.45 (A0R); also elsewhere on the board
/HostA1: U801.44 (A1R), U802.44 (A1R); also elsewhere on the board
/HostA2: U801.43 (A2R), U802.43 (A2R); also elsewhere on the board
/HostA3: U801.42 (A3R), U802.42 (A3R); also elsewhere on the board
/HostA4: U801.41 (A4R), U802.41 (A4R); also elsewhere on the board
/HostA5: U801.40 (A5R), U802.40 (A5R); also elsewhere on the board
/HostA6: U801.39 (A6R), U802.39 (A6R); also elsewhere on the board
/HostA7: U801.38 (A7R), U802.38 (A7R); also elsewhere on the board
/HostA8: U801.37 (A8R), U802.37 (A8R); also elsewhere on the board
/HostA9: U801.36 (A9R), U802.36 (A9R); also elsewhere on the board
/HostA10: U801.47 (A10R), U802.47 (A10R); also elsewhere on the board
/HostA11: U803.6 (I5); also elsewhere on the board
/HostA12: U803.7 (I6); also elsewhere on the board
/HostA13: U803.8 (I7); also elsewhere on the board
/HostA14: U803.9 (I8); also elsewhere on the board
/HostA15: U803.10 (I9); also elsewhere on the board
/HostD0: U801.27 (IOR0), U802.27 (IOR0), U804.2 (D0); also elsewhere on the board
/HostD1: U801.28 (IOR1), U802.28 (IOR1), U804.3 (D1); also elsewhere on the board
/HostD2: U801.29 (IOR2), U802.29 (IOR2), U804.4 (D2); also elsewhere on the board
/HostD3: U801.30 (IOR3), U802.30 (IOR3), U804.5 (D3); also elsewhere on the board
/HostD4: U801.31 (IOR4), U802.31 (IOR4), U804.6 (D4); also elsewhere on the board
/HostD5: U801.32 (IOR5), U802.32 (IOR5), U804.7 (D5); also elsewhere on the board
/HostD6: U801.33 (IOR6), U802.33 (IOR6), U804.8 (D6); also elsewhere on the board
/HostD7: U801.34 (IOR7), U802.34 (IOR7), U804.9 (D7); also elsewhere on the board
/ReadoutA0: U801.7 (A0L), U802.7 (A0L); also elsewhere on the board
/ReadoutA1: U801.8 (A1L), U802.8 (A1L); also elsewhere on the board
/ReadoutA2: U801.9 (A2L), U802.9 (A2L); also elsewhere on the board
/ReadoutA3: U801.10 (A3L), U802.10 (A3L); also elsewhere on the board
/ReadoutA4: U801.11 (A4L), U802.11 (A4L); also elsewhere on the board
/ReadoutA5: U801.12 (A5L), U802.12 (A5L); also elsewhere on the board
/ReadoutA6: U801.13 (A6L), U802.13 (A6L); also elsewhere on the board
/ReadoutA7: U801.14 (A7L), U802.14 (A7L); also elsewhere on the board
/ReadoutA8: U801.15 (A8L), U802.15 (A8L); also elsewhere on the board
/ReadoutA9: U801.16 (A9L), U802.16 (A9L); also elsewhere on the board
/ReadoutA10: U801.5 (A10L), U802.5 (A10L); also elsewhere on the board
/ReadoutA11: U801.4 (A11L), U802.4 (A11L); also elsewhere on the board
/ReadoutA12: U801.1 (-CEL), U801.6 (-OEL), U803.13 (I11); also elsewhere on the board
/ReadoutD0: U801.17 (IO0L), U802.17 (IO0L); also elsewhere on the board
/ReadoutD1: U801.18 (IO1L), U802.18 (IO1L); also elsewhere on the board
/ReadoutD2: U801.19 (IO2L), U802.19 (IO2L); also elsewhere on the board
/ReadoutD3: U801.20 (IO3L), U802.20 (IO3L); also elsewhere on the board
/ReadoutD4: U801.21 (IO4L), U802.21 (IO4L); also elsewhere on the board
/ReadoutD5: U801.22 (IO5L), U802.22 (IO5L); also elsewhere on the board
/ReadoutD6: U801.23 (IO6L), U802.23 (IO6L); also elsewhere on the board
/ReadoutD7: U801.24 (IO7L), U802.24 (IO7L); also elsewhere on the board
/VRAM/-LowerCE: U801.51 (-CER), U803.17 (I/O15)
/VRAM/-LowerOE: U801.46 (-OER), U803.15 (I/O13)
/VRAM/-ReadoutA12: U802.1 (-CEL), U802.6 (-OEL), U803.21 (I/O19)
/VRAM/-UpperCE: U802.51 (-CER), U803.20 (I/O18)
/VRAM/-UpperOE: U802.46 (-OER), U803.18 (I/O16)
/VRAM/BankA11: U801.48 (A11R), U802.48 (A11R), U804.19 (Q0)
/VRAM/BankA12: U803.11 (I10), U804.18 (Q1)
/VRAM/LowerR/-W: U801.50 (R/-WR), U803.16 (I/O14)
/VRAM/UpperR/-W: U802.50 (R/-WR), U803.19 (I/O17)
/VRAM/VBankRegCP: U803.14 (I/O12), U804.11 (Cp)
/~IODEV7: U803.3 (I2); also elsewhere on the board
GND: C801.2, C802.2, C803.2, C804.2, U801.26 (GND), U802.26 (GND), U803.4 (I3), U803.5 (I4), U803.12 (GND), U804.1 (OE), U804.10 (GND); also elsewhere on the board
VCC: C801.1, C802.1, C803.1, C804.1, U801.2 (R/-WL), U801.52 (VCC), U802.2 (R/-WL), U802.52 (VCC), U803.24 (VCC), U804.20 (VCC); also elsewhere on the board

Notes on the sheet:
Decode host control signals, generate control signals for VRAM and bank reg: logic is in VRAMCtrl.pld
Note that this doesn't need to be a high-speed part since it's only driven by signals from the host system.
All host address lines are used because the VRAM hardware does its own address decoding (to know when video memory is being accessed by the host)
Decoupling caps
Lower 4K VRAM
Host can read and write video memory and can write the contents of the VRAM bank register
The readout address signals select which byte of video memory the memory fetch hardware wants to access. ReadoutA12 (the highest address line) is used to select the lower or upper VRAM chip.
VRAM bank register: selects which 2K bank the host is accessing, and also selects which font in the font ROM is in use
Upper 4K VRAM
Data values read from VRAM (to be used for rasterization)
Note that the *inversion* of ReadoutA12 (generated by the control signal GAL) is used to select the high VRAM chip and enable its output.

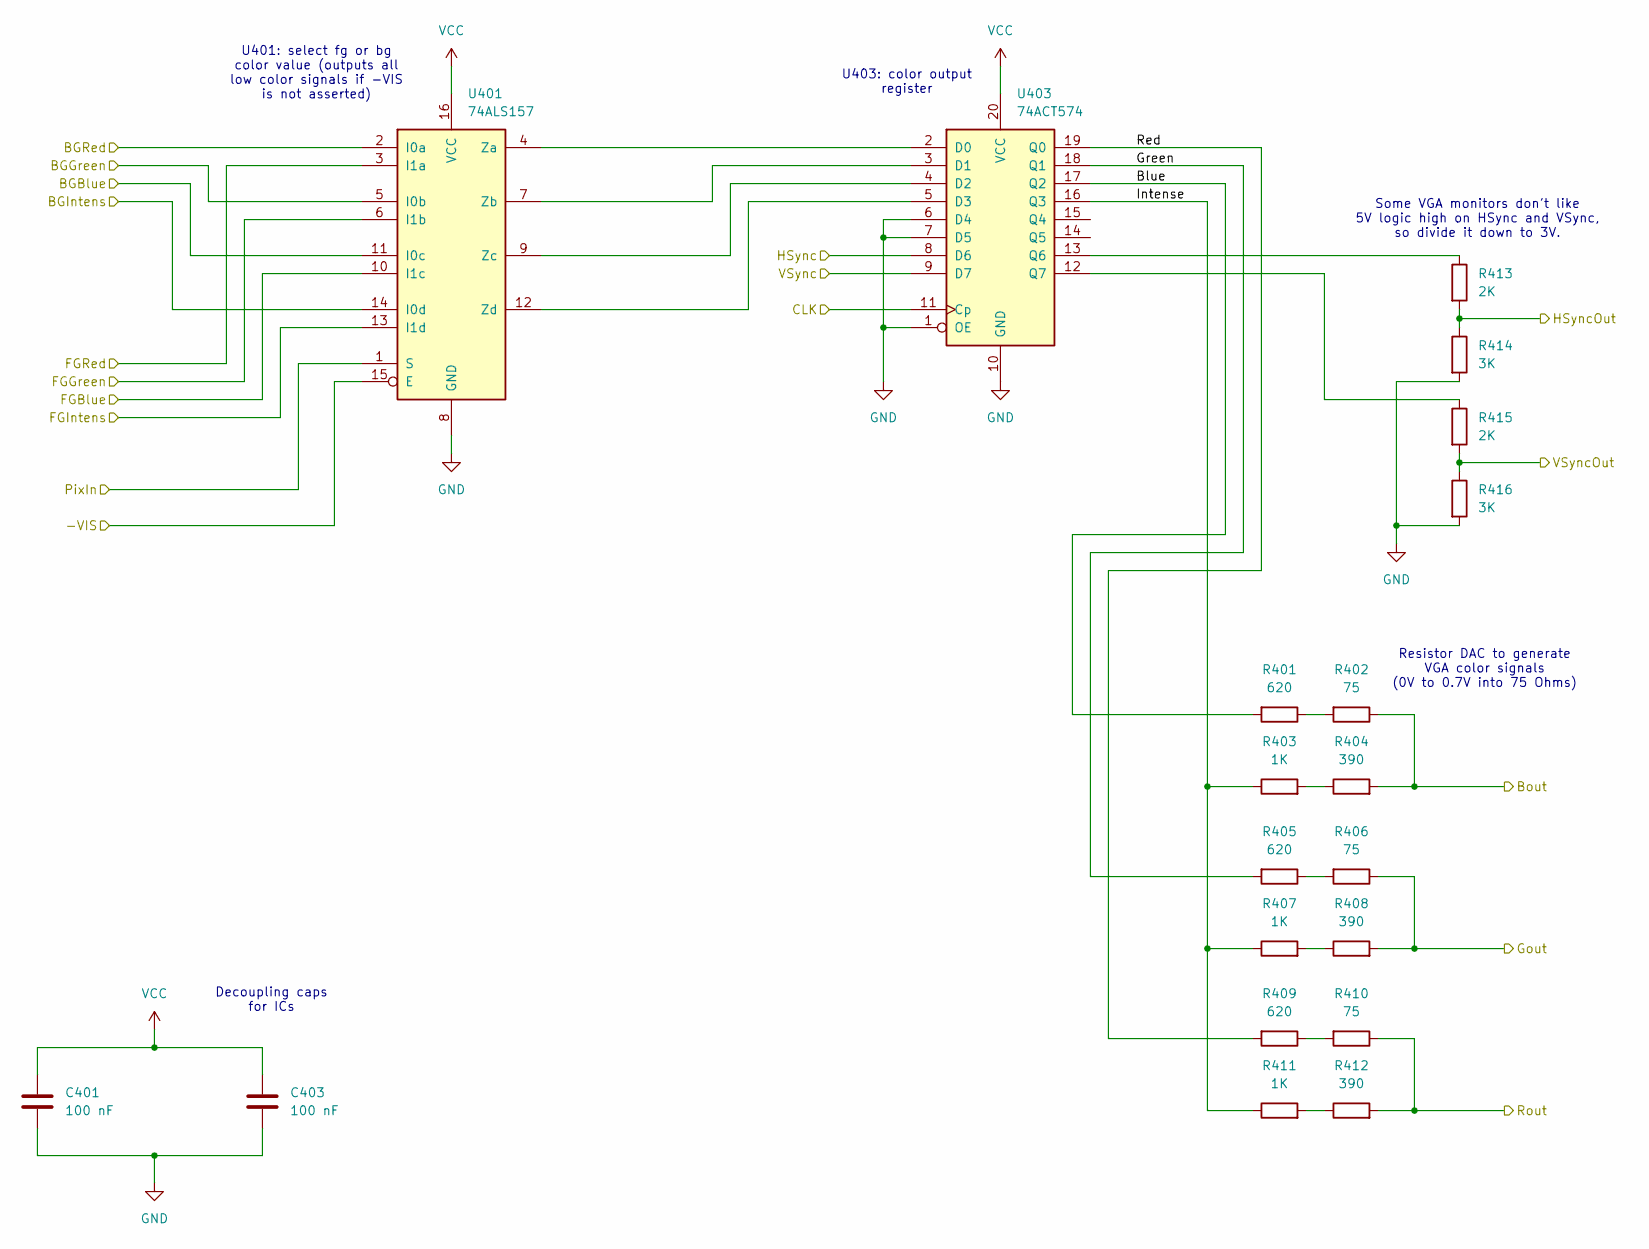
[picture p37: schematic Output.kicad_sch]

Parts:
C401, C403: 100 nF; C_0805_2012Metric_Pad1.18x1.45mm_HandSolder
R401, R405, R409: 620; R_0805_2012Metric_Pad1.20x1.40mm_HandSolder
R402, R406, R410: 75; R_0805_2012Metric_Pad1.20x1.40mm_HandSolder
R403, R407, R411: 1K; R_0805_2012Metric_Pad1.20x1.40mm_HandSolder
R404, R408, R412: 390; R_0805_2012Metric_Pad1.20x1.40mm_HandSolder
R413, R415: 2K; R_0805_2012Metric_Pad1.20x1.40mm_HandSolder
R414, R416: 3K; R_0805_2012Metric_Pad1.20x1.40mm_HandSolder
U401: 74ALS157; SOIC-16W_5.3x10.2mm_P1.27mm
U403: 74ACT574; SOIC-20W_7.5x12.8mm_P1.27mm

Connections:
/-VIS: U401.15 (E); also elsewhere on the board
/BGBlue: U401.11 (I0c); also elsewhere on the board
/BGGreen: U401.5 (I0b); also elsewhere on the board
/BGIntens: U401.14 (I0d); also elsewhere on the board
/BGRed: U401.2 (I0a); also elsewhere on the board
/CLK: U403.11 (Cp); also elsewhere on the board
/FGBlue: U401.10 (I1c); also elsewhere on the board
/FGGreen: U401.6 (I1b); also elsewhere on the board
/FGIntens: U401.13 (I1d); also elsewhere on the board
/FGRed: U401.3 (I1a); also elsewhere on the board
/HSync: U403.8 (D6); also elsewhere on the board
/Output/Blue: R401.2, U403.17 (Q2)
/Output/Bout: R402.1, R404.2; also elsewhere on the board
/Output/Gout: R406.1, R408.2; also elsewhere on the board
/Output/Green: R405.2, U403.18 (Q1)
/Output/HSyncOut: R413.2, R414.1; also elsewhere on the board
/Output/Intense: R403.1, R407.1, R411.1, U403.16 (Q3)
/Output/Red: R409.2, U403.19 (Q0)
/Output/Rout: R410.1, R412.2; also elsewhere on the board
/Output/VSyncOut: R415.2, R416.1; also elsewhere on the board
/Pixel: U401.1 (S); also elsewhere on the board
/VSync: U403.9 (D7); also elsewhere on the board
GND: C401.2, C403.2, R414.2, R416.2, U401.8 (GND), U403.1 (OE), U403.6 (D4), U403.7 (D5), U403.10 (GND); also elsewhere on the board
unnamed: R401.1, R402.2
unnamed: R403.2, R404.1
unnamed: R405.1, R406.2
unnamed: R407.2, R408.1
unnamed: R409.1, R410.2
unnamed: R411.2, R412.1
unnamed: U401.4 (Za), U403.2 (D0)
unnamed: U401.7 (Zb), U403.3 (D1)
unnamed: U401.9 (Zc), U403.4 (D2)
unnamed: U401.12 (Zd), U403.5 (D3)
unnamed: R413.1, U403.13 (Q6)
unnamed: R415.1, U403.12 (Q7)
VCC: C401.1, C403.1, U401.16 (VCC), U403.20 (VCC); also elsewhere on the board

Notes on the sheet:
U403: color output register
Resistor DAC to generate VGA color signals (0V to 0.7V into 75 Ohms)
Decoupling caps for ICs
U401: select fg or bg color value (outputs all low color signals if -VIS is not asserted)
Some VGA monitors don't like 5V logic high on HSync and VSync, so divide it down to 3V.

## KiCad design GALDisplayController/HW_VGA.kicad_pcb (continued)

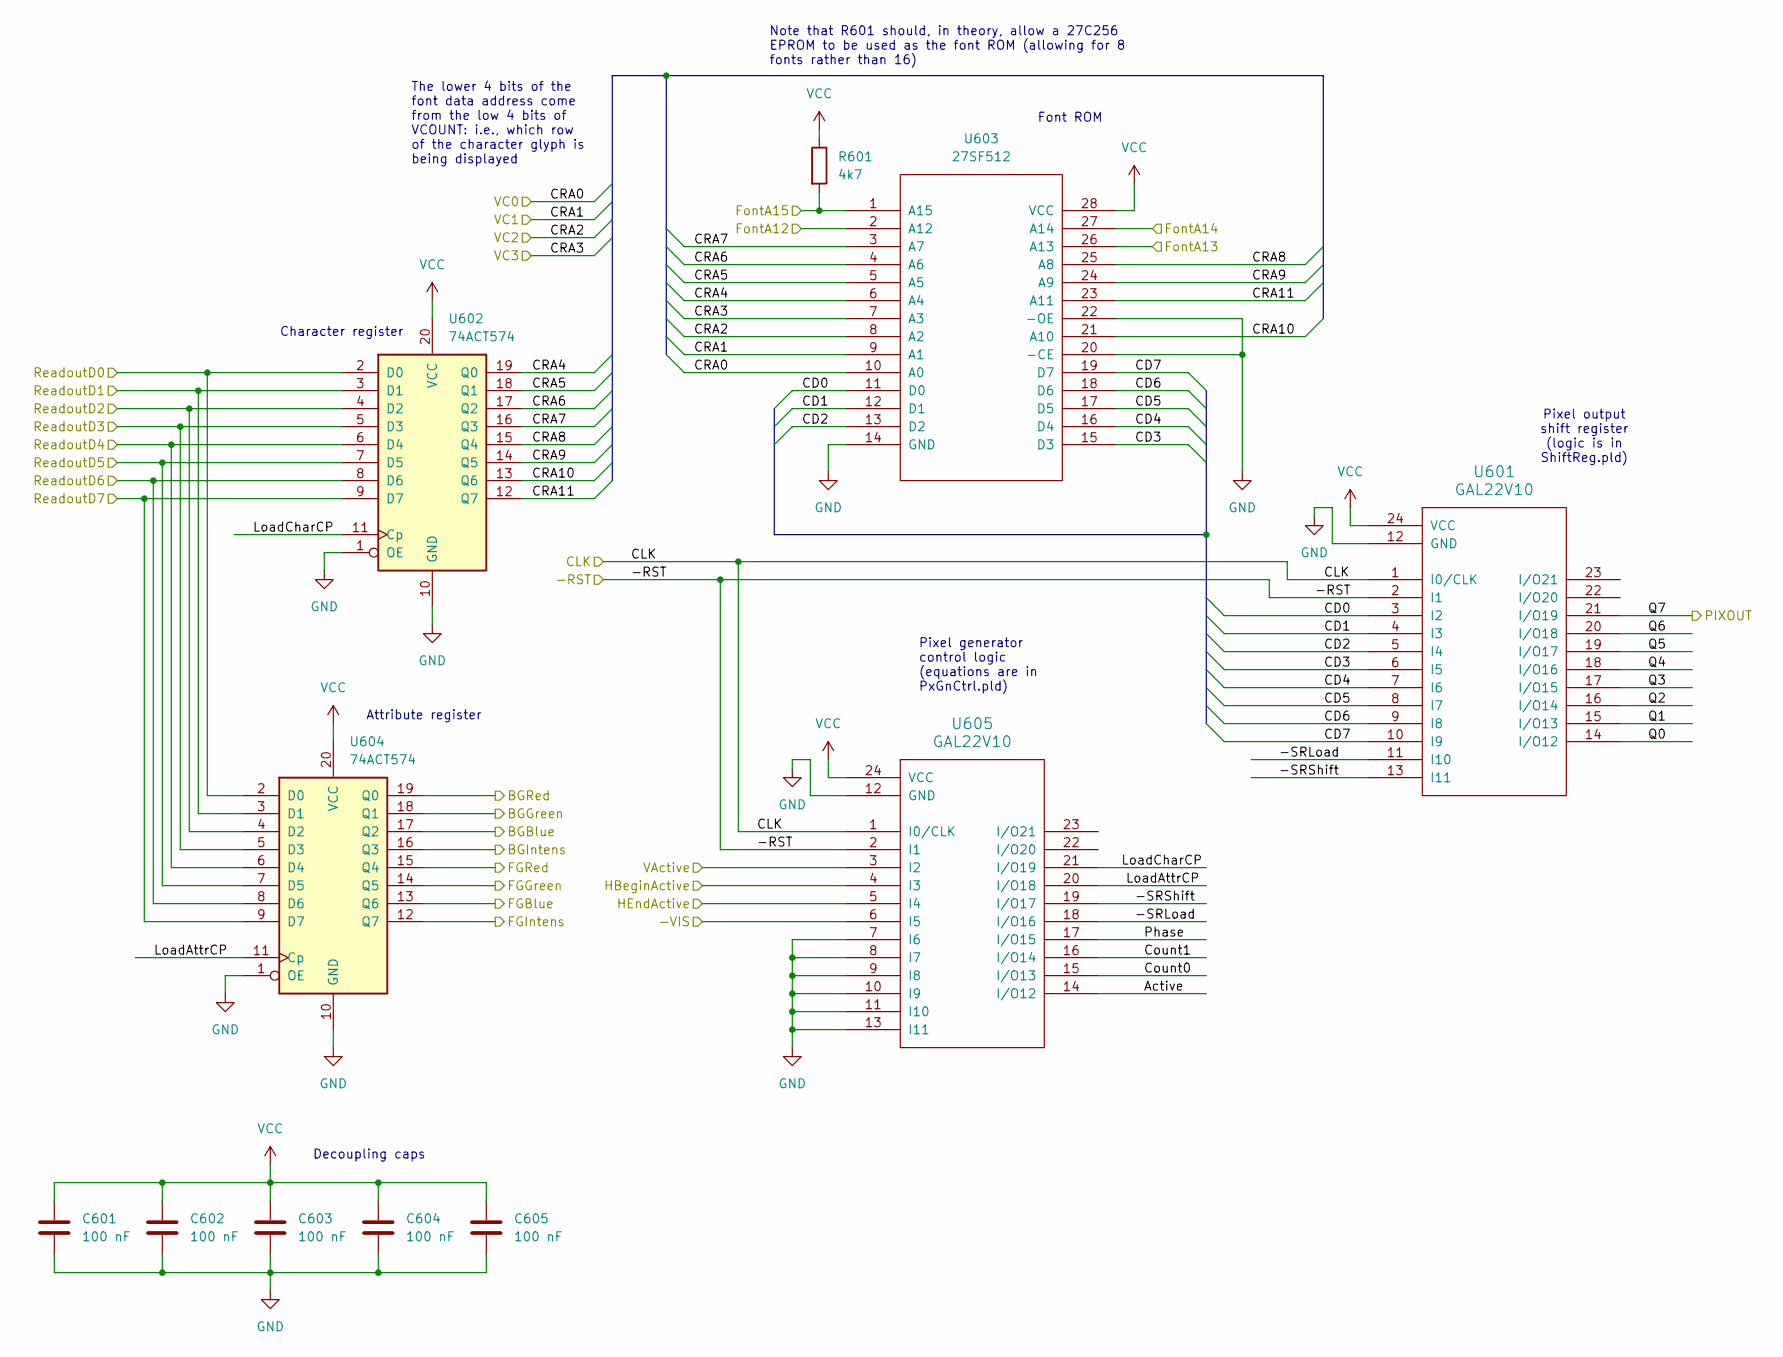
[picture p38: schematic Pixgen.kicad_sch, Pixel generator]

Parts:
C601, C602, C603, C604, C605: 100 nF; C_0805_2012Metric_Pad1.18x1.45mm_HandSolder
R601: 4k7; R_0805_2012Metric_Pad1.20x1.40mm_HandSolder
U601, U605: GAL22V10; SOIC-24W_7.5x15.4mm_P1.27mm
U602, U604: 74ACT574; SOIC-20W_7.5x12.8mm_P1.27mm
U603: 27SF512; DIP-28_W15.24mm_Socket

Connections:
/-RST: U601.1 (I0/CLK), U605.1 (I0/CLK); also elsewhere on the board
/-VIS: U605.6 (I5); also elsewhere on the board
/BGBlue: U604.17 (Q2); also elsewhere on the board
/BGGreen: U604.18 (Q1); also elsewhere on the board
/BGIntens: U604.16 (Q3); also elsewhere on the board
/BGRed: U604.19 (Q0); also elsewhere on the board
/CLK: U601.2 (I1), U605.2 (I1); also elsewhere on the board
/FGBlue: U604.13 (Q6); also elsewhere on the board
/FGGreen: U604.14 (Q5); also elsewhere on the board
/FGIntens: U604.12 (Q7); also elsewhere on the board
/FGRed: U604.15 (Q4); also elsewhere on the board
/FontA12: U603.2 (A12); also elsewhere on the board
/FontA13: U603.26 (A13); also elsewhere on the board
/FontA14: U603.27 (A14); also elsewhere on the board
/FontA15: R601.2, U603.1 (A15); also elsewhere on the board
/HBeginActive: U605.4 (I3); also elsewhere on the board
/HEndActive: U605.5 (I4); also elsewhere on the board
/Pixel: U601.21 (I/O19); also elsewhere on the board
/Pixgen/-SRLoad: U601.11 (I10), U605.18 (I/O16)
/Pixgen/-SRShift: U601.13 (I11), U605.19 (I/O17)
/Pixgen/Active: U605.14 (I/O12)
/Pixgen/CD0: U601.3 (I2), U603.11 (D0)
/Pixgen/CD1: U601.4 (I3), U603.12 (D1)
/Pixgen/CD2: U601.5 (I4), U603.13 (D2)
/Pixgen/CD3: U601.6 (I5), U603.15 (D3)
/Pixgen/CD4: U601.7 (I6), U603.16 (D4)
/Pixgen/CD5: U601.8 (I7), U603.17 (D5)
/Pixgen/CD6: U601.9 (I8), U603.18 (D6)
/Pixgen/CD7: U601.10 (I9), U603.19 (D7)
/Pixgen/CRA4: U602.19 (Q0), U603.6 (A4)
/Pixgen/CRA5: U602.18 (Q1), U603.5 (A5)
/Pixgen/CRA6: U602.17 (Q2), U603.4 (A6)
/Pixgen/CRA7: U602.16 (Q3), U603.3 (A7)
/Pixgen/CRA8: U602.15 (Q4), U603.25 (A8)
/Pixgen/CRA9: U602.14 (Q5), U603.24 (A9)
/Pixgen/CRA10: U602.13 (Q6), U603.21 (A10)
/Pixgen/CRA11: U602.12 (Q7), U603.23 (A11)
/Pixgen/Count0: U605.15 (I/O13)
/Pixgen/Count1: U605.16 (I/O14)
/Pixgen/LoadAttrCP: U604.11 (Cp), U605.20 (I/O18)
/Pixgen/LoadCharCP: U602.11 (Cp), U605.21 (I/O19)
/Pixgen/Phase: U605.17 (I/O15)
/Pixgen/Q0: U601.14 (I/O12)
/Pixgen/Q1: U601.15 (I/O13)
/Pixgen/Q2: U601.16 (I/O14)
/Pixgen/Q3: U601.17 (I/O15)
/Pixgen/Q4: U601.18 (I/O16)
/Pixgen/Q5: U601.19 (I/O17)
/Pixgen/Q6: U601.20 (I/O18)
/ReadoutD0: U602.2 (D0), U604.2 (D0); also elsewhere on the board
/ReadoutD1: U602.3 (D1), U604.3 (D1); also elsewhere on the board
/ReadoutD2: U602.4 (D2), U604.4 (D2); also elsewhere on the board
/ReadoutD3: U602.5 (D3), U604.5 (D3); also elsewhere on the board
/ReadoutD4: U602.6 (D4), U604.6 (D4); also elsewhere on the board
/ReadoutD5: U602.7 (D5), U604.7 (D5); also elsewhere on the board
/ReadoutD6: U602.8 (D6), U604.8 (D6); also elsewhere on the board
/ReadoutD7: U602.9 (D7), U604.9 (D7); also elsewhere on the board
/VActive: U605.3 (I2); also elsewhere on the board
/VC0: U603.10 (A0); also elsewhere on the board
/VC1: U603.9 (A1); also elsewhere on the board
/VC2: U603.8 (A2); also elsewhere on the board
/VC3: U603.7 (A3); also elsewhere on the board
GND: C601.2, C602.2, C603.2, C604.2, C605.2, U601.12 (GND), U602.1 (OE), U602.10 (GND), U603.14 (GND), U603.20 (-CE), U603.22 (-OE), U604.1 (OE), U604.10 (GND), U605.7 (I6), U605.8 (I7), U605.9 (I8), U605.10 (I9), U605.11 (I10), U605.12 (GND), U605.13 (I11); also elsewhere on the board
VCC: C601.1, C602.1, C603.1, C604.1, C605.1, R601.1, U601.24 (VCC), U602.20 (VCC), U603.28 (VCC), U604.20 (VCC), U605.24 (VCC); also elsewhere on the board

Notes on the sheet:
Font ROM
Character register
Pixel output shift register (logic is in ShiftReg.pld)
Pixel generator control logic (equations are in PxGnCtrl.pld)
Decoupling caps
Note that R601 should, in theory, allow a 27C256 EPROM to be used as the font ROM (allowing for 8 fonts rather than 16)
The lower 4 bits of the font data address come from the low 4 bits of VCOUNT: i.e., which row of the character glyph is being displayed
Attribute register

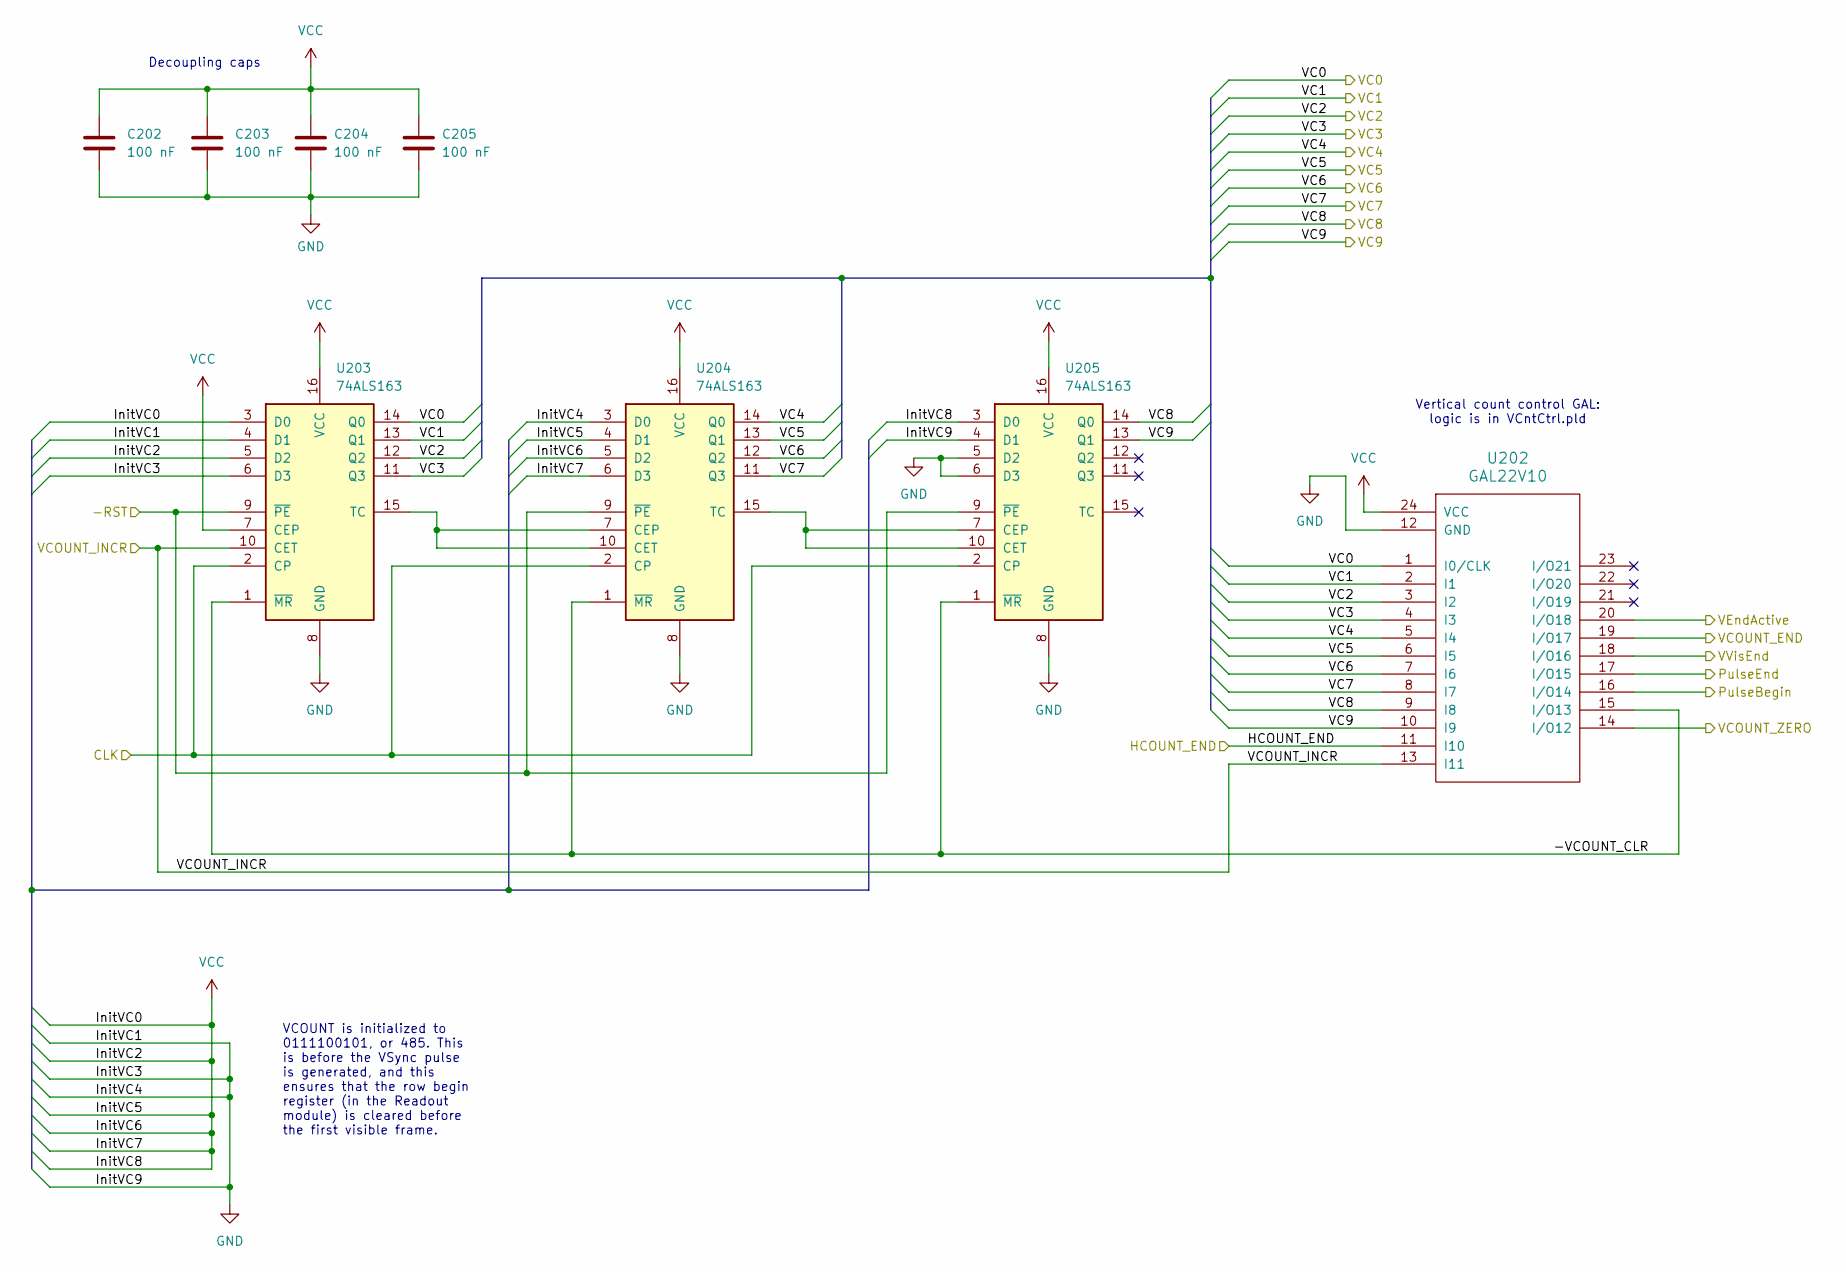
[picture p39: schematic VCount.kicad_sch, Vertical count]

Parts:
C202, C203, C204, C205: 100 nF; C_0805_2012Metric_Pad1.18x1.45mm_HandSolder
U202: GAL22V10; SOIC-24W_7.5x15.4mm_P1.27mm
U203, U204, U205: 74ALS163; SOIC-16W_5.3x10.2mm_P1.27mm

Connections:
/-RST: U203.9 (~PE), U204.9 (~PE), U205.9 (~PE); also elsewhere on the board
/CLK: U203.2 (CP), U204.2 (CP), U205.2 (CP); also elsewhere on the board
/HCOUNT_END: U202.11 (I10); also elsewhere on the board
/HEndPulse: U202.13 (I11), U203.10 (CET); also elsewhere on the board
/VBeginPulse: U202.16 (I/O14); also elsewhere on the board
/VC0: U202.1 (I0/CLK), U203.14 (Q0); also elsewhere on the board
/VC1: U202.2 (I1), U203.13 (Q1); also elsewhere on the board
/VC2: U202.3 (I2), U203.12 (Q2); also elsewhere on the board
/VC3: U202.4 (I3), U203.11 (Q3); also elsewhere on the board
/VCOUNT_END: U202.19 (I/O17); also elsewhere on the board
/VCOUNT_ZERO: U202.14 (I/O12); also elsewhere on the board
/VCount/-VCOUNT_CLR: U202.15 (I/O13), U203.1 (~MR), U204.1 (~MR), U205.1 (~MR)
/VCount/VC4: U202.5 (I4), U204.14 (Q0)
/VCount/VC5: U202.6 (I5), U204.13 (Q1)
/VCount/VC6: U202.7 (I6), U204.12 (Q2)
/VCount/VC7: U202.8 (I7), U204.11 (Q3)
/VCount/VC8: U202.9 (I8), U205.14 (Q0)
/VCount/VC9: U202.10 (I9), U205.13 (Q1)
/VEndActive: U202.20 (I/O18); also elsewhere on the board
/VEndPulse: U202.17 (I/O15); also elsewhere on the board
/VVisEnd: U202.18 (I/O16); also elsewhere on the board
GND: C202.2, C203.2, C204.2, C205.2, U202.12 (GND), U203.4 (D1), U203.6 (D3), U203.8 (GND), U204.3 (D0), U204.8 (GND), U205.4 (D1), U205.5 (D2), U205.6 (D3), U205.8 (GND); also elsewhere on the board
unnamed: U203.15 (TC), U204.7 (CEP), U204.10 (CET)
unnamed: U204.15 (TC), U205.7 (CEP), U205.10 (CET)
VCC: C202.1, C203.1, C204.1, C205.1, U202.24 (VCC), U203.3 (D0), U203.5 (D2), U203.7 (CEP), U203.16 (VCC), U204.4 (D1), U204.5 (D2), U204.6 (D3), U204.16 (VCC), U205.3 (D0), U205.16 (VCC); also elsewhere on the board

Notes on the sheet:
Decoupling caps
Vertical count control GAL: logic is in VCntCtrl.pld
VCOUNT is initialized to 0111100101, or 485. This is before the VSync pulse is generated, and this ensures that the row begin register (in the Readout module) is cleared before the first visible frame.

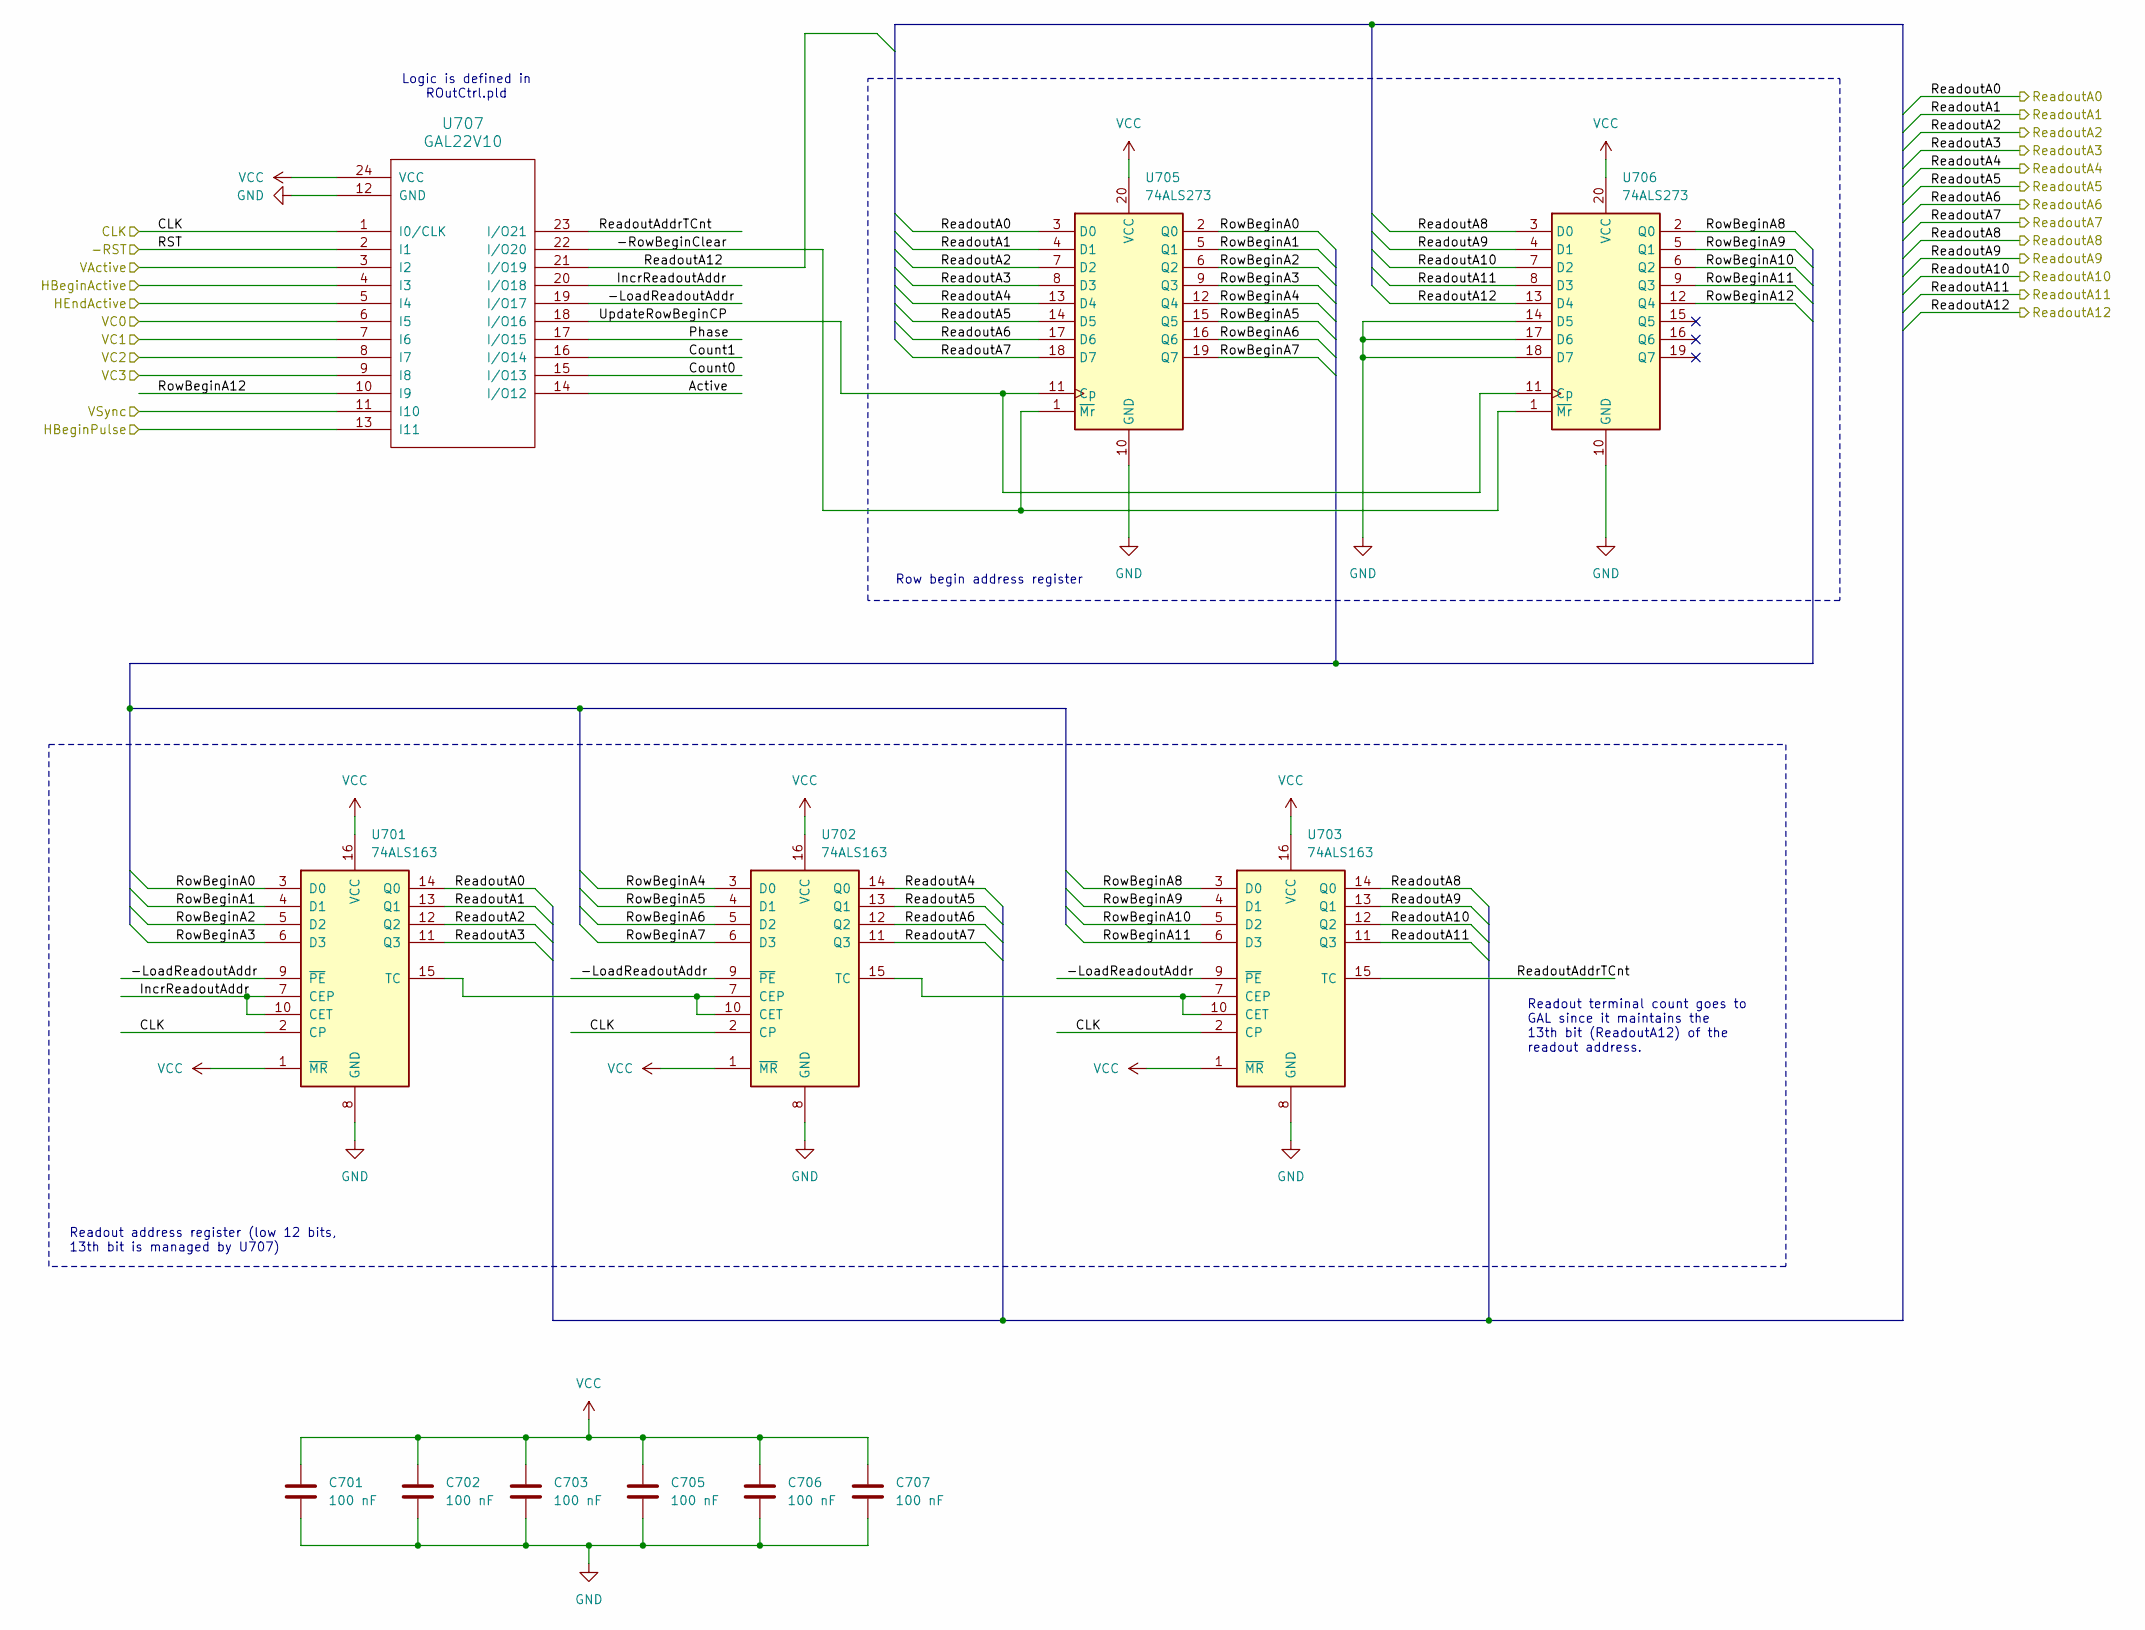
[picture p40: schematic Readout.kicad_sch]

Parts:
C701, C702, C703, C705, C706, C707: 100 nF; C_0805_2012Metric_Pad1.18x1.45mm_HandSolder
U701, U702, U703: 74ALS163; SOIC-16W_5.3x10.2mm_P1.27mm
U705, U706: 74ALS273; SOIC-20W_7.5x12.8mm_P1.27mm
U707: GAL22V10; SOIC-24W_7.5x15.4mm_P1.27mm

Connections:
/-RST: U701.2 (CP), U702.2 (CP), U703.2 (CP), U707.1 (I0/CLK); also elsewhere on the board
/CLK: U707.2 (I1); also elsewhere on the board
/HBeginActive: U707.4 (I3); also elsewhere on the board
/HBeginPulse: U707.13 (I11); also elsewhere on the board
/HEndActive: U707.5 (I4); also elsewhere on the board
/Readout/-LoadReadoutAddr: U701.9 (~PE), U702.9 (~PE), U703.9 (~PE), U707.19 (I/O17)
/Readout/-RowBeginClear: U705.1 (~Mr), U706.1 (~Mr), U707.22 (I/O20)
/Readout/Active: U707.14 (I/O12)
/Readout/Count0: U707.15 (I/O13)
/Readout/Count1: U707.16 (I/O14)
/Readout/IncrReadoutAddr: U701.7 (CEP), U701.10 (CET), U707.20 (I/O18)
/Readout/Phase: U707.17 (I/O15)
/Readout/ReadoutAddrTCnt: U703.15 (TC), U707.23 (I/O21)
/Readout/RowBeginA0: U701.3 (D0), U705.2 (Q0)
/Readout/RowBeginA1: U701.4 (D1), U705.5 (Q1)
/Readout/RowBeginA2: U701.5 (D2), U705.6 (Q2)
/Readout/RowBeginA3: U701.6 (D3), U705.9 (Q3)
/Readout/RowBeginA4: U702.3 (D0), U705.12 (Q4)
/Readout/RowBeginA5: U702.4 (D1), U705.15 (Q5)
/Readout/RowBeginA6: U702.5 (D2), U705.16 (Q6)
/Readout/RowBeginA7: U702.6 (D3), U705.19 (Q7)
/Readout/RowBeginA8: U703.3 (D0), U706.2 (Q0)
/Readout/RowBeginA9: U703.4 (D1), U706.5 (Q1)
/Readout/RowBeginA10: U703.5 (D2), U706.6 (Q2)
/Readout/RowBeginA11: U703.6 (D3), U706.9 (Q3)
/Readout/RowBeginA12: U706.12 (Q4), U707.10 (I9)
/Readout/UpdateRowBeginCP: U705.11 (Cp), U706.11 (Cp), U707.18 (I/O16)
/ReadoutA0: U701.14 (Q0), U705.3 (D0); also elsewhere on the board
/ReadoutA1: U701.13 (Q1), U705.4 (D1); also elsewhere on the board
/ReadoutA2: U701.12 (Q2), U705.7 (D2); also elsewhere on the board
/ReadoutA3: U701.11 (Q3), U705.8 (D3); also elsewhere on the board
/ReadoutA4: U702.14 (Q0), U705.13 (D4); also elsewhere on the board
/ReadoutA5: U702.13 (Q1), U705.14 (D5); also elsewhere on the board
/ReadoutA6: U702.12 (Q2), U705.17 (D6); also elsewhere on the board
/ReadoutA7: U702.11 (Q3), U705.18 (D7); also elsewhere on the board
/ReadoutA8: U703.14 (Q0), U706.3 (D0); also elsewhere on the board
/ReadoutA9: U703.13 (Q1), U706.4 (D1); also elsewhere on the board
/ReadoutA10: U703.12 (Q2), U706.7 (D2); also elsewhere on the board
/ReadoutA11: U703.11 (Q3), U706.8 (D3); also elsewhere on the board
/ReadoutA12: U706.13 (D4), U707.21 (I/O19); also elsewhere on the board
/VActive: U707.3 (I2); also elsewhere on the board
/VC0: U707.6 (I5); also elsewhere on the board
/VC1: U707.7 (I6); also elsewhere on the board
/VC2: U707.8 (I7); also elsewhere on the board
/VC3: U707.9 (I8); also elsewhere on the board
/VSync: U707.11 (I10); also elsewhere on the board
GND: C701.2, C702.2, C703.2, C705.2, C706.2, C707.2, U701.8 (GND), U702.8 (GND), U703.8 (GND), U705.10 (GND), U706.10 (GND), U706.14 (D5), U706.17 (D6), U706.18 (D7), U707.12 (GND); also elsewhere on the board
unnamed: U701.15 (TC), U702.7 (CEP), U702.10 (CET)
unnamed: U702.15 (TC), U703.7 (CEP), U703.10 (CET)
VCC: C701.1, C702.1, C703.1, C705.1, C706.1, C707.1, U701.1 (~MR), U701.16 (VCC), U702.1 (~MR), U702.16 (VCC), U703.1 (~MR), U703.16 (VCC), U705.20 (VCC), U706.20 (VCC), U707.24 (VCC); also elsewhere on the board

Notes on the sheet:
Readout terminal count goes to GAL since it maintains the 13th bit (ReadoutA12) of the readout address.
Readout address register (low 12 bits, 13th bit is managed by U707)
Logic is defined in ROutCtrl.pld
Row begin address register

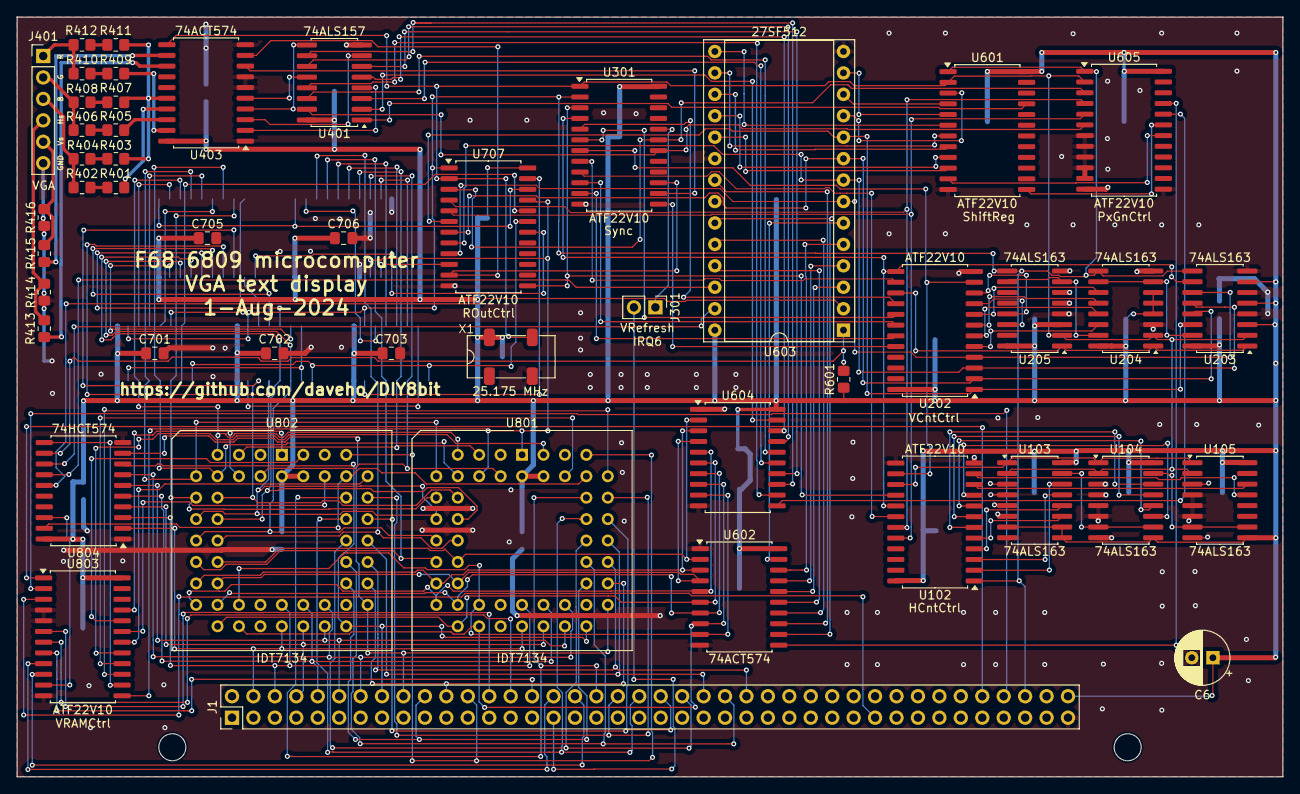
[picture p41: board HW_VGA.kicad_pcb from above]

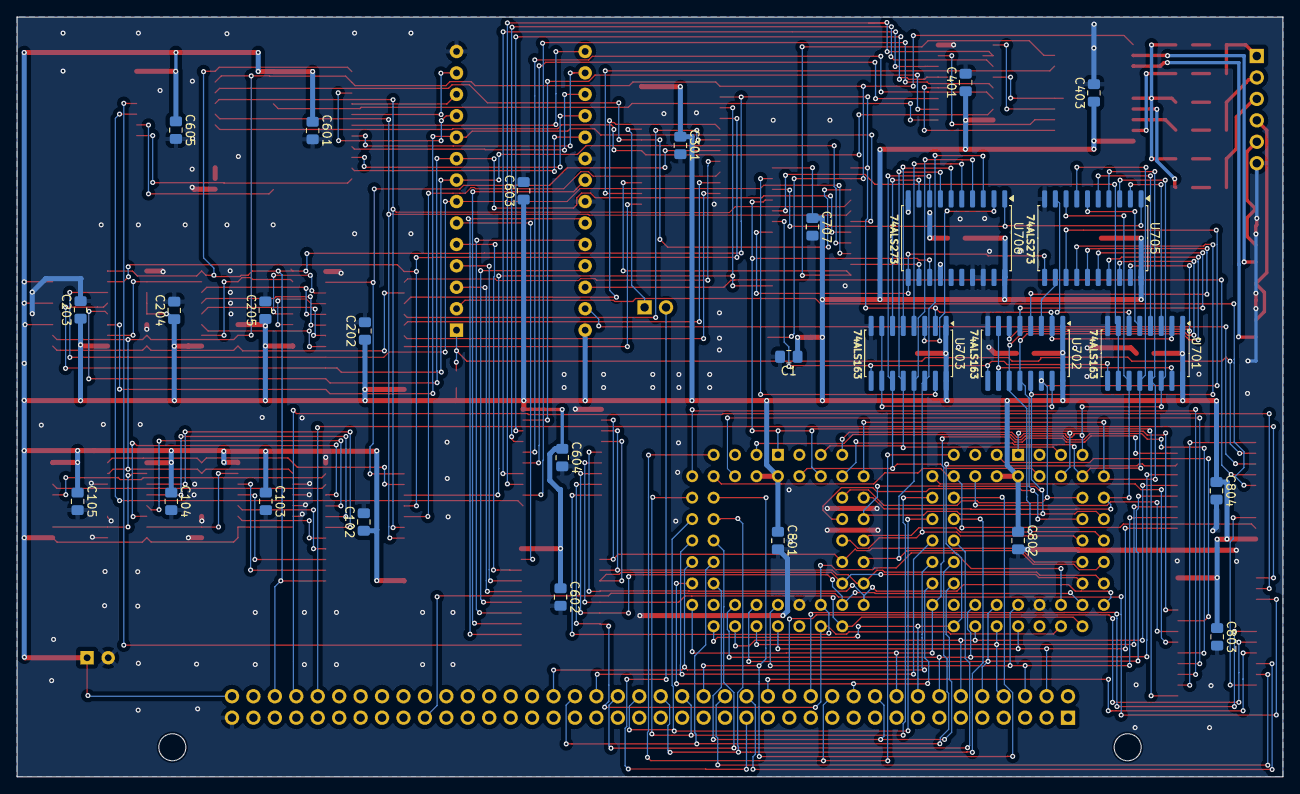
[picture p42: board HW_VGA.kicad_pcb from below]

Board: 2 copper layers, 150.0 x 90.0 mm, 75 parts (27 on the bottom side), 180 nets.

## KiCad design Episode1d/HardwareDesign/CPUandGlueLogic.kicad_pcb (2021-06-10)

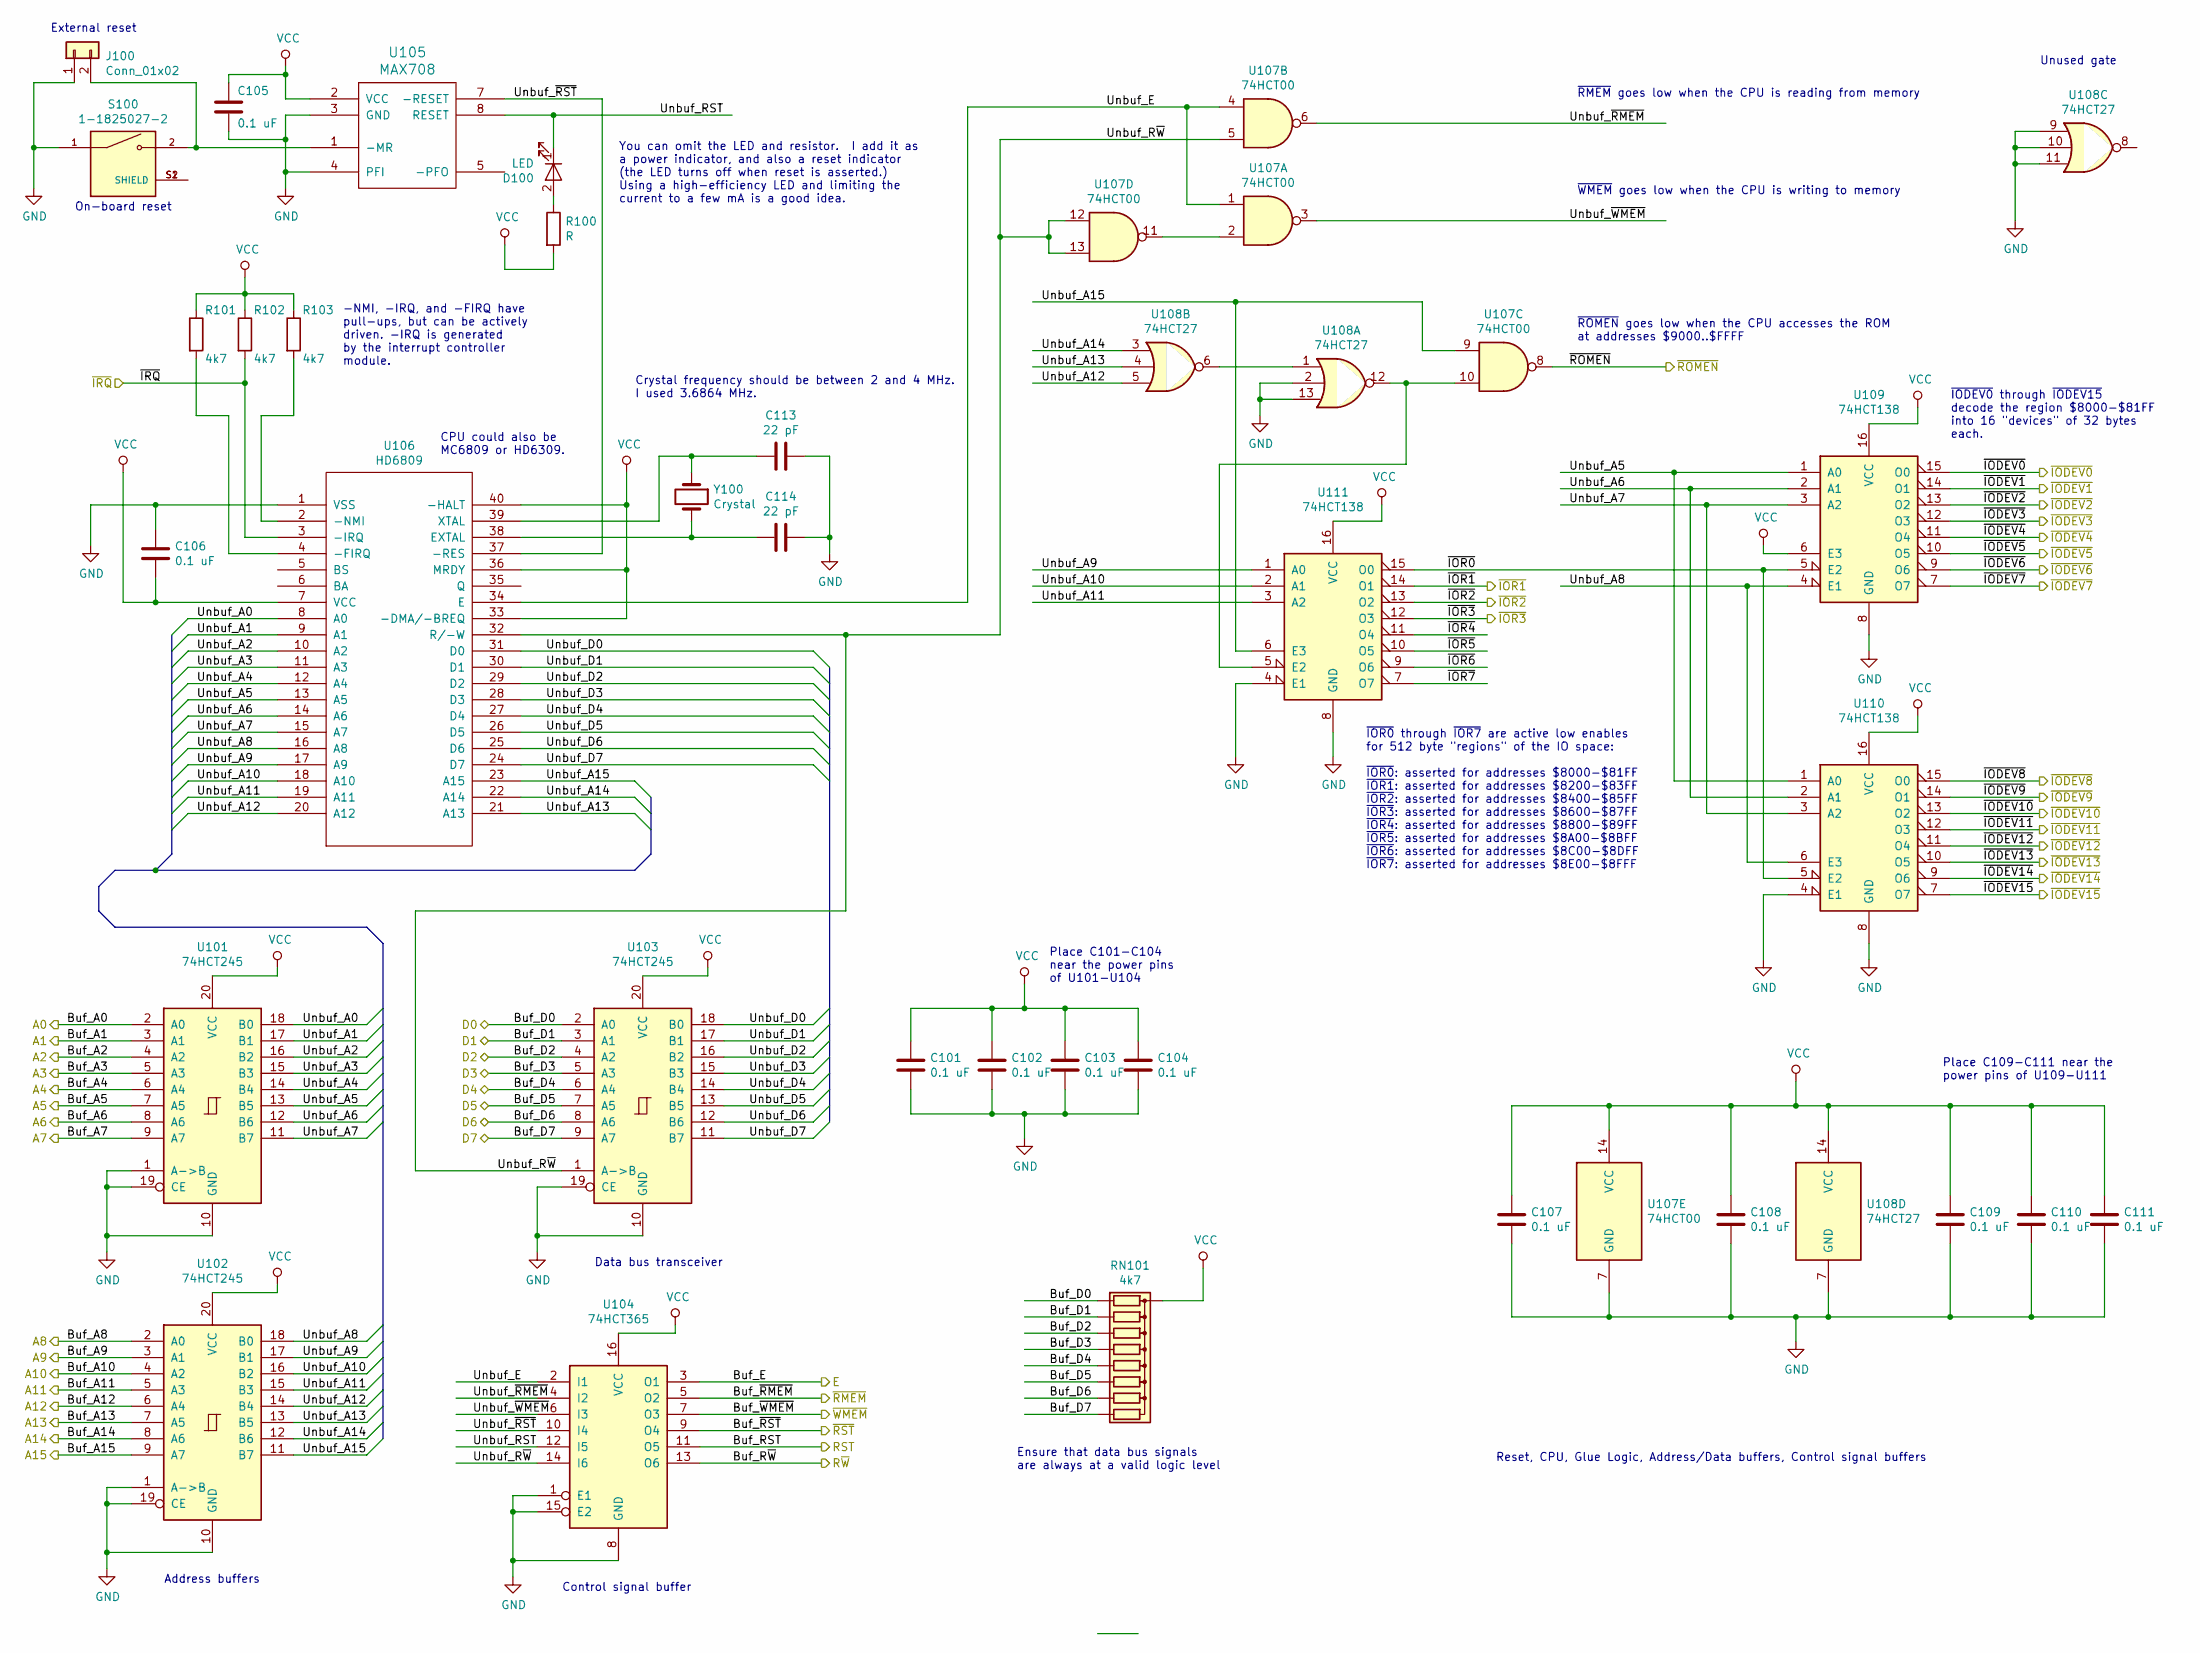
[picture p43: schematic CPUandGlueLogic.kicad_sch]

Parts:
C101, C102, C103, C104, C105, C106, C107, C108, C109, C110, C111: 0.1 uF; C_Disc_D5.0mm_W2.5mm_P2.50mm
C113, C114: 22 pF; C_Disc_D3.8mm_W2.6mm_P2.50mm
D100: LED; LED_D5.0mm
J100: Conn_01x02; PinHeader_1x02_P2.54mm_Vertical
R100: R; R_Axial_DIN0204_L3.6mm_D1.6mm_P7.62mm_Horizontal
R101, R102, R103: 4k7; R_Axial_DIN0204_L3.6mm_D1.6mm_P7.62mm_Horizontal
RN101: 4k7; R_Array_SIP9
S100: 1-1825027-2; SW_1-1825027-2
U101, U102, U103: 74HCT245; DIP-20_W7.62mm_Socket
U104: 74HCT365; DIP-16_W7.62mm_Socket
U105: MAX708; DIP-8_W7.62mm_Socket
U106: HD6809; DIP-40_W15.24mm_Socket
U107: 74HCT00; DIP-14_W7.62mm_Socket
U108: 74HCT27; DIP-14_W7.62mm_Socket
U109, U110, U111: 74HCT138; DIP-16_W7.62mm_Socket
Y100: Crystal; Crystal_HC18-U_Vertical

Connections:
/A0: U101.2 (A0); also elsewhere on the board
/A1: U101.3 (A1); also elsewhere on the board
/A2: U101.4 (A2); also elsewhere on the board
/A3: U101.5 (A3); also elsewhere on the board
/A4: U101.6 (A4); also elsewhere on the board
/A5: U101.7 (A5); also elsewhere on the board
/A6: U101.8 (A6); also elsewhere on the board
/A7: U101.9 (A7); also elsewhere on the board
/A8: U102.2 (A0); also elsewhere on the board
/A9: U102.3 (A1); also elsewhere on the board
/A10: U102.4 (A2); also elsewhere on the board
/A11: U102.5 (A3); also elsewhere on the board
/A12: U102.6 (A4); also elsewhere on the board
/A13: U102.7 (A5); also elsewhere on the board
/A14: U102.8 (A6); also elsewhere on the board
/A15: U102.9 (A7); also elsewhere on the board
/CPUandGlueLogic/Unbuf_A0: U101.18 (B0), U106.8 (A0)
/CPUandGlueLogic/Unbuf_A1: U101.17 (B1), U106.9 (A1)
/CPUandGlueLogic/Unbuf_A2: U101.16 (B2), U106.10 (A2)
/CPUandGlueLogic/Unbuf_A3: U101.15 (B3), U106.11 (A3)
/CPUandGlueLogic/Unbuf_A4: U101.14 (B4), U106.12 (A4)
/CPUandGlueLogic/Unbuf_A5: U101.13 (B5), U106.13 (A5), U109.1 (A0), U110.1 (A0)
/CPUandGlueLogic/Unbuf_A6: U101.12 (B6), U106.14 (A6), U109.2 (A1), U110.2 (A1)
/CPUandGlueLogic/Unbuf_A7: U101.11 (B7), U106.15 (A7), U109.3 (A2), U110.3 (A2)
/CPUandGlueLogic/Unbuf_A8: U102.18 (B0), U106.16 (A8), U109.4 (E1), U110.6 (E3)
/CPUandGlueLogic/Unbuf_A9: U102.17 (B1), U106.17 (A9), U111.1 (A0)
/CPUandGlueLogic/Unbuf_A10: U102.16 (B2), U106.18 (A10), U111.2 (A1)
/CPUandGlueLogic/Unbuf_A11: U102.15 (B3), U106.19 (A11), U111.3 (A2)
/CPUandGlueLogic/Unbuf_A12: U102.14 (B4), U106.20 (A12), U108.5
/CPUandGlueLogic/Unbuf_A13: U102.13 (B5), U106.21 (A13), U108.4
/CPUandGlueLogic/Unbuf_A14: U102.12 (B6), U106.22 (A14), U108.3
/CPUandGlueLogic/Unbuf_A15: U102.11 (B7), U106.23 (A15), U107.9, U111.6 (E3)
/CPUandGlueLogic/Unbuf_D0: U103.18 (B0), U106.31 (D0)
/CPUandGlueLogic/Unbuf_D1: U103.17 (B1), U106.30 (D1)
/CPUandGlueLogic/Unbuf_D2: U103.16 (B2), U106.29 (D2)
/CPUandGlueLogic/Unbuf_D3: U103.15 (B3), U106.28 (D3)
/CPUandGlueLogic/Unbuf_D4: U103.14 (B4), U106.27 (D4)
/CPUandGlueLogic/Unbuf_D5: U103.13 (B5), U106.26 (D5)
/CPUandGlueLogic/Unbuf_D6: U103.12 (B6), U106.25 (D6)
/CPUandGlueLogic/Unbuf_D7: U103.11 (B7), U106.24 (D7)
/CPUandGlueLogic/Unbuf_E: U104.2 (I1), U106.34 (E), U107.1, U107.4
/CPUandGlueLogic/Unbuf_RST: D100.1 (K), U104.12 (I5), U105.8 (RESET)
/CPUandGlueLogic/Unbuf_R~W~: U103.1 (A->B), U104.14 (I6), U106.32 (R/-W), U107.5, U107.12, U107.13
/CPUandGlueLogic/Unbuf_~RMEM~: U104.4 (I2), U107.6
/CPUandGlueLogic/Unbuf_~RST~: U104.10 (I4), U105.7 (-RESET), U106.37 (-RES)
/CPUandGlueLogic/Unbuf_~WMEM~: U104.6 (I3), U107.3
/CPUandGlueLogic/~IOR0~: U109.5 (E2), U110.5 (E2), U111.15 (O0)
/CPUandGlueLogic/~IOR4~: U111.11 (O4)
/CPUandGlueLogic/~IOR5~: U111.10 (O5)
/CPUandGlueLogic/~IOR6~: U111.9 (O6)
/CPUandGlueLogic/~IOR7~: U111.7 (O7)
/D0: RN101.2 (R1), U103.2 (A0); also elsewhere on the board
/D1: RN101.3 (R2), U103.3 (A1); also elsewhere on the board
/D2: RN101.4 (R3), U103.4 (A2); also elsewhere on the board
/D3: RN101.5 (R4), U103.5 (A3); also elsewhere on the board
/D4: RN101.6 (R5), U103.6 (A4); also elsewhere on the board
/D5: RN101.7 (R6), U103.7 (A5); also elsewhere on the board
/D6: RN101.8 (R7), U103.8 (A6); also elsewhere on the board
/D7: RN101.9 (R8), U103.9 (A7); also elsewhere on the board
/E: U104.3 (O1); also elsewhere on the board
/RST: U104.11 (O5); also elsewhere on the board
/R~W~: U104.13 (O6); also elsewhere on the board
/~IODEV0: U109.15 (O0); also elsewhere on the board
/~IODEV1: U109.14 (O1); also elsewhere on the board
/~IODEV2: U109.13 (O2); also elsewhere on the board
/~IODEV3: U109.12 (O3); also elsewhere on the board
/~IODEV4: U109.11 (O4); also elsewhere on the board
/~IODEV5: U109.10 (O5); also elsewhere on the board
/~IODEV6: U109.9 (O6); also elsewhere on the board
/~IODEV7: U109.7 (O7); also elsewhere on the board
/~IODEV8: U110.15 (O0); also elsewhere on the board
/~IODEV9: U110.14 (O1); also elsewhere on the board
/~IODEV10: U110.13 (O2); also elsewhere on the board
/~IODEV11: U110.12 (O3); also elsewhere on the board
/~IODEV12: U110.11 (O4); also elsewhere on the board
/~IODEV13: U110.10 (O5); also elsewhere on the board
/~IODEV14: U110.9 (O6); also elsewhere on the board
/~IODEV15: U110.7 (O7); also elsewhere on the board
/~IOR1~: U111.14 (O1); also elsewhere on the board
/~IOR2~: U111.13 (O2); also elsewhere on the board
/~IOR3~: U111.12 (O3); also elsewhere on the board
/~IRQ: R102.2, U106.3 (-IRQ); also elsewhere on the board
/~RMEM~: U104.5 (O2); also elsewhere on the board
/~ROMEN~: U107.8; also elsewhere on the board
/~RST~: U104.9 (O4); also elsewhere on the board
/~WMEM~: U104.7 (O3); also elsewhere on the board
GND: C101.2, C102.2, C103.2, C104.2, C105.2, C106.1, C107.2, C108.2, C109.2, C110.2, C111.2, C113.1, C114.1, J100.1, S100.1, U101.1 (A->B), U101.10 (GND), U101.19 (CE), U102.1 (A->B), U102.10 (GND), U102.19 (CE), U103.10 (GND), U103.19 (CE), U104.1 (E1), U104.8 (GND), U104.15 (E2), U105.3 (GND), U105.4 (PFI), U106.1 (VSS), U107.7 (GND), U108.2, U108.7 (GND), U108.9, U108.10, U108.11, U108.13, U109.8 (GND), U110.4 (E1), U110.8 (GND), U111.4 (E1), U111.8 (GND); also elsewhere on the board
unnamed: C113.2, U106.39 (XTAL), Y100.1
unnamed: C114.2, U106.38 (EXTAL), Y100.2
unnamed: D100.2 (A), R100.1
unnamed: J100.2, S100.2, U105.1 (-MR)
unnamed: R101.2, U106.4 (-FIRQ)
unnamed: R103.2, U106.2 (-NMI)
unnamed: S100.S1 (SHIELD), S100.S2 (SHIELD)
unnamed: U107.10, U108.12, U111.5 (E2)
unnamed: U107.2, U107.11
unnamed: U108.1, U108.6
VCC: C101.1, C102.1, C103.1, C104.1, C105.1, C106.2, C107.1, C108.1, C109.1, C110.1, C111.1, R100.2, R101.1, R102.1, R103.1, RN101.1 (common), U101.20 (VCC), U102.20 (VCC), U103.20 (VCC), U104.16 (VCC), U105.2 (VCC), U106.7 (VCC), U106.33 (-DMA/-BREQ), U106.36 (MRDY), U106.40 (-HALT), U107.14 (VCC), U108.14 (VCC), U109.6 (E3), U109.16 (VCC), U110.16 (VCC), U111.16 (VCC); also elsewhere on the board

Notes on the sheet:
~{WMEM} goes low when the CPU is writing to memory
Place C109-C111 near the power pins of U109-U111
External reset
-NMI, -IRQ, and -FIRQ have pull-ups, but can be actively driven. -IRQ is generated by the interrupt controller module.
Reset, CPU, Glue Logic, Address/Data buffers, Control signal buffers
You can omit the LED and resistor. I add it as a power indicator, and also a reset indicator (the LED turns off when reset is asserted.) Using a high-efficiency LED and limiting the current to a few mA is a good idea.
On-board reset
Crystal frequency should be between 2 and 4 MHz. I used 3.6864 MHz.
Control signal buffer
~{IOR0} through ~{IOR7} are active low enables for 512 byte "regions" of the IO space: ~{IOR0}: asserted for addresses $8000-$81FF ~{IOR1}: asserted for addresses $8200-$83FF ~{IOR2}: asserted for addresses $8400-$85FF ~{IOR3}: asserted for addresses $8600-$87FF ~{IOR4}: asserted for addresses $880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
Address buffers
CPU could also be MC6809 or HD6309.
~{IODEV0} through ~{IODEV15} decode the region $8000-$81FF into 16 "devices" of 32 bytes each.
~{ROMEN} goes low when the CPU accesses the ROM at addresses $9000..$FFFF
Unused gate
~{RMEM} goes low when the CPU is reading from memory
Ensure that data bus signals are always at a valid logic level
Place C101-C104 near the power pins of U101-U104
Data bus transceiver

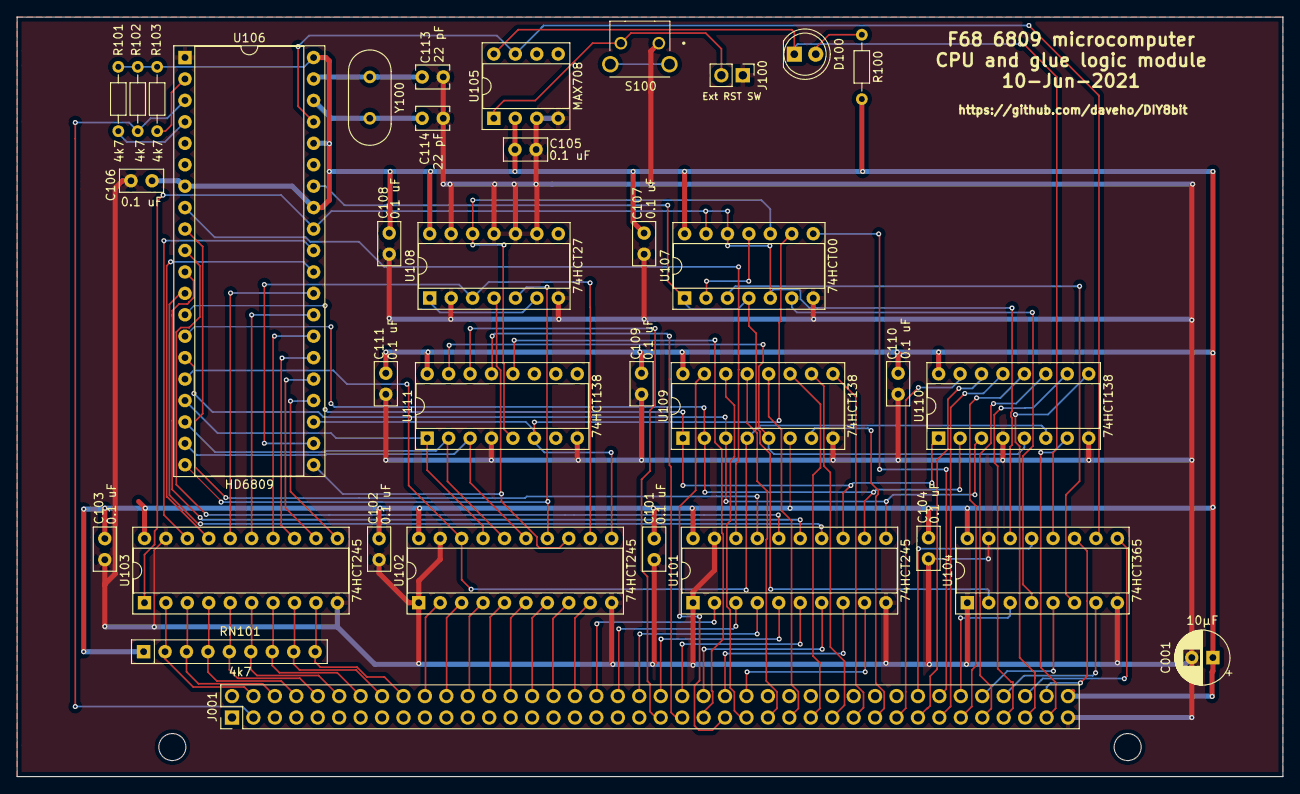
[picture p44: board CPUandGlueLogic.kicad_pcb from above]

Board: 2 copper layers, 150.0 x 90.0 mm, 35 parts (0 on the bottom side), 94 nets.

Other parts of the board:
C001: 10μF; CP_Radial_D6.3mm_P2.50mm
J001: Conn_02x40_Odd_Even; PinHeader_2x40_P2.54mm_Vertical

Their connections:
/A0: J001.36; also elsewhere on the board
/A1: J001.38; also elsewhere on the board
/A2: J001.40; also elsewhere on the board
/A3: J001.42; also elsewhere on the board
/A4: J001.44; also elsewhere on the board
/A5: J001.46; also elsewhere on the board
/A6: J001.48; also elsewhere on the board
/A7: J001.50; also elsewhere on the board
/A8: J001.20; also elsewhere on the board
/A9: J001.22; also elsewhere on the board
/A10: J001.24; also elsewhere on the board
/A11: J001.26; also elsewhere on the board
/A12: J001.28; also elsewhere on the board
/A13: J001.30; also elsewhere on the board
/A14: J001.32; also elsewhere on the board
/A15: J001.34; also elsewhere on the board
/D0: J001.4; also elsewhere on the board
/D1: J001.6; also elsewhere on the board
/D2: J001.8; also elsewhere on the board
/D3: J001.10; also elsewhere on the board
/D4: J001.12; also elsewhere on the board
/D5: J001.14; also elsewhere on the board
/D6: J001.16; also elsewhere on the board
/D7: J001.18; also elsewhere on the board
/E: J001.70; also elsewhere on the board
/RST: J001.78; also elsewhere on the board
/R~W~: J001.66; also elsewhere on the board
/~IODEV0: J001.47; also elsewhere on the board
/~IODEV1: J001.49; also elsewhere on the board
/~IODEV2: J001.51; also elsewhere on the board
/~IODEV3: J001.53; also elsewhere on the board
/~IODEV4: J001.55; also elsewhere on the board
/~IODEV5: J001.57; also elsewhere on the board
/~IODEV6: J001.59; also elsewhere on the board
/~IODEV7: J001.61; also elsewhere on the board
/~IODEV8: J001.63; also elsewhere on the board
/~IODEV9: J001.65; also elsewhere on the board
/~IODEV10: J001.67; also elsewhere on the board
/~IODEV11: J001.69; also elsewhere on the board
/~IODEV12: J001.71; also elsewhere on the board
/~IODEV13: J001.73; also elsewhere on the board
/~IODEV14: J001.75; also elsewhere on the board
/~IODEV15: J001.77; also elsewhere on the board
/~IOR1~: J001.41; also elsewhere on the board
/~IOR2~: J001.43; also elsewhere on the board
/~IOR3~: J001.45; also elsewhere on the board
/~IRQ: J001.3; also elsewhere on the board
/~RMEM~: J001.72; also elsewhere on the board
/~ROMEN~: J001.68; also elsewhere on the board
/~RST~: J001.76; also elsewhere on the board
/~WMEM~: J001.74; also elsewhere on the board
GND: C001.2, J001.79; also elsewhere on the board
VCC: C001.1, J001.80; also elsewhere on the board

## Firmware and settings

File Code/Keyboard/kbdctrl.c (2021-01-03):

// Keyboard controller for C16 keyboard
// An 8051-family microcontroller (89C51 or 87C51) scans the
// key matrix and sends scan codes to the host system via
// an IDT7201 FIFO memory.

// Sources:

// C16 keyboard:
//   http://www.zimmers.net/anonftp/pub/cbm/schematics/computers/plus4/C16_Service_Manual_314001-03_(1984_Oct).pdf
// Page 8 shows the keyboard matrix.

// Programming the 8051 UART:
//   https://exploreembedded.com/wiki/A4.8051_Communication_Protocols:UART,_RS232
//   https://www.electronicwings.com/8051/8051-uart

// IDT7201:
//   https://www.idt.com/us/en/document/dst/720072017202-datasheet

#include <mcs51/at89x51.h>
#include <stdint.h>

#define DEBUG

#ifdef DEBUG
void UART_Init(void) { 
    SCON = 0x50;  // Asynchronous mode, 8-bit data and 1-stop bit
    TMOD = 0x20;  // Timer1 in Mode2.
    TH1 = 0xFD;   // Correct value for 11.0592 MHz crystal
    TR1 = 1;      // Turn ON the timer for Baud rate generation
}

void UART_TxChar(uint8_t ch) {
    SBUF = ch;      // Load the data to be transmitted
    while(TI==0);   // Wait till the data is trasmitted
    TI = 0;         // Clear the Tx flag for next cycle.
}

// Command character
#define SER_CMD 254

void writeString(__code const char *s) {
    while (*s) {
        UART_TxChar(*s++);
    }
}
#endif

void delay(uint16_t count) {
    volatile uint16_t i;
    for (i = 0; i < count; i++) {
        // do nothing, hope this doesn't get optimized out
    }
}

#ifdef DEBUG
__code const char *hexdigits = "0123456789abcdef";
__code const char *scanmsg = "scan: ";

void writeHex(uint8_t val) {
   // The row and column numbers are 0-7, so we really
   // only need one digit
   //UART_TxChar(hexdigits[val >> 4]);
   UART_TxChar(hexdigits[val & 0xF]);
}
#endif

uint8_t press[8];

void send_scancode(uint8_t col, uint8_t row, uint8_t press) {
    // Format scancode
    uint8_t scancode = (col << 3) | row;
    if (press) {
        scancode |= (1 << 6);
    }

    // Write scancode to port 2 (which outputs to the FIFO data inputs)
    P2 = scancode;

    // Send a low pulse on P3.6 to write the scancode to the FIFO
    P3_6 = 0;
    P3_6 = 1;

#ifdef DEBUG
    UART_TxChar((uint8_t) SER_CMD);
    UART_TxChar((uint8_t) (128+0));
    writeString(scanmsg);
    writeHex(col);
    UART_TxChar(',');
    writeHex(row);
    UART_TxChar(',');
    writeHex(press);
#endif
}

void check_rows(int col) {
    uint8_t prev, curr, row, bit;

    // get previous row input values for this column
    prev = press[col];

    // read current values on the row inputs (P0)
    curr = P0;

    // Check each row
    for (row = 0, bit = 1; row < 8; row++, bit <<= 1) {
        // see if the row value changed since the last scan
        uint8_t then = prev & bit;
        uint8_t now = curr & bit;
        if (now != then) {
            uint8_t is_press = (now == 0);
            send_scancode(col, row, is_press);
        }
    }

    // record updated row values for this column
    press[col] = curr;
}

void kbd_scan(void) {
    uint8_t i, colout;

    // Set initial column scan value
    colout = 0xFE;

    // for each column...
    for (i = 0; i < 8; i++) {
        // output column scan value
        P1 = colout;
        delay(10); // make sure row inputs have time to change

        // check row inputs for this column
        check_rows(i);

        // change P1 outputs to scan the next column
        colout = (colout << 1) | 1;
    }

    // set column outputs back to high
    P1 = 0xFF;
}

int main() {
    uint8_t i;

    delay(10000);
#ifdef DEBUG
    UART_Init();
#endif

    // Writing all 1s to port 0 allows us to use it for input
    P0 = 0xFF;

    // Set initial column outputs
    P1 = 0xFF;

    // Make sure P3.6 (which controls the FIFO -WR input) is high
    P3_6 = 1;

    // Reset the FIFO (P3.7 is connected to the FIFO's -RS input)
    P3_7 = 0;
    delay(10);
    P3_7 = 1;

    // Assume that all keys are released initially
    for (i = 0; i < 8; i++) {
        press[i] = 0xFF;
    }

    for (;;) {
        kbd_scan();
        delay(500);
    }
}

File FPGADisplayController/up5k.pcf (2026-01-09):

set_io --warn-no-port nrst 10
set_io --warn-no-port ext_osc 20
set_io --warn-no-port redOut 4
set_io --warn-no-port greenOut 3
set_io --warn-no-port blueOut 48
set_io --warn-no-port intenseOut 45
set_io --warn-no-port hSyncOut 46
set_io --warn-no-port vSyncOut 47
set_io --warn-no-port hostDataPhys[0] 12
set_io --warn-no-port hostDataPhys[1] 21
set_io --warn-no-port hostDataPhys[2] 13
set_io --warn-no-port hostDataPhys[3] 19
set_io --warn-no-port hostDataPhys[4] 18
set_io --warn-no-port hostDataPhys[5] 11
set_io --warn-no-port hostDataPhys[6] 9
set_io --warn-no-port hostDataPhys[7] 6
set_io --warn-no-port hostAddr[0] 23
set_io --warn-no-port hostAddr[1] 25
set_io --warn-no-port hostAddr[2] 26
set_io --warn-no-port hostAddr[3] 27
set_io --warn-no-port hostAddr[4] 32
set_io --warn-no-port hostAddr[5] 35
set_io --warn-no-port hostAddr[6] 31
set_io --warn-no-port hostAddr[7] 37
set_io --warn-no-port hostAddr[8] 34
set_io --warn-no-port hostAddr[9] 43
set_io --warn-no-port hostAddr[10] 36
set_io --warn-no-port hostAddr[11] 42
set_io --warn-no-port hostAddr[12] 38
set_io --warn-no-port nHostRd 28
set_io --warn-no-port nHostWr 2

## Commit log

2019-02-09 D type edge triggered flip flop schematic
    [DTypeEdgeTriggered.kicad_pcb, DTypeEdgeTriggered.sch]
2019-02-09 pdf schematic for edge triggered flip flop
2019-02-09 fix switch debouncing
    For this circuit, the Schmitt trigger inverters are
    supposed to go high when the button is pressed, not low.
    [DTypeEdgeTriggered.sch]
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2019-02-12 label -S and -R inputs correctly
    [SRLatch.sch]
2019-02-13 D-type latch with async set/reset
    [DTypeLatchAsyncSetReset.kicad_pcb, DTypeLatchAsyncSetReset.sch]
2019-02-13 correct minor issues
    [DTypeLatchAsyncSetReset.sch]
2019-02-13 added missing component designations
    [DTypeLatch.sch]
2019-02-13 various corrections: tested working on breadboard
    [DTypeLatchAsyncSetReset.sch]
2019-02-16 RC power on reset circuit
    [RC_POR.kicad_pcb, RC_POR.sch]
2019-02-16 MAX708 power on reset circuit
    [MAX708_POR.kicad_pcb, MAX708_POR.sch]
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2019-02-17 fix library path, use polarized cap
    [RC_POR.sch]
2019-02-23 TL7705A power-on reset circuit
    [TL7705A_POR.kicad_pcb, TL7705A_POR.sch]
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2019-02-25 manual power-on reset circuit using pushbutton
    [Manual_POR.kicad_pcb, Manual_POR.sch]
2019-02-25 add link to manual reset circuit
2019-02-25 generate PDF of MAX708 power-on reset circuit
2019-03-04 first attempt at 6809 freerun demo circuit
    Created on a plane enroute to Minneapolis from BWI,
    so not tested on the breadboard yet :-)
    [Freerun.kicad_pcb, Freerun.sch]
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2019-03-05 minor fixes
    [Freerun.sch]
2019-03-05 connect MRDY input to VCC
    With this fix the circuit appears to work (expected
    frequencies are observed on A0..A15)
    [Freerun.sch]
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2019-04-04 added output port and 7 segment display
    The output port (74HCT574) requires an OR gate to generate
    its clock pulse, which unfortunately required another
    IC (74HCT32). This hardware probably won't be used in
    the final circuit, however.
    [CircuitWithROM.sch]
2019-04-07 change ROM to 28C256, fix control of port
    [CircuitWithROM.sch]
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2019-05-19 refactored into multiple sheets, added RAM
    Also added buffers for address bus, data bus, and
    bus control signals.
    [CPUandGlueLogic.sch, CircuitWithRAM.kicad_pcb, CircuitWithRAM.sch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]
2019-08-11 renamed Episode0a as Episode0b
    Episode 0A is going to be the EEPROM programmer.
    [CPUandGlueLogic.sch, CircuitWithRAM.kicad_pcb, CircuitWithRAM.sch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]
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2019-11-04 fixed mis-drawing of D bus on memory schematic
    [CPUandGlueLogic.sch, CircuitWithRAM.sch, Memory.sch]
2019-11-23 slightly revised schematic to match core module
    In wiring the code module (CPU + glue logic) on its
    protoboard I accidentally swapped RST and ~RST on the
    '365 hex buffer, so I updated the schematic
    to match.
    [CPUandGlueLogic.sch, CircuitWithRAM2.kicad_pcb, CircuitWithRAM2.sch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]
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2019-11-30 show ACIA connections to FT232RL breakout
    Use current-limiting resistors between ACIA and FT232RL,
    since they are powered by different sources, and we don't
    want current flow between them. (Got this idea from
    Grant Searle's minimal 6809 project.) Not sure if the
    FT232RL should have its VCC connected to the 6809 system's
    VCC: need to check old prototype.
    [CPUandGlueLogic.sch, CircuitWithPeriphs.sch, CorePeriphs.sch]
2019-11-30 still trying to get ACIA working
    Forgot to route A0 to the RS input on the ACIA,
    fixed, hopefully it will work now.
    [CorePeriphs.sch]
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2020-01-04 better version of CircuitWithPeriphs schematic
    The section with the 6850 ACIA was a complete mess:
    spread out the connections a bit, and added some
    net labels to help indicate which ACIA signals are
    connected to which pins of the FT232RL breakout.
    [CPUandGlueLogic.sch, CircuitWithPeriphs.kicad_pcb, CircuitWithPeriphs.sch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]
2020-01-04 correct connections to FT232RL breakout
    [CorePeriphs.sch]
2020-01-04 make a note about 6850/FT232RL conns being wrong
    [CorePeriphs.sch]
2020-01-06 new version of circuit supporting interrupts
    Interrupt handling hardware is present, but not connected
    to the rest of the circuit yet.
    [CPUandGlueLogic.sch, CircuitWithInterrupts.kicad_pcb, CircuitWithInterrupts.sch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]
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2020-01-09 integrated interrupt controller
    Added ~IRQ input to core module, and changed the
    wiring of the CPU's ~IRQ input to feed in the ~IRQ
    output of the interrupt controller. (A pull-up
    resistor will keep this input high when the interrupt
    controller isn't installed.)
    Have the peripheral module send the Timer 1 output
    to the interrupt controller's ~IRQ3 input. This will
    be the system periodic timer interrupt.
    Also have the peripheral module export the pins of
    Port C, and use PC0 and PC1 to clear the flip flops
    that latch a pulse on ~IRQ3 and ~IRQ6, which are
    edge-triggered.
    [CPUandGlueLogic.sch, CircuitWithInterrupts.sch, CorePeriphs.sch]
2020-01-09 add pull-ups to -IRQ, -FIRQ, and -NMI
    This allows them to be driven low if used, but still
    works if they are not explicitly driven.
    [CPUandGlueLogic.sch]
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2020-05-19 more work on support for interrupts
    Better handling of resetting the flip flops used for
    detecting edge triggered interrupts, including making
    sure only the specific FF for the interrupt that
    actually occurred is reset.
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2020-05-21 work more on keyboard controller
    Tidied up the keyboard controller schematic, made additional
    connections.
    [CPUandGlueLogic.sch, CircuitWithKbdCtrl.kicad_pcb, CircuitWithKbdCtrl.sch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]
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2020-05-27 fixed keyboard rows and columns being reversed
    [Keyboard.sch]
2020-05-27 pull-down resistors need to be weaker
    The port 1 output pins on an 89C51 can't overcome
    a 4.7k resistor tied to ground. 15k and up seem to
    work. Plan to use 22k resistors, hopefully that
    will be good for an actual 87C51. I think weak pull
    downs should be fine because we don't require fast
    transitions.
    [Keyboard.sch]
2020-05-28 use pull ups rather than pull downs on row inputs
    Port 1 seems to have trouble driving a high output
    when there is a pull down resistor. It's possible
    that driving to ground against a pull up resistor
    will work better (would make sense, because the 8051
    family normally drives LEDs by connecting the
    cathode of the LED to the output and driving the
    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
    [Keyboard.sch]
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2020-05-28 go back to using pull-down resistors on row inputs
    P1's output can't seem to drive an output to ground
    strongly enough to overcome even extremely weak pull
    up resistors.
    [Keyboard.sch]
2020-05-28 use pull-down resistors on row inputs
    The reason it wasn't working before was actually
    a firmware bug: multiple columns were being driven
    to GND simultaneously. With that bug fixed,
    it now seems to be working perfectly.
    [Keyboard.sch]
2020-05-31 code cleanup
    It's no longer necessary to support pull-down resistors
    on the row input.
    [kbdctrl.c]
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2021-05-16 correct connections for RS-232?
    [CorePeriphs.sch]
2021-05-17 more cleanups in preparation for PCB layout
    Renamed nets to distinguish unbuffered vs. buffered signals.
    Fixed one error in interrupt controller (D0 was tied
    to ground.)
    Not entirely done yet.
    [CPUandGlueLogic.sch, CorePeriphs.sch, Interrupts.sch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]
2021-05-17 fixed labeling of some unbuffered address bus signals
    [CPUandGlueLogic.sch]
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2021-05-17 more preparations for PCB layout
    More nets connected to appropriate backplane connector pin.
    [CPUandGlueLogic.sch, F68.sch, Keyboard.sch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]
2021-05-18 more preparations for PCB layout
    Make sure all nets connected to backplane connector pins are
    labeled correctly.
    Add bulk decoupling caps for each backplane connector.
    Make keyboard interrupt be -IRQ5 rather than -IRQ7.
    [CPUandGlueLogic.sch, F68.sch, Interrupts.sch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]
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2021-05-18 a few more consistency tweaks before PCB layout
    Routed second timer/counter output to backplane connector,
    just in case we want to use it for something eventually
    [CorePeriphs.sch, F68.sch, Interrupts.sch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]
2021-05-18 have one copy of backplane connector on main sheet
    Avoids need to replicate it elsewhere, and helps ensure
    that all signals are connected correctly.
    [CPUandGlueLogic.sch, F68.sch, Keyboard.sch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]
2021-05-19 fix R/-W signal on main sheet
    [F68.sch]
2021-05-19 changes to backplane signals
    Route all IRQ signals on backplane.
    Only route -IOR1..-IOR3 on backplane.
    Move TCOUNT2 to after IRQ signals.
    [CPUandGlueLogic.sch, F68.sch, Interrupts.sch]
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2021-05-19 fix footprint for resistor network
    [Keyboard.sch]
2021-05-19 add pull-up resistors to data bus signals
    This will ensure that they are always at a valid
    logic level.
    [CPUandGlueLogic.sch]
2021-05-19 fix pin assignments for backplane connector
    [CPUandGlueLogic.sch, F68.sch]
2021-05-19 fix footprint for data bus pull-up RN
    [CPUandGlueLogic.sch]
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2021-05-20 routed all signals, added holes for connector brackets
    Still need to add ground planes.
    [CPUandGlueLogic.kicad_pcb]
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2021-05-22 starting work on enclosure design
    For now, preparing to make a frame using Makerbeam XL
    extrusions.
    [lbracket.stl]
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2021-05-25 making clip spacing a bit tighter
    [CardGuide.scad]
2021-05-25 have card guide attach to top of mounting rail
    This will make installation and removal of the card
    guides much easier.
    [CardGuide.scad, CardGuide.stl]
2021-05-25 put in correct orientation for printing
    [CardGuide.scad, CardGuide.stl]
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2021-05-30 first FPGA experiment
    Generate 6 MHz square wave by dividing the internal
    48 MHz high frequency oscillator signal by 8.
    [up5k.pcf]
2021-05-30 second FPGA experiment
    Use PLL to generate an internal 240 MHz clock from
    the 48 MHz high-frequency oscillator.
    [up5k.pcf]
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2021-06-01 net pocket should be on top part
    Also, fixed the amount of elevation (which shouldn't include
    the PCB thickness.)
    [VGABracket.scad, VGABracket.stl]
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2021-06-02 initial display circuit
    The display isn't interfaced with the system yet.
    Initial goal is to generate a valid 800x600 SVGA signal.
    Added a footprint for the Upduino 3.0, which is DIP-48,
    but 0.7" wide rather than the standard 0.6".
    [Display.sch]
2021-06-03 fix syntax issues, constrain outputs to pins
    Also, make a note that hcount and vcount refer to column
    and line to be generated on the *next* PLL clock.
    [up5k.pcf]
2021-06-03 corrected Upduino 3.0 pin assignments
    The 12MHz and GND3 pins were accidentally reversed
    on the silkscreen.
    [Display.sch]
2021-06-03 generate hsync
    Kind of works, but there seems to be a lot of unexpected
    jitter.
2021-06-04 try to use external 12 MHz oscillator
    still not working :-(
    [up5k.pcf]
2021-06-04 rename Experiment03 to Experiment04
    We need to get the clocking issues figured out before
    it will be productive to worry about generating VGA
    signals.
    [up5k.pcf]
2021-06-04 successfully use external oscillator
    Dividing external 12 MHz oscillator signal by 2 yields a
    6 MHz square wave. This appears to be rock solid, and free
    from the jitter which is seen when using the internal
    high frequency oscillator as a clock.
    [up5k.pcf]
2021-06-04 generate 240 MHz clock from external 12 MHz clock
    Dividing the 240 MHz clock by 128 yields a rock solid
    1.875 MHz square wave. Hopefully this means we can
    generate VGA signals without all of the jitter we were
    getting from the internal high-frequency oscillator.
    [up5k.pcf]
2021-06-05 generate vsync and pixel colors
    Vsync looks correct on the scope.
    Pixels are just a solid color for the moment.
    [up5k.pcf]
2021-06-05 connect 12 MHz clock to GPIO 20
    The internal high-frequency oscillator is not very accurate,
    and has significant jitter.
    [Display.sch]
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2021-06-07 create right bracket as mirror of left
    The left bracket seems to work perfectly on the CPU
    and glue logic PCB. Hopefully with both brackets installed,
    the backplane connector will have a bit more mechanical
    stability.
    [bracket.scad, bracket.stl, right_bracket.stl]
2021-06-08 bugfix: GND and VCC were reversed on the backplane connector
    Took the opportunity to fix other minor details on the
    CPU and glue logic PCB, such as a missing component value
    on the silkscreen, the pull-up resistors for the IRQ
    inputs being too close to the backplane clip, and
    the header for the external reset switch being a little
    too close to the top of the board (insetting it a bit
    is more appropriate if a right angle connector is
    installed.)
    [CPUandGlueLogic.kicad_pcb, F68.sch]
2021-06-10 route ~IODEV0 through ~IODEV4 to backplane connector
    For some reason, the pins of the 74HCT138 weren't labeled
    with the same nets as the corresponding pins on the backplane
    connector, even though they have continuity on the schematic.
    [CPUandGlueLogic.kicad_pcb]
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2021-06-12 all non-GND signals routed
    Removed all explicit traces/vias for GND, since there
    will be a ground plane on both layers.
    [MemoryAndPeripherals.kicad_pcb]
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2021-06-12 routed a couple of missed VCC nets
    [InterruptAndKeyboard.kicad_pcb]
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2021-06-12 fixed a couple missing connections
    [InterruptAndKeyboard.kicad_pcb]
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2021-06-23 re-routed E signal
    Avoid trying to cram 3 traces between IC pins. Also,
    regenerated ground planes on both layers.
    [MemoryAndPeripherals.kicad_pcb]
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2021-06-24 fixed a minor ambiguity
    [Display.sch]
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2021-08-18 make sure clips are in the correct orientation
    [bracket.scad, bracket.stl, right_bracket.stl]
2021-08-18 fix unrouted net to pin 18 of 82C54
    [MemoryAndPeripherals.kicad_pcb]
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2021-09-20 more tweaks/fixes to FIFO/FPGA interface
    [Display.sch]
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2021-12-22 revert to original code, rename as Experiment01
    [up5k.pcf]
2021-12-22 implemented synchronous reset, untested
    [up5k.pcf]
2021-12-23 initial experiment to add a reset input
    For some reason, the entire design doesn't work unless the
    input signal is written to an output register connected to
    a GPIO pin. I have no idea why this is necessary.
    [up5k.pcf]
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2021-12-27 reset data values on manual reset
    [ArduinoSketch.ino]
2022-01-01 this actually seems to work at 159 MHz!
    There were significant stability issues with the main
    clock at 240 MHz. I'm guessing there were timing
    constraints inside the design that weren't being met.
    159 MHz is close enough to 160 MHz to divide by 4
    and get something close enough to 40 MHz to generate
    almost-within-spec 800x600 SVGA.
    [up5k.pcf]
2022-01-02 complete rewrite of Arduino sketch
    The manual reset button now completely resets the
    data generation.
    Added a hack so that only one data value is written.
    I was debugging an issue where the empty flag wasn't
    re-asserted after reading a single data value, which
    obviously caused major problems for the read logic
    in the FPGA.
    [ArduinoSketch.ino]
2022-01-02 added next_read_state register
    Updating read_state as a computation based on its current
    value is not working currently. However, computing a new
    next_read_state value, and then copying it back to read_state
    on a negative clock edge, seems to work (?)
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2022-01-03 update read_state directly
    This now seems to work somewhat reliably! Presumably
    making the tick counter 16 bits enables the use of a
    hardware adder, which is reducing latency somewhere.
    The generated video signal is sometimes jittery, and this
    seems to be reset-dependent.
2022-01-03 send bytes to the command FIFO frequently
    I think I have the reading logic working correctly
    in the FPGA?
    [ArduinoSketch.ino]
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2022-01-15 generate pixels from buffer in block RAM
    Reading from the block RAM seems to work fine.
    However, when the command code tries to write to the
    block RAM, icestorm fails to infer that the memory
    should be a block RAM. (Actually, I'm not 100%
    confident that it's inferring this correctly in the
    case where there are only reads from the buffer.)
    More investigation needed.
    [ArduinoSketch.ino, up5k.pcf]
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2022-07-03 working on command loop, has some bugs
    For now, we're just trying to read data from the FIFO
    and interpret as a command byte followed by one or more
    data bytes. The state machine doesn't seem to work correctly,
    because the transition from recognizing a valid command byte
    to processing its associated data byte doesn't seem to be
    handled correctly.
    Added a couple of debug LEDs to the Upduino to make it easier
    to see what is going on.
    [ArduinoSketch.ino, up5k.pcf]
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2022-07-03 more debugging
    Specifically, demonstrated that the problem is that data
    associated with a command is getting interpreted as a command.
    This appears to happen on the first data value received
    (associated with the CMD_PIXDATA command.)
    [ArduinoSketch.ino, up5k.pcf]
2022-07-03 modified shared_reg so that has_data is cleared eagerly
    This fixes an issue where the consumer would see the
    data in the shared register twice. (I think!)
    [ArduinoSketch.ino]
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2022-08-14 start experiment 6 (fix character placement issues)
    [ArduinoSketch.ino, up5k.pcf, vga_font.ino]
2022-08-14 more debugging of character placement
    Verified that the last 256 bytes of the character RAM
    can be read, by loading different data into it than
    the first 256 bytes.
    It's clear that the first two columns of characters
    aren't displayed correctly. My suspicion is that ch_col
    and ch_row aren't being updated properly.
    [ArduinoSketch.ino]
2022-08-14 still trying to track down alignment issues
2022-08-14 experiment to try to figure out sync and alignment issues
    [up5k.pcf]
2022-08-20 relocate font data to SPRAM: not working yet
    [ArduinoSketch.ino]
2022-08-21 attempting to rewrite command processing
    Goal is to cleanly split the handling of command vs.
    data bytes, vs. running a state machine in response to
    a received command.
    The idea is that there is now a separate state machine for
    each command type, and the main data reception loop sends
    bytes via a shared_reg.
    Very much not working at the moment, and it doesn't
    even seem to properly separate command vs. data bytes.
    [ArduinoSketch.ino, up5k.pcf]
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2023-01-03 Episode 1D won't be the FPGA-based display
    It will be a TMS9918A-based display
    [ArduinoSketch.ino, up5k.pcf, vga_font.ino]
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2023-01-06 fix connections to data bus
    TI stupidly uses "CD0" to mean the *most* significant bit of
    the data bus, which is completely backwards.
    [TMS9918ADisplay.kicad_sch]
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2023-01-11 fix typo
    [YM2149_Sound.kicad_sch]
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2023-01-12 fix some footprint assignments
    [F68.kicad_sch, TMS9918ADisplay.kicad_sch, YM2149_Sound.kicad_sch]
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2023-02-11 fix typo on silkscreen
    [TMS9918A_YM2149.kicad_pcb]
2024-07-18 working on vga text mode routines
    In progress, won't assemble or run yet.
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2024-07-20 attempt to implement bulk copy to VRAM
    Doesn't really work. Probably would be best to
    start with a simpler approach that doesn't try to
    handle bank switching transparently.
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2024-07-20 add hwvga_write_dumb function
    Writes characters using the current attribute. Doesn't
    handle bank switching at all.
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2024-07-24 starting footprint assignment
    Changed oscillator module to KiCad-provided 7050.
    (Need to check whether the footprint will work with the
    SG636P oscillators I'm using. (I think it will, but I
    need to measure.)
    [HCount.kicad_sch, HW_VGA.kicad_sch, Pixgen.kicad_sch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]
2024-07-24 add bypass cap for oscillator module
    [HW_VGA.kicad_sch]
2024-07-24 attempt at footprint for SG-636P oscillator module
    From datasheet at
    https://www.mouser.com/datasheet/2/137/SG_636PCE_en-1003252.pdf
2024-07-24 fixed designators for decoupling caps
    [Pixgen.kicad_sch]
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2024-07-24 fixed an incorrect footprint assignment
    [HW_VGA.kicad_sch]
2024-07-24 fixed another incorrect footprint assignment
    [VRAM.kicad_sch]
2024-07-24 fixed wiring of VGA output connector
    [HW_VGA.kicad_sch]
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2024-07-27 fixed one isolated ground
    [HW_VGA.kicad_pcb]
2024-07-27 fix more unconnected grounds
    [HW_VGA.kicad_pcb]
2024-07-27 fixed a missing signal
    [HW_VGA.kicad_pcb]
2024-07-27 fixing more unrouted ground connections
    [HW_VGA.kicad_pcb]
2024-07-27 fixed more unconnected ground plane fragments
    [HW_VGA.kicad_pcb]
2024-07-27 fixed a couple of unconnected host address lines
    [HW_VGA.kicad_pcb]
2024-07-27 routed unconnected -RST traces
    Somehow KiCad failed to include these in the rats nest.
    [HW_VGA.kicad_pcb]
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2024-07-27 routed another missing VRAM signal
    [HW_VGA.kicad_pcb]
2024-07-27 fix another unrouted VRAM signal
    There were more of these than I expected.
    [HW_VGA.kicad_pcb]
2024-07-27 fix yet another unrouted VRAM signal
    [HW_VGA.kicad_pcb]
2024-07-27 all serious DRC errors fixed!
    All traces routed, all fill regions connected to ground.
    In theory this could be a functional PCB.
    [HW_VGA.kicad_pcb]
2024-07-27 fixed silkscreen clipping in SG-636P footprint
    [HW_VGA.kicad_pcb]
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2024-07-29 show oscillator frequency on front silkscreen
    [HW_VGA.kicad_pcb]
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2024-08-01 bugfix: ReadoutA0 wasn't connected
    A wire was misplaced on the main sheet, which meant
    that the ReadoutA0 input of the VRAM module had no
    connection to the ReadoutA0 output from the Readout
    module.
    This will require a bodge wire on the 29-Jul-2024
    version of the PCB, but fortunately it will be a very
    easy one, since the 74ALS163 that generates ReadoutA0
    is on the bottom of the PCB and can be easily connected
    to the appropriate pin on either VRAM PLCC socket.
    [HW_VGA.kicad_pcb, HW_VGA.kicad_sch]
2024-08-01 regenerate DisplayController gerbers
    This version shoud be fully routed, and shouldn't
    require a bodge (although who knows, I haven't
    received the PCBs for the 29-Jul-2024 version of
    the PCB yet.)
    [HW_VGA-B_Mask.gbs, HW_VGA-B_Silkscreen.gbo, HW_VGA-Back.gbl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]
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2026-01-09 HSync/VSync were reversed on FPGA & VGA connector
    [FPGADisplayController.kicad_sch]
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
